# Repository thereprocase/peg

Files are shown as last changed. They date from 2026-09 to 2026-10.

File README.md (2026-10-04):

# Pegboard connectors and holders

**[Get the current peg downloads](https://thereprocase.github.io/peg/)** — native hook, hoop and bearing-locator CAD with a flat mounting reference and a **2 mm joining nub, +20% diameter**. Six individual connectors and pre-spaced pairs use the current PF02 #9 / PF07 #5 fit. Their functional board-side shapes are unchanged.

| Download | Intended use |
|---|---|
| [STEP pack](https://github.com/thereprocase/peg/releases/download/peg-connectors-v1-2026-10-04/pegs-current-fit__v1__nub120__step.zip) | Native solids for Fusion, Onshape and other solid modelers |
| [FreeCAD pack](https://github.com/thereprocase/peg/releases/download/peg-connectors-v1-2026-10-04/pegs-current-fit__v1__nub120__FCStd.zip) | Native solids and named holder datum planes |
| [All formats + construction source](https://github.com/thereprocase/peg/releases/download/peg-connectors-v1-2026-10-04/pegs-current-fit__v1__nub120__all-formats-and-source.zip) | STEP, FCStd, BREP, IGES, STL, OBJ and geometry-only 3MF |

Align the flat shoulder at **Y = 0.15 mm** to the holder's rear plane, embed the nub toward **+Y**, and Boolean union it into the body. Nub diameter is **6.72 mm** on the upper hook and **7.62 mm** on the lower parts. All dimensions are millimeters. Native solid exports preserve arcs and surfaces; STL/OBJ/3MF are separate tessellations. [Full integration notes](docs/pegs/integration.txt) · [Native build and validation](bench/reviews/peg-connectors-v1/BUILD.json).

**[Browse all 44 holder designs](https://thereprocase.github.io/peg/gallery/current-pegs/)** · [New bench designs](https://thereprocase.github.io/peg/gallery/current-pegs/?family=new) · [36-hole screwdriver remix](https://thereprocase.github.io/peg/gallery/current-pegs/#P09-36) · [Current fit / printing rules](BENCH_HOLDERS.md).

The original nominal anchor study is preserved below and on its [own page](https://thereprocase.github.io/peg/anchor-study/). Its movement certificates do not cover the current interference-fit connectors or complete holders. The new exports pass native solid round-trips, unchanged board-side geometry checks and sample host unions; physical fit and loads depend on the finished print and board.

---

# Original nominal conformal anchor study

A reusable rear attachment for holders, bins and brackets on **6.35 mm (1/4-inch) holes at 25.4 mm (1-inch) pitch**. Both pegs match the bore's lower curve over **120 degrees**. The lower peg bears through the full **3.94 mm board thickness**. A sharp **5 mm nominal lip above the upper hole center** sits flush against the board; taller attached parts can take any shape inside the supplied movement envelope.

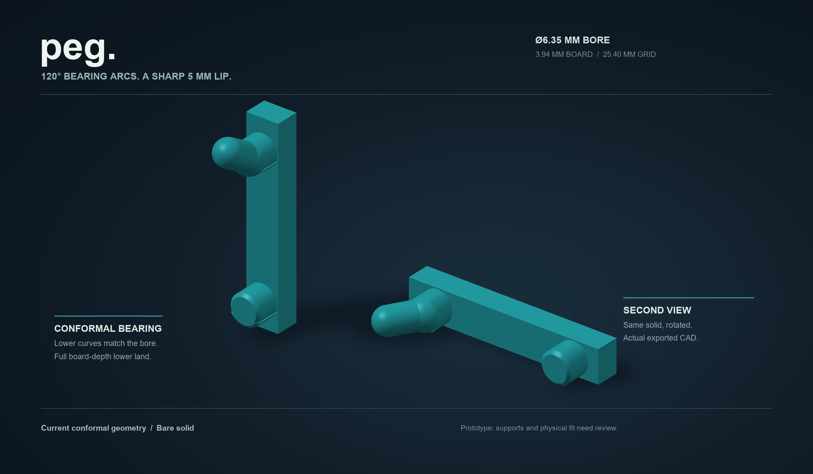
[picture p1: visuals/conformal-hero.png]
Current conformal anchor, rendered from the exported CAD


**Start with the [functional STEP](cad/conformal/conformal_120.step?raw=1) and [allowed host volume STEP](cad/conformal/host-envelope/allowed_host_volume.step?raw=1).** Import them together to build an attached part. The current geometry has its own continuous movement verification and independent solid-model checks. Its bare meshes are inputs for print preparation; supports, slicing and physical fit still need qualification.

## Current downloads

| Use | File | Contents |
|---|---|---|
| Integrate the attachment into CAD | [Functional STEP](cad/conformal/conformal_120.step?raw=1) | One solid in anchor design coordinates |
| Define the attached part's permitted shape | [Allowed host volume STEP](cad/conformal/host-envelope/allowed_host_volume.step?raw=1) | Reference volume derived from this anchor's movement; do not print or fuse the volume |
| Prepare a side print | [Bare side STL](cad/conformal/conformal_120_side_unsupported.stl?raw=1) | Functional geometry in side orientation; needs a checked support strategy |
| Prepare an upright print | [Bare upright STL](cad/conformal/conformal_120_upright_unsupported.stl?raw=1) | Functional geometry in upright orientation; needs a checked support strategy |
| Inspect without reorientation | [Design-coordinate STL](cad/conformal/conformal_120_design_unsupported.stl?raw=1) | Mesh aligned with the STEP and host envelope |
| Change procedural dimensions | [conformal_anchor.py](conformal_anchor.py) | CadQuery source, geometry contract and exporters |

## Bearing geometry

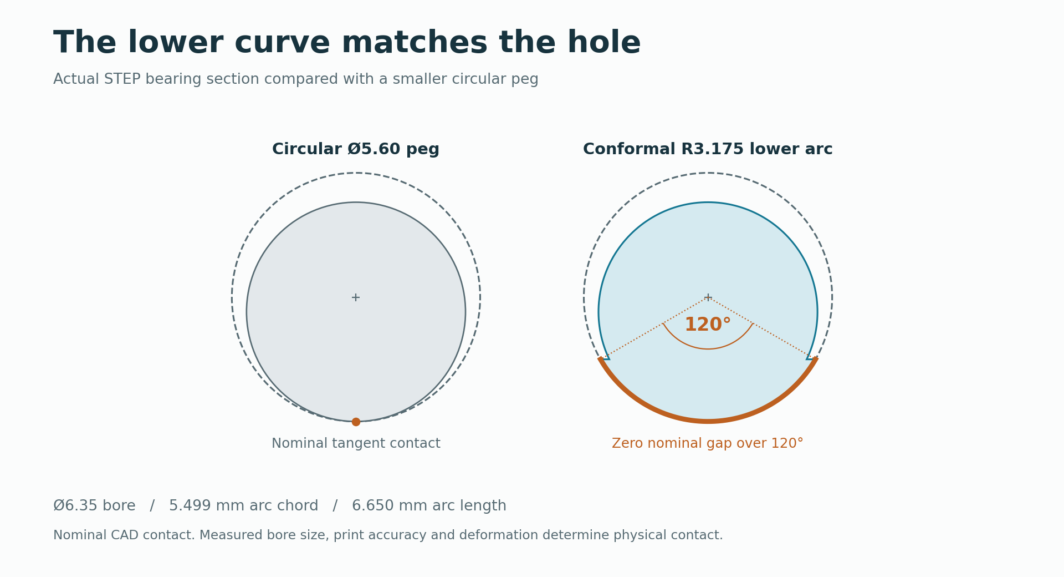
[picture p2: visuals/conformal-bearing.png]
Circular and current bore-matching bearing cross-sections


Each peg has an actual **3.175 mm-radius cylindrical arc** along its bottom. When seated in the nominal bore, the curved bearing surfaces coincide over 120 degrees. The upper circular core and smaller retaining tongue provide the threading geometry.

| Feature | Current default |
|---|---:|
| Actual board thickness / hole diameter / pitch | **3.94 / 6.35 / 25.4 mm** |
| Conformal bearing radius / arc coverage | **3.175 mm / 120 degrees** on both pegs |
| Upper conformal bearing length | **3.158095 mm** |
| Lower conformal bearing length | **3.94 mm**, full board thickness |
| Lower nose beyond the rear board face | **0.50 mm** axial chamfer |
| Lower total projection from the installed board front | **4.44 mm** |
| Upper circular core / retaining tongue diameter | **5.60 / 4.80 mm** |
| Front spine width / design-coordinate fusion face | **6.00 mm / Y = 4.50 mm** |
| Nominal flush lip above the upper hole center | **5.00 mm** |
| Board-facing corner radius | **0 mm**, sharp planar seam |

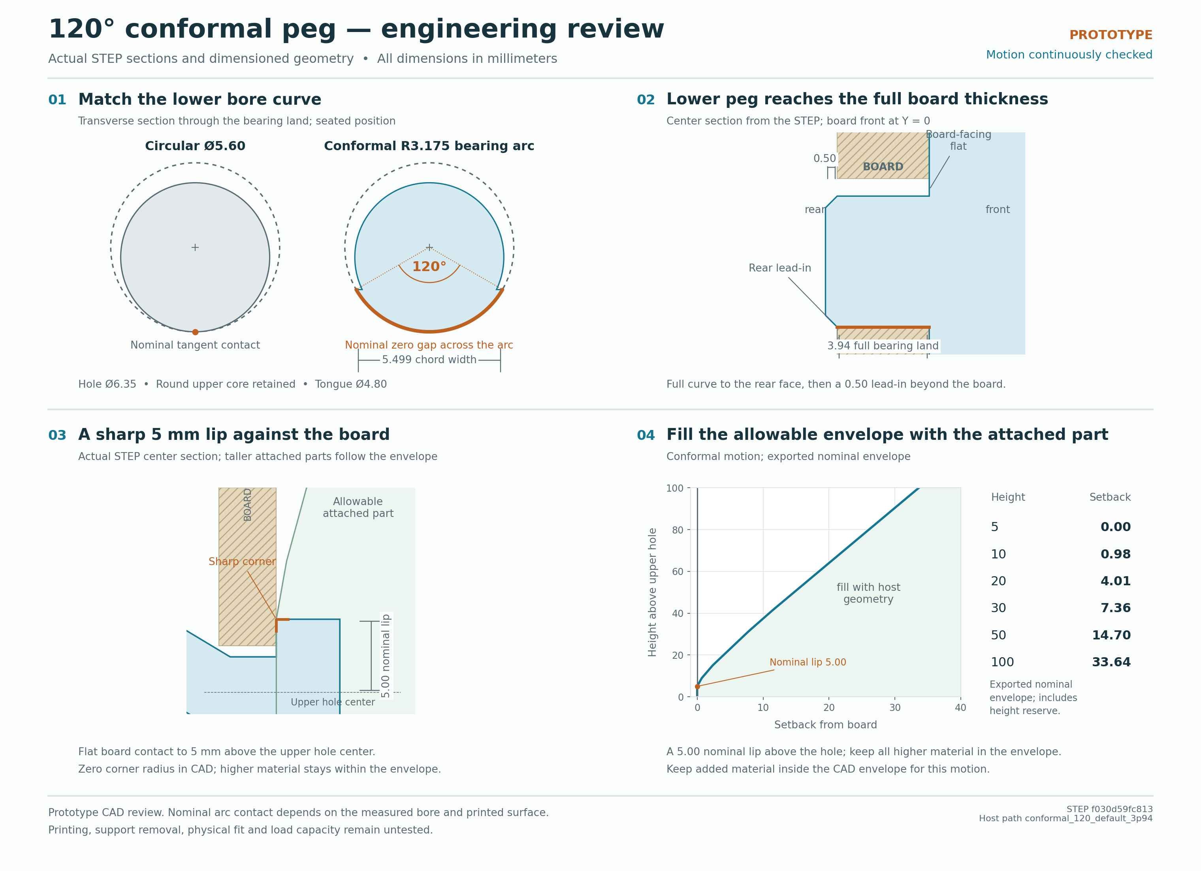
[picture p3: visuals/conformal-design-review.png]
Current dimensioned anchor and host interface


The upper conformal land stops at the retaining bend to permit the verified insertion. The lower peg spans the whole board: its 0.50 mm nose begins beyond the rear face, after the full bearing land.

The lower land's nominal mating area is **26.20 mm2**. This is geometric area, not measured contact pressure or a load rating. Exact full-arc contact depends on the real bore, printed surface and deformation. Measure board thickness and several holes before preparing a fit sample. Other board sizes require their own geometry and movement checks.

## Integrate with custom parts and models

The 5 mm dimension is measured **above the upper hole center**, not above the peg's crown and not from the bottom of the holder. It defines the nominal maximum height of a board-flush rear face. Above it, move the back of the attached part forward according to the allowed volume. A tall tool holder can use a step, slope, ribs or any other shape that fits.

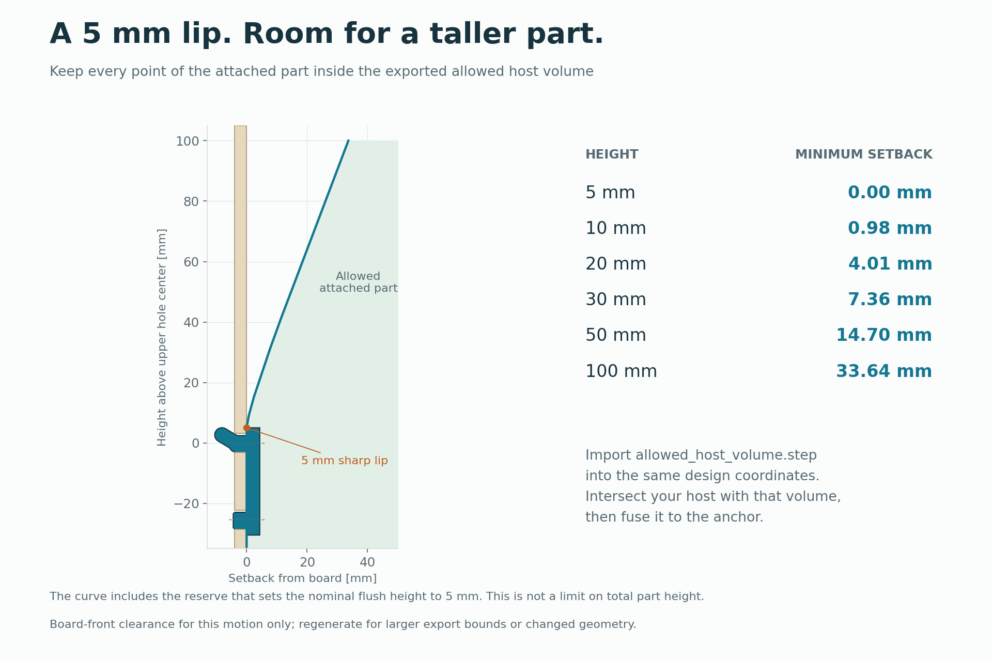
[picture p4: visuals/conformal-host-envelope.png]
Allowed attached-part volume and required setback above the sharp lip


Import the two STEP files in the same coordinates. Create the added host entirely inside the allowed volume, then fuse it into the anchor's front spine with real shared volume. Include all added ribs and fasteners in the containment check. The anchor's own pegs intentionally lie outside the host envelope.

The supplied reference volume spans **X = -50 to +50 mm**, installed height **-80 to +100 mm**, and front projection **60 mm**. These are export bounds, not a limit on the mathematical interface; the generator accepts larger bounds. The envelope checks the complete board front throughout the same movement as the peg. It does not account for neighboring holders, rear walls or hand access.

All dimensions are millimeters. **X** runs across the board, **Y** points toward the user, and **Z** points up. The board front is **Y = 0**; its hole centers are **Z = 0 and -25.4 mm**. In the supplied CAD, the spine's front fusion face is **Y = 4.50 mm**, the board-facing back is **Y = 0.15 mm**, and the nominal lip is **Z = 5.12 mm**. The seated assembly translates **Y = -0.15 mm, Z = -0.12 mm**, with zero rotation.

In Fusion, Onshape or another solid modeler:

1. Import the functional STEP and allowed-volume STEP without moving either independently.
2. Model the added part inside the allowed volume. Above the 5 mm lip, follow the rear setback boundary. Extend the part into the spine's front face with real overlap; 0.3 mm is a useful Boolean construction starting point.
3. Check that subtracting the allowed volume from the added part leaves no material, then union the host and functional anchor. Keep the reference envelope out of the finished model.
4. Inspect the complete assembly along the supplied motion and confirm clearance from nearby objects. Use the seated transform when checking its final position on the board.

For procedural CAD, this complete example clips a tall host blank to the allowed volume and fuses it to the default anchor:

```python
import cadquery as cq
from conformal_anchor import make_conformal_anchor

anchor, geometry = make_conformal_anchor()
allowed = cq.importers.importStep(
    'cad/conformal/host-envelope/allowed_host_volume.step'
)
# 24 mm wide, 24 mm deep, 65 mm tall; starts at design Y = 4.2 mm.
blank = cq.Workplane('XY').box(24, 24, 65).translate((0, 16.2, 2.5))
host = blank.intersect(allowed)

outside = host.cut(allowed)
assert sum(s.Volume() for s in outside.solids().vals()) < 1e-6
assembly = anchor.union(host)
assert assembly.val().isValid() and len(assembly.val().Solids()) == 1
cq.exporters.export(assembly, 'my_holder.step')
```

Replace the blank with your own model, using the envelope to check or shape its back. To change peg dimensions, pass a parameter dictionary such as `make_conformal_anchor(overrides={'board_thickness': 4.19})`; regenerate and verify that geometry's movement and host envelope before using it. The supplied certificates cover the default dimensions only.

See [HOST_INTERFACE.md](HOST_INTERFACE.md) for the exact movement-dependent height ceiling, containment rule and regeneration options.

## Installation and removal

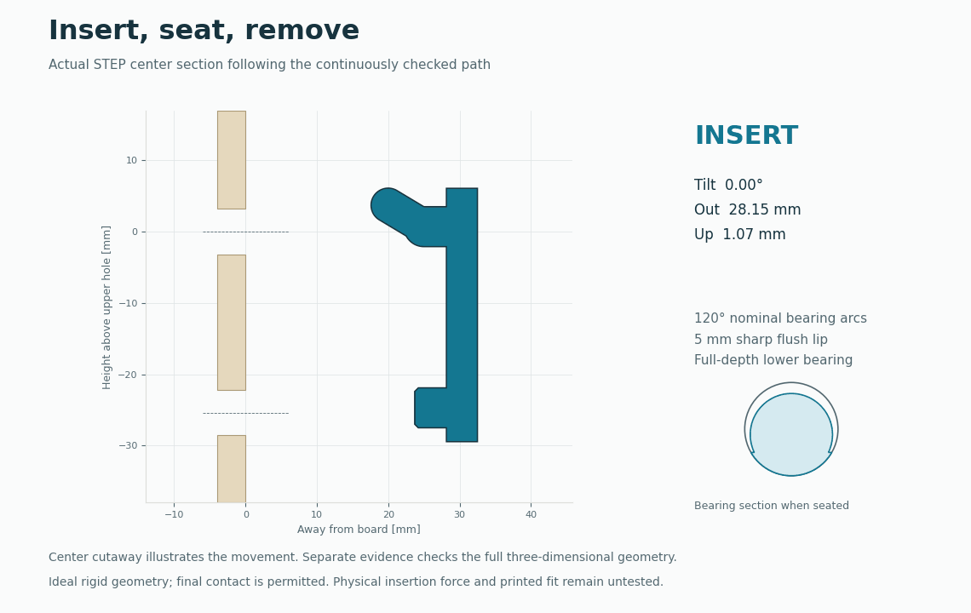
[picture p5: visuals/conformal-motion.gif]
Insertion and removal using the current CAD and certified pose sequence


Thread the upper tongue while tilted, rotate the holder toward the board as the lower peg enters its hole, then close the intended bearing contacts. Removal reverses the same path. The maximum installation tilt is **20.875 degrees** and the reference-point lift is **1.07 mm**.

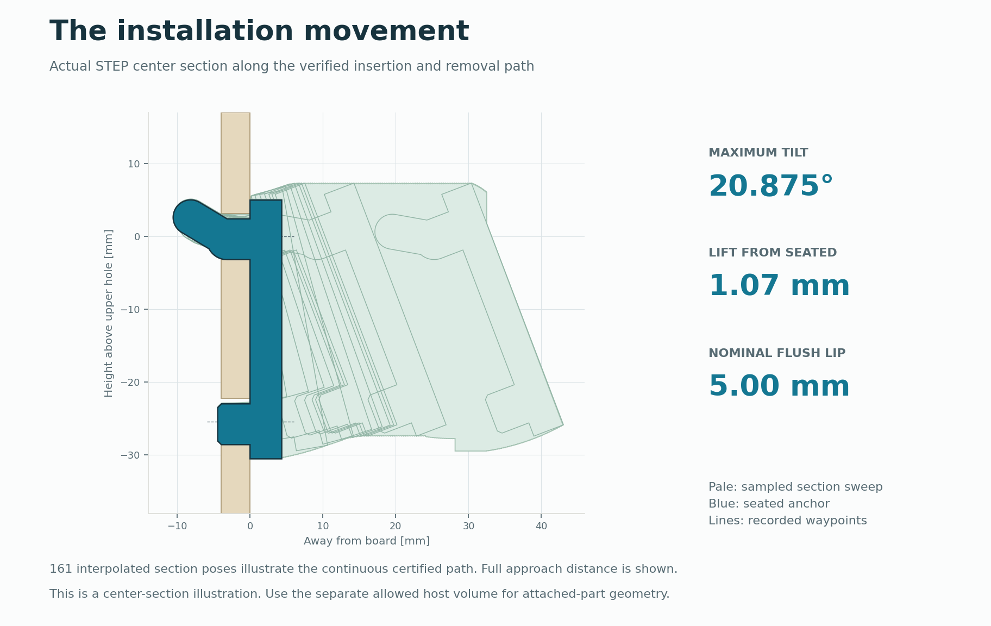
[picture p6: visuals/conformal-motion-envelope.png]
Projected swept shape of the current installation motion


The [movement study](CONFORMAL_STUDY.md) certifies **12 waypoints** with **168 continuous interval certificates across 10 free-motion segments**, plus **one exact final-contact translation**. The bounds use 768 X slabs per half for the curved additions. An independent OpenCascade audit of the exported solid found **zero overlap at 400 path poses**, including seating. The animation follows the certified pose sequence.

The current proof uses the **physical nominal bore** and permits the intended seated contacts. It reserves no additional radial bore clearance. The result establishes ideal rigid geometry clearance; actual printed fit and insertion feel need a physical sample. No load, fatigue, creep or support-release rating has been established.

## Print preparation

The current side and upright STLs contain **only the functional anchor**. Build and check supports for the selected orientation and the complete attached holder. The projecting tongue and full-depth lower peg need a support strategy that preserves their functional surfaces.

Use the intended printer and filament profile, inspect the first appearance of each projection and the bearing surfaces, then print one fit sample. Preserve the 120-degree bearing curves and sharp board-facing seam when removing supports. Fit trials and a representative holder test are the next qualification steps.

## Sources and evidence

| Record | What it establishes |
|---|---|
| [Resolved geometry](cad/conformal/conformal_120_geometry.json) | Dimensions and exact construction used by the CAD and motion checker |
| [Exported bearing-face check](cad/conformal/conformal_120_bearing_check.json) | Measured radius, 120-degree coverage and bearing lengths from STEP |
| [Solid and mesh validation](cad/conformal/conformal_120_cad_validation.json) | One valid solid and watertight, positive-volume meshes |
| [Continuous motion](cad/conformal/conformal_motion_results.json) | Input hashes, poses, interval certificates and final-contact proof |
| [Independent STEP intersections](cad/conformal/conformal_motion_check.json) | Sampled solid-model interference checks |
| [Allowed-volume certificate](cad/conformal/host-envelope/allowed_host_volume.json) | Host boundary, export bounds and continuous board-front clearance |

Use the [Python requirements](requirements.txt) or an already available compatible CAD runtime; the validation record identifies the versions actually used. Rebuild the current geometry and its dependent evidence in this order:

```text
python conformal_anchor.py
python check_conformal_geometry.py
python conformal_motion.py --certify --slabs 768 --max-seconds 180
python verify_conformal.py --candidate-poses 400 --max-seconds 600
python host_envelope.py --motion cad/conformal/conformal_motion_results.json --output cad/conformal/host_envelope.json
python export_host_envelope.py --motion cad/conformal/conformal_motion_results.json --output cad/conformal/host-envelope --nominal-lip 5
python render_conformal.py
python render_conformal_media.py
```

[HANDOFF.md](HANDOFF.md) records source ownership and publication checks. [research.md](research.md) records the board-size research.

## Graveyard

[Previous round release and its supported 3MF](ROUND_README.md) / [rectangular baseline](BASELINE_README.md) / [design history](DESIGN_HISTORY.md). Their CAD, supports and evidence belong to those older shapes.

## Project website

[Open the Conformal pegboard anchor site](https://thereprocase.github.io/peg/) for previews, setup and project resources. [Browse all project groups](https://thereprocase.github.io/).

The static site lives in `docs/` and uses the shared [Gridline design system](https://github.com/thereprocase/thereprocase.github.io/blob/main/GRIDLINE.md). Edit `docs/index.html` and `docs/site.js`; shared styles live in `docs/gridline/`. GitHub Pages serves `main:/docs`.

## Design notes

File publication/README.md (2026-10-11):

# Publishing the curated gallery

Canonical public front page: https://thereprocase.github.io/peg/
Current holder collection: https://thereprocase.github.io/peg/gallery/current-pegs/
GitHub Pages builds `main:/docs`. `docs/gallery` contains the static gallery, local scripts and 3D media. CAD STEP/FCStd, ZIP bundles and 3MF print jobs are GitHub Release assets. `release-downloads.json` maps original relative paths to immutable release URLs, including compatibility aliases; `release-assets.json` records exact SHA256 and size.

Preserve four groups, tombstones, Pegstr credit, model-specific limitations, explicit part/version filenames and private-data exclusions. This migration imported ONLY the previous public allowlist, recorded in gallery-source-manifest.json. No votes, photos, databases, credentials, workspace history or machine caches were imported.

For the next model: generate/review locally, stage only its approved public additions, upload versioned binary downloads to a new release, update the scoped gallery page, `release-downloads.json` and the matching `docs/gallery/release-downloads.js` map, run `python tools/check_gallery.py`, review the diff and push. Verify Pages and real downloads before changing links on another host. Never rerun the retired PVE publication scripts.

Offline: clone/download this repository and serve `docs` with a local static server for 3D. Pages and renders are local; release downloads require internet. Model/source ZIPs remain self-contained and unchanged.

Warpbus now keeps legacy redirects only, following GitHub verification. Historical immutable Warpbus snapshots are rollback evidence, not the publishing target.

## October 4 current-mount collection

`bench/reviews/gallery-current-mounts-flat-top-v2/SELECTED.json` selects 38 mounted gallery bodies: 19 planar-top Pegstr/arrays and 19 other holders with per-part poses. `verify_selection.py` validates the frozen source, native exports and checks. Do not regenerate frozen exports just to package them; native serialization hashes may change. P06 uses its bounded mesh-export adapter.

`prepare_current_pegs_media.py --selection SELECTED.json` converts the selected installed/print meshes to GLB. `build_current_pegs.py BUILD_DIR RELEASE_DIR --selection SELECTED.json --tag RELEASE_TAG --generation-source-map SOURCE_MAP.json` packages 114 native/source release assets and writes the catalog, receipts and redirect map. The generation-source map is local build state; the ZIPs preserve exact execution code and public provenance. Each bundle retains its true original input suffix, any original STEP/STL ancestry, the shared fit snapshot, native CAD, meshes and review evidence.

Run `python3 tools/check_gallery.py`, check the actual mobile/desktop viewer and both poses, review scoped staged paths, refresh `release_manifest.json`, upload immutable release assets, then publish the matching Pages commit. No current G-code or sliced job is included. Historical loose parts and print jobs remain in their original galleries. Print support/toolpath and changed-fit physical qualification are separate from the recorded CAD checks.

## Featured connector downloads

The front page features six current-fit connector/pair variants with +20% diameter, 2 mm holder-side joining nubs. `bench/source/peg_connectors_v1/build.py` constructs native solids and datum planes from the unchanged fit snapshot. Native STEP/BREP/IGES round-trips, unchanged board-side geometry and a sample host union are checked during generation. IGES topology is sewn for its solid comparison. Meshes are tessellated directly from the native solids without mesh repair.

`build_peg_downloads.py RELEASE_DIR` packages STEP, FCStd, BREP, IGES, STL, OBJ and geometry-only 3MF, plus all-format/source bundles. Native exports remain GitHub Release assets; `docs/pegs` holds the catalog, display GLBs and integration notes. `peg-connectors-v1-additions.json` records release/local receipts. Run `tools/check_peg_downloads.py` (also included in the gallery check) and review the actual front-page viewer before publishing. The original nominal study stays at `/peg/anchor-study/`; its CAD and certificates are unchanged.

## Workbench previews

`docs/viewer/workbench.js` applies four-band cel shading, a bright workbench background and soft ground shadows to the interactive viewers. The adapter uses the pinned model-viewer build's `correlatedObjects` material set and scene render request; verify these hooks when upgrading that vendor bundle. CAD, GLB geometry and downloadable materials retain their original bytes.

`render_workbench_previews.cjs` regenerates the current collection's installed, print and thumbnail PNGs from the same shader. Serve `docs`, set `PEG_PREVIEW_URL` to that server, and run with Playwright available via `PLAYWRIGHT_MODULE` and Chromium via `CHROMIUM_PATH`. Refresh the current-pegs receipts after rendering. Check viewer material application and browser/WebGL errors across model swaps before publishing.

CF01 v3 is a Repro bespoke catalog entry in `current-pegs` (solder-modules family). `add_cascade_to_collection.py` registers its slim-web revision, reviewed media, downloads, notes and front-facing camera. Apply it after rebuilding the base collection, then render only this entry with `PEG_PREVIEW_IDS=CF01` using `render_workbench_previews.cjs` and refresh the collection receipts. The standalone cascade page remains the detailed review linked from the catalog entry.

HX02 v1 is the full-depth 30-degree metric hex-key rack in Repro bespoke. `build_canted_hex_keys.py` publishes its matching model, evidence and catalog entry; `package_canted_hex_keys.py` packages native CAD and exact sources. Render its catalog previews with `PEG_PREVIEW_IDS=HX02`, refresh the collection receipts, and run the gallery checks before publishing.

HX02 v2 (graduated organ-pipe hex-key rack) replaces v1 on the canted-hex-keys page and in the Repro catalog; v1's print STL and CAD release stay linked as history. `bench/source/canted_hex_keys_v2/build.py` builds it (FreeCAD 1.1 with scipy; `--quick DIR` writes review meshes only), then `review.py`, `install_screen.py`, `stiffness.py`, `slice_local.py` (Windows OrcaSlicer, flattened system P1S/0.20 mm presets plus the owner's PolyLite ASA ReproCal filament) and `toolpaths.py` write the evidence. `build_canted_hex_keys_v2.py` publishes page, catalog and receipts; `package_canted_hex_keys_v2.py` makes the release bundle (`canted-hex-keys-v2-2026-10-07`). Render catalog previews with `PEG_PREVIEW_IDS=HX02` and refresh the receipts; `tools/check_canted_hex_keys_v2.py` runs from the gallery check.

HX04 v1 (three-tier key fan: hex L-keys back, Torx middle, Bondhus T-handles front) is a new Repro bespoke entry with its own page, `docs/gallery/key-fan/`. `bench/source/key_fan_v1` holds the layout study (`study/short.py`, final layout `short_dt_c2.json`) and the FreeCAD 1.1 model (`build_short.py`). Run it with the build env recorded in `report.json`. `check.py` (exact storage and withdrawal), `fea_run.py`, `coupon.py` and `tools/run_candidate.sh` write the evidence; `tools/evidence.py` collects it into `bench/reviews/key-fan-v1/HX04`. `build_key_fan.py` publishes the page, catalog entry and receipts. `package_key_fan.py` makes the release bundle and the solid-zone 3MF project (`key-fan-v1-2026-10-08`). Render catalog previews with `PEG_PREVIEW_IDS=HX04` and refresh the receipts; `tools/check_key_fan.py` runs from the gallery check. The fit coupon STL ships on the page; no G-code is published.

HX04 v2 replaces v1 on the key-fan page and in the Repro catalog. It puts a peg in every hole the plate covers: PF02 #9 hooks across the top row, PF07 #5 locking hoops across the bottom row and lower bearing pegs between, 90 in all, on the reviewed 5.4 mm wall (`receiver_grid` in `build_short.py`). The solid-infill zones are now braces: socket row webs, socket bulkheads and peg-root discs. `swing.py` adds the sampled install-swing evidence. Build v2 evidence with `HX4_VERSION=2 tools/evidence.py`, publish with `build_key_fan_v2.py` and package with `HX4_VERSION=2 package_key_fan.py` (`key-fan-v2-2026-10-08`). v1's print STL stays on the page and its bundle on the v1 release; `tools/check_key_fan.py` checks v1 as history and `tools/check_key_fan_v2.py` the current model.

The extended HX04 audit is separate from the immutable v2 geometry: `bench/source/key_fan_audit_v1/`, `bench/reviews/key-fan-audit-v1/` and `docs/gallery/key-fan/studies/`. `build_report.py` builds numerical tables and scientific plots from completed receipts. `publish_key_fan_audit.py --out RELEASE_DIR` verifies the completed-film archive, packages public sources/fields/native CAD, updates immutable downloads and applies the scoped page/catalog overlay. The base v2 publisher calls this overlay last. Preserve the original v2 artifacts and failed-run disclosures. Run `tools/check_key_fan_audit.py` and the full gallery check, inspect actual desktop/mobile renders, refresh the root manifest, and verify release payloads and live Pages. Printer jobs and private settings remain outside publication.

## Final straight-socket racks

The selected green Bondhus 13190 fan also has an editable native FreeCAD handoff at `/gallery/key-fan/stacked/green/#parametric`. `bench/source/hx05_parametric_v1` contains its stdlib-only feature module, one-time setup macro, document builder, edit/reopen tests and release packager. Two spreadsheet sheets drive the fan geometry; the approved rear mount stays fixed. `package.py WORK_DIR` packages tested files and receipts; the green publisher reapplies `publish_download.py` so the download section survives regeneration. CAD binaries remain immutable release assets. Parameter edits invalidate the previous layout/printing evidence.

`bench/source/final_racks_v1` builds the revised owner fan and three single-set Bondhus racks. Owner-selected 3C/5C clearance is +0.38 mm total AF; other sizes remain provisional. Saved final layouts, native checks, separate lead-ins and vent passages replace the flared seats. `publish_final_racks.py --build BUILD_DIR --out RELEASE_DIR` packages exact native/source downloads and publishes `/gallery/key-fan/final/` (also `/final/`). `render_final_racks.cjs` renders all three poses with the shared workbench shader. Refresh its scoped receipts after rendering. `check_final_racks.py` is included in the gallery check. Historical models/audit stay intact; no previous FEA or installation certificate transfers.

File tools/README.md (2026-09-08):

# Reproduce the toolpath evidence

These scripts preserve the actual September 2026 analysis used for `SLICER_CHECK.md`. They replace the original temporary `analyze_gcode.py`, `final_review.py`, and `slice_variant.py` with command-line inputs and no import-time execution. The underlying extrusion-width reconstruction, buffered line-envelope union, inspection layers, and 0.20 mm prior-layer reach match that work. No slicer binaries or GCode are included.

Python dependencies: `shapely`, and `matplotlib` when rendering a plot. Python 3.10 or newer is required. The historical run used CuraEngine 5.0.0 and Cura 5.0.0 generic definitions; exact Ubuntu package versions and every explicit settings input are in `../slicer_check.json`. `../SLICER_CHECK.md` explains their limitations.

From the repository root, with your own executable and definition paths:

```bash
python tools/slice_toolpaths.py \
  --engine /path/to/CuraEngine \
  --definitions /path/to/cura/resources/definitions \
  --output /tmp/peg-toolpath-review \
  --include-five-wall-trial

python tools/analyze_toolpaths.py \
  --side /tmp/peg-toolpath-review/side_REVIEW_ONLY.gcode \
  --upright /tmp/peg-toolpath-review/upright_REVIEW_ONLY.gcode \
  --output /tmp/peg-toolpath-evidence
```

If a locally extracted engine needs shared libraries, point `LD_LIBRARY_PATH` to that installation's library directory before running. Use the engine's matching definitions. The slice script records each exact command and engine log beside its scratch GCode. It never communicates with a printer.

The analyzer assumes absolute XYZE moves, 1.75 mm filament, uniform 0.20 mm layers, and a 128 mm XY translation from the generic 256 mm bed. CLI flags expose these values. It rejects relative-mode GCode. It analyzes positive-extrusion G0/G1 moves and excludes Cura's `SKIRT` feature, which also labels these brim lines. It is not a general GCode interpreter: volumetric extrusion, arcs, variable layer height, or firmware transformations require extending the parser.

Deposited bead width equals filament volume divided by XY path length and layer height. The analysis buffers each path by half that width, joins the envelopes, closes 0.01 mm numerical gaps, and looks for whole components larger than 0.01 mm² that miss the previous layer expanded horizontally by 0.20 mm. This catches fully detached components, not unsupported portions of connected components. It does not establish bridge sag, thermal performance, adhesion, collision freedom, machine readiness, or load capacity.

The default web and roof inspection layers refer specifically to the shipped 3.94 mm board model: webs at layers 8/10/12 and 115/120/125/130; lower and upper roofs at layers 15 and 140. The plots inspect layers 8/15/120/140. Geometry or layer-height changes require selecting new layers and coordinate bands. The analyzer emits raw sample segments and reconstructed widths rather than hard-coding a passing result. Use those segments and the layer preview to inspect bridge directions and changes.

Historical results: side 20 layers; upright 173 layers; one connected first-layer model footprint in each; no wholly detached components under the stated envelope check; approximately 0.500 mm sampled web extrusion width. With the upright two-wall settings, sampled first-roof skin runs across X. The five-wall comparison consumes the narrow roof with nested perimeters. Prefer a local two-wall/solid-line-fill modifier for that upright region, inspect your slicer's roof paths, and keep the side orientation as the stronger starting point.

The archived summary includes manually interpreted conclusions from these observations; the reconstructed JSON retains raw evidence to reassess them. Review GCode is intentionally outside the repository and is not a machine-ready P1S profile.

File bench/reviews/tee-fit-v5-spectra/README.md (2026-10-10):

# Fit spectrum v5 — three connected five-slot coupons

Print the supplied flat bases without auto-orienting. Each coupon has five six-flat bores labelled with its size and A–E, full straight guides, a separate 0.8 mm entrance and a square 3 mm floor with a 1 mm through vent.

| Letter | Clearance per flat | Total across flats |
|---|---:|---:|
| A | 0.10 mm | 0.20 mm |
| B | 0.15 mm | 0.30 mm |
| C | 0.19 mm | 0.38 mm |
| D | 0.23 mm | 0.46 mm |
| E | 0.28 mm | 0.56 mm |

C matches the latest requested allowance; A matches the snug v3 target. Guides are 40 mm for 3 and 5 mm, 56 mm for 7 mm. The 3E bore allows full rotation geometrically. Choose the smallest clearance that seats fully and removes comfortably without forcing, then compare rocking and rotational play. Report **3 mm = _, 5 mm = _, 7 mm = _** after physical testing; no best letters have been established.

The rack prints on its left end. These bores retain the corresponding horizontal shaft and hex-flat orientation relative to the bed: 3 mm uses lower-tier grip turn 90 degrees, 5 mm uses upper-tier 65 degrees. 7 mm uses the upper-tier orientation as a trial because 7 mm is not in Bondhus set 13189. All have 20 degrees of heading in the bed plane, corresponding to the installed rack's forward tilt. Source flags independently set grip roll and bed heading.

```bash
.local-runtime/freecad-python bench/source/tee_racks_v1/fit_spectrum_v5.py --out bench/reviews/tee-fit-v5-spectra --angle-3 90 --angle-5 65 --angle-7 65 --heading 20
.local-runtime/freecad-python bench/source/tee_racks_v1/tools/check_fit_spectrum.py bench/reviews/tee-fit-v5-spectra
```

Individual STL/STEP files contain one connected coupon. The `three-spectra` files and FreeCAD document contain all three arranged separately on one plate. FreeCAD properties are metadata; rebuild the source to change the geometry.

Use the owner's actual printer/filament profile and calibrated compensation. Inspect horizontal roofs, supports, vents and toolpaths before printing. Native insertion, floor/vent, rotational-stop and export checks pass. Slicing and physical selection remain pending. This box has no configured printer connector or local owner-profile slicer, so **no overnight job has been submitted**. No G-code is published. The earlier complete racks retain their previous fit geometry.

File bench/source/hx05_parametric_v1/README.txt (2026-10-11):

HX05C / Bondhus 13190 inch fan — editable native FreeCAD model

FIRST OPEN (Windows / Linux / macOS)
1. Extract the ZIP into an ordinary folder. Keep its files together.
2. In FreeCAD, use Macro > Macros > Execute, or open SETUP_HX05.FCMacro
   and run it (F6). Select the extracted folder if prompted.
3. Setup installs the small hx05_parametric module in your FreeCAD user
   Mod/HX05Parametric folder and opens the native FCStd document.
   It changes no printer settings and installs no external Python packages.
4. Save As a personal working copy. Future opens need only that FCStd;
   the installed module restores its editable features automatically.

EDITING
Double-click 01_GlobalParameters or 02_KeyLayout in the tree. Edit yellow
cells and press F5 (Recompute). Keep the initial '=' and mm/deg units in
expressions, for example '=0.48 mm' or '=12 deg'. Full rebuilds can take several minutes.
The parameters also appear read-only on the generated features so there
is one clear editing authority: the two sheets.

Global sheet:
  AF clearance: total across-flats difference, NOT clearance per side.
  Lead depth/opening, seating floor, vent diameter, base corner radius,
  gusset width per side, gusset extension toward the print bed.
  Minimum upward angle: default 10 degrees.

Key layout sheet, one row per inch key:
  Guide: straight shaft engagement (lead-in is additional).
  Up: true angle above horizontal, tip toward handle, in installed pose.
  Out: angle of the shaft away from the pegboard plane.
  Roll: rotation of the T-bar/hex around the shaft; 0 lies in the board plane.
  Tip XYZ: seated tip location. X is right, Y toward you, Z up, in mm.
  Outer radius: sleeve envelope; keep enough material outside the lead-in.
  Nominal AF, overall tool length and handle length: catalogue dimensions.

Up and Out are independent angle controls, subject to sin(Up)^2+sin(Out)^2<1.
The shaft points toward +X; these parameters describe this selected fan family.
Invalid angles, short guides or insufficient lead-in wall produce an error.
Restore the previous cell value and press F5. Do not export an errored document.

FEATURE TREE
ApprovedMount: fixed native rear plate and approved peg interface.
ReferenceTools: editable reference tool features; select and Space to toggle.
AdditiveFeatures: filled base, individual sleeves and tapered gussets.
CuttingTools: individual entrance reserves and socket/lead-in/vent cutters.
BooleanHistory: native FreeCAD union/entrance cuts and robust socket cuts.
FinalHolder: the finished solid. Select this object alone for STEP/STL export.
START HERE: an editing guide embedded in the FCStd.

The rear peg profiles, grid and plate outline are deliberately preserved as
one protected native feature. This package parametrizes the fan construction;
it does not redesign or certify the mounting interface. Changing the fixed
mount independently is possible in FreeCAD but requires separate review.

The custom features use only FreeCAD and standard Python. Source is supplied,
with no NumPy, SciPy, downloaded executable, network call or repository path
required at recompute time. The FCStd contains the actual CAD shapes, sheets,
expressions and feature links. Without the module it remains viewable, but
custom geometry cannot recompute until setup has been run.

VALIDATION / PRINTING
Default geometry is compared to the approved 9a9e695 native solid. The supplied
receipt records rebuild, save/reopen and parameter-edit tests and versions.
Changes invalidate previous tool/access/printing checks: inspect collisions,
clearance, inlet/vent access, bed size, supports and installation after edits.
The previous fixed-body slice needed a support blocker in the 9/64 socket.
This package is editable CAD, not a sliced printer job or a physical load rating.

DEVELOPER REBUILD
The source folder includes the frozen layout, document builder and edit tests.
To recreate the document, export FinalHolder as BREP for the approved reference,
then run create_document.py OUTPUT_DIR approved-layout.json REFERENCE.brep in
a FreeCAD Python environment with hx05_parametric.py on the module search path.
The builder extracts the fixed rear interface and rebuilds the fan features.
The included checks describe the tested FreeCAD version and validation scope.

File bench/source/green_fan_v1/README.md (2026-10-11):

# Green inch fan: gravity seating and broader fin roots

Current: v3 enforces 10° minimum installed shaft elevation and broadens
the fin roots in the print plane. See the v3 section below. Orca estimates
and support findings in this document belong to the preceding filled body.

The owner selected the green 13190 inch fan from the three-rack stack.
`reference-layout.json` freezes that published arrangement (a0e1056). Only the
inch rack changes; the metric and Torx racks retain their local geometry.

`arrange.py` increases every straight guide by 50%, from 40–76.2 mm to
60–114.3 mm. The 3 mm axial lead-in, 1.5 mm per-flat opening, +0.38 mm AF
clearance, square floor and 1 mm vents remain the same. Long-guide friction
and the other shaft sizes have not been physically qualified.

Each T-bar turns 30 degrees around its own shaft toward the pegboard plane.
This does not level the bar horizontally. Hex flat clocking follows the handle.
The main fan opens by an additional 0–15 degrees, in 2.5-degree increments,
keeping its staggered tip locations while allowing hand access with the flatter
bars. The 3/32 grip is checked at its opposite end; the symmetric bar and hex
have the same geometry when their direction vector is reversed. The 1/8 key
moves 18.12 mm sideways to clear the 5/16 release stroke. The final common
translation centres the receiver and sets the top hook row to zero.

The shared stacked-fan scripts calculate stack spacing, screen tool and hand
capsules, build native FreeCAD solids and check continuous axial socket-release
and front grasp sweeps against those solids. The earlier 50 mm grasp check remains as additional recorded clearance.
`pinch.py` independently checks two assumed 24 × 18 × 10 mm fingertip
pads at the frontmost end of every green-rack grip, including 3/32. Their
combined span around the 18 mm grip is 38 mm. Circumscribed convex hulls
bound both pads continuously during approach and axial release, tested against
all neighboring native tool and holder solids. This is not a whole-hand model.
The metric/Torx native solids may be reused only when all their tool parameters
match exactly; their assembly positions and layout hashes are regenerated.

```
python3 arrange.py BUILD
python3 ../stacked_fans_v1/spacing.py BUILD
python3 ../stacked_fans_v1/screen.py BUILD --saved
FreeCAD-Python build.py BUILD/tight-native
FreeCAD-Python print_pose.py BUILD/tight-native APPROVED_UNFILLED_BODY.brep
FreeCAD-Python ../stacked_fans_v1/verify_native.py BUILD/tight-native
FreeCAD-Python pinch.py BUILD/tight-native
FreeCAD-Python empty.py BUILD/tight-native
HX_FAN_BUILD_DIR=BUILD/tight-native HX_FAN_OUTPUT_DIR=BUILD/renders node render.cjs HX05C HX05C-empty HX05C-print stack
python3 publish.py BUILD
```

Native exports remain local review artifacts. The new page publishes renders
and numerical receipts. Subsequent free-hand removal, installation, printing,
supports and physical loads remain unqualified. No prior FEA result transfers.

The filled revision uses `strength.py`: a solid stock section with 8 mm
rounds in the print-bed XY plane (installed YZ), clipped beneath every socket
entrance. This connects the sleeve bending planes to a broad X-min foot.
A bounded 6 mm root-fillet operation succeeded at the longest eligible
backplate junction; the all-edge attempt did not succeed. Vents are extended
through the stock perpendicular to each shaft toward the front.

`print_pose.py` compares board-side geometry to the approved unfilled native
body from the 7c09b46 checkpoint, checks entrance/vent probes and exact flat
bed contact, then maps installed +X to printer +Z with 45 degrees of bed yaw.
It uses optimal bounding boxes because serialized trimmed faces can have
loose ordinary bounds. Native geometry remains nominal and unscaled.
The owner-profile Orca review, when recorded, is separate from these CAD
checks and from physical print qualification. No printer job is submitted.

The owner-profile Orca 2.3.2 review uses 0.20 mm layers, four walls, 35%
gyroid, five top/bottom layers, a 3 mm outer brim and bed-only organic
supports. ASA scale 1/0.9946 is applied once about the bed centre (Z about
zero), with filament shrink set to 100% in the flattened private profile.
The review archive estimates 57 h 32 min and 991.06 g, including supports.
Orca emitted repeated placeable-area diagnostics while generating organic
supports but completed export. This is not a qualified print job.

`toolpaths.py BUILD PRIVATE_GCODE OUTPUT_JSON` parses relative/absolute
extrusion and IJ arcs, screens sampled support centerlines against straight
hex socket cores and records feature/bounds totals. It excludes a 0.30 mm
wall margin, 0.50 mm end margins, funnels and vents; it is not a full bead
intersection or support-removal proof. Public receipts contain only review
settings, estimates, hashes and screen results. Machine profiles and G-code
remain private.

The review slice is NOT cleared for printing: 35 support moves enter the
9/64-inch socket core; the other nine cores have zero sampled hits. That
socket needs a support blocker and a new slice review. Aggregate extrusion
bounds can include machine sequences retaining the last feature tag and
are not a printable-area certificate. The geometry/renders are the delivered
review, not a released machine job.

## Gravity and broader fin roots (v3)

Every installed shaft must rise at least 10 degrees from the seated tip
toward the handle. The previous 3/8 key at 9.69 degrees is rotated to
10.5 degrees with its hex/bar frame. Other axes already exceed the floor.
The existing out-of-board splay is preserved: 11.5–21.1 degrees on green.
`print_pose.py` independently checks the actual tip-to-handle vectors for
all 26 keys, including their orthogonality to the T-bars.

Every green fin receives a convex tapered gusset with a root broadened
12 mm on each side in print XY (installed YZ) and extended 16 mm toward
the bed. Gussets stay within the receiver extents and below their own
entrance planes. Full lead-in prisms cut through any neighboring added
material. The native access/vent/entry checks are regenerated. The 8 mm base rounds
remain. The bounded 6 mm root-fillet attempts did not succeed on the wider
intersections, so these roots are tapered gussets without a claimed 6 mm
root fillet.

The current body recipe is `gravity-fin-gussets-v3b`. The Orca receipts
above are now named `previous-filled-*` and belong only to a3e68b3. This
revision is a native CAD/render review; a fresh slice with socket support
blockers is required before printing. No old estimate or toolpath check
is presented as evidence for this modified body.

Stock and gusset construction faces stop 0.05 / 0.10 mm below their
entrance planes to avoid coincident caps; functional bore and lead-in
dimensions are unchanged.

The scoped renderer softens the cel-band thresholds over 0.004 lighting
units to prevent speckle where a planar normal lies on a hard band boundary.
This changes preview shading only.

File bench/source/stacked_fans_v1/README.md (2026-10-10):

# HX05 stacked fan review

New construction study for Bondhus 33034, 13189 and 13190. The owner's HX04
fan and the previous final-racks-v1 downloads are unchanged.

The longer tools have independent axes and staggered floors. Each successive
floor starts 6 mm farther left and 5 mm lower, before direct clearance
placement. The three small keys tuck individually into available gaps. There is
no common fan centre. The small-key deck sits farther back (70 mm handle-centre
depth versus 125 mm for the main fan), keeping its shafts out of the main run.
The top hook row is the shared grid datum; the plate is sized to the socket
envelope rather than rounded outward by a full board row. The handle bars are perpendicular to their shaft axes.
Hex flats retain the handle's flat-to-flat clocking.

Three different clearance requirements apply:

* At least approximately 1 mm between represented steel shaft surfaces near the
  buried ends. This is NOT a 1 mm plastic wall. Socket clearance consumes part
  of this gap; the shared web widens where shafts diverge.
* Separate full lead-in mouths, with a 2 mm envelope spacing target. Each lead
  adds 3 mm axial length and expands 1.5 mm per flat/radius at the entrance.
* Axial socket release and a 50 mm diameter front-end grasp envelope must clear
  neighboring stored tools. This proxy does not represent every grip or hand.

Hex guides use +0.38 mm total across flats, physically selected only for the
owner's 3 mm and 5 mm coupon tools. Guide length is max(40 mm, 8 times shaft
size), plus the lead-in. The floor is 3 mm thick with a 1 mm vent. Torx uses a
circular catalogue tip envelope and remains provisional for fit and clocking.
Catalogue tool lengths/bars and an assumed 18 mm grip diameter are envelopes,
not manufacturer-measured tool surfaces.

`layout.py` and `pack.py` construct the reference arrangement from these rules. Each
possible contact gives a forbidden interval of vertical translation; merging
those intervals gives the nearest available position without an optimizer or
candidate campaign. `densify.py` compresses the frozen `reference-layout.json`
using the same contact intervals in rotated coordinate frames: each translation
stops before its first contact. The metric deck's two upper keys first move
into the nearest clear vertical gaps, retaining the middle key's low pocket.
Tool angles, fits and hand envelopes are unchanged. This is a deterministic
compact arrangement, not a global optimum. `spacing.py` derives separate
conservative separations on the 25.4 mm board grid, including nonadjacent pairs.
`screen.py` independently checks stored tools, withdrawal
and hand envelopes. Its fine sphere covers and translation padding give lower
bounds for the represented capsules and paths, not physical qualification.

`build.py` grows native FreeCAD solids around the saved layout. It reuses the
reviewed receiver geometry without altering board-side profiles. Extended
straight cutters also relieve any supporting web along the shaft's exit path.
Cached native solids require an exact match of every local tool parameter.
Changes only to rack translations regenerate the stack assembly and its layout
hash without rebuilding unchanged individual solids.
`verify_native.py` checks conservative continuous tool/hand sweeps against the
native bodies for that axial release and grasp approach. The subsequent free-hand
maneuver is not modelled; no uniform 2 mm guide-wall requirement is imposed at the tips.

Example local sequence (FreeCAD Python needs numpy/scipy/trimesh):

```
python3 densify.py BUILD
python3 spacing.py BUILD
python3 screen.py BUILD --saved
FreeCAD-Python build.py BUILD/tight-native
FreeCAD-Python verify_native.py BUILD/tight-native
FreeCAD-Python sections.py BUILD/tight-native
HX_FAN_BUILD_DIR=BUILD/tight-native HX_FAN_OUTPUT_DIR=BUILD/renders node render.cjs
python3 publish_review.py BUILD
```

`handles_preview.py` makes capsule envelopes for checking the arrangement
before native construction. Its meshes are never manufacturing geometry.

These are review models. Whole-host installation motion, physical fit at the
new print orientations, supports, thin-web printability, stiffness and load
capacity require separate qualification. No prior FEA or installation proof
transfers to this geometry. No G-code is generated or sent.

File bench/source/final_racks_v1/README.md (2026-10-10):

# Final straight-socket racks v1

Owner request, 2026-10-10: render and publish the complete owner fan and three single-set Bondhus racks as `/final/` models. The owner physically selected v6 coupon letters **3C and 5C**. Preserve historical HX04/HX05 geometry/evidence; this is a new source namespace.

Socket authority: `study/socket_policy.py`. Six straight flats at +0.38 mm total AF clearance, engagement max(40 mm,8× shaft size); separate 3 mm axial lead widened 1.5 mm per flat. T handle axis is flat-to-flat. Square stop shoulders and 1 mm vents: 3.5 mm axial floor passage joins an outward passage below the socket. Torx L-key guides use straight circular nominal blade envelopes; 33034 T-handles retain the inherited hex proxy, not measured Torx blade CAD. Other-size fit and Torx clocking are provisional. Small hexes can rotate at this clearance; long guides do not guarantee clocking.

Models: HX04 owner 26-tool three-tier fan (9 hex L,9 Torx L,8 graduated metric T handles); HX05A 33034 Torx; HX05B 13189 metric; HX05C 13190 inch. Catalogue overall/bar lengths for the latter sets are in `study/tee_sets_note.json`; grip thickness remains assumed. Three Bondhus racks are separate bodies, each with two staggered rows. Saved `study/*_final.json` layouts are authoritative. The fan adjusts L-key row positions to clear the longer guides, retaining T-handle shaft/clocking angles from the tested fan orientation. Nominal sampled screens pass; worst clock-play and native continuous motion remain separate.

## Build

FreeCAD 1.1 Python with numpy/scipy is required. Pinned FreeCAD 1.1.3 Linux runs locally; no owner Windows build is needed for native exports. From the repository root:

```
FREECAD_PYTHON=/path/to/freecad-python python bench/source/final_racks_v1/build_final.py --out OUTPUT
```

`--rack HX04` / HX05A / HX05B / HX05C selects one. Set FREECAD_PYTHON in the environment on Windows. Every subprocess has a timeout; two native builds run concurrently. `prepare_layouts.py` is the bounded selection search, not required to reproduce the saved model. `check_model.py OUT` reloads exported STEP and checks guide walls/clearance, vent passages, floor shoulders, nominal stored tools, meshes and native document. Run it with the same build environment recorded in `run.json`. `preview.py OUT DISPLAY` creates compressed, reduced browser previews with trimesh 4.11.2 / fast-simplification 0.1.13. Display reduction does not change CAD/print downloads.

Print STL is bare, unscaled, left-end pose. The aligned brace STL is a slicer modifier, not a physical second part. Apply owner filament compensation once and review support/toolpath/bed/brim clearance before printing. No profiles or G-code are included. Previous v2 FEA and installation evidence does not qualify these changed models; the old mounting approach's whole-body installation collision still needs resolution. Full-rack printing, installation, snap recovery and loads remain unqualified.

The owner fan additionally runs `refine_owner.py`: restore the complete guide walls cut by neighboring opening/vent corridors, then add below-floor lateral vent routes toward positive installed X (the print-bed end). The source base STEP is retained as an intermediate; download the refined final STEP. All nominal withdrawals are re-screened at 1 mm against the added material. `check_owner_model.py` verifies the new vents and exported walls. The three single-set bodies do not need this correction.

Use a fresh output directory. The owner pipeline also extends wall protection all the way to the floor and lead boundary (`complete_guide_walls.py`) and normalizes the FreeCAD document through the delivered STEP (`normalize_document.py`). `check_full_model.py` checks the whole straight guide for all four models; no bottom section is excluded from the wall check. Native document round-trips are independently recorded.

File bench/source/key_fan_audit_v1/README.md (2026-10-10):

# HX04 extended engineering audit

Read-only simulation work on the exact released v2 fan STEP, SHA256 `62a8acee8145f11967618944d6b4e0e2a54f3d96c428f3a197c91fc82f86798a`. The body has not adopted the new straight-guide fit. The requested overnight campaign covers native geometry, mesh/solver quality, mouth forces versus grip moments, fixture/material/load-distribution sensitivity, locking-hoop pinch, finer rigid tool withdrawal and full-host installation, plus actual computed deformation/motion films.

`fea_audit.py` is the initial recorded runner. `recover_summary.py` repairs only its final version-query receipt: the Linux CalculiX `-v` command returns 201 even though it successfully prints the version. It does not alter or rerun numerical solves. `fea_campaign.py` reuses independently gated meshes for material/load studies. Failed mesh/solver runs remain explicitly disqualified; do not change acceptance thresholds to make them pass.

`motion_audit.py` reads the released layout and extracts the unchanged native reference-tool functions by AST. This avoids importing unrelated mount generators; the original standalone v2 ZIP lacks some of those transitive dependencies. The review package supplements the source tree without modifying original geometry. Straightening uses rigid rotations and linearly interpolated tips; withdrawal is sampled at 1 mm. A sampled pass is not a continuous certificate.

`install_audit.py` checks front-host material omitted by the old rear-peg swing screen, and sensitivity to illustrative board/grid/part-scale variations. `install_candidate.py` examines outward-translated candidate swings, not qualified physical installation paths. `extract_hoop.py` and `hoop_fea.py` isolate the actual centre bottom hoop with a plate/root patch and impose controlled crest pinches. This is not an insertion-force or recoverability test.

`export_viewer_data.py` exports genuine solver displacements/stresses and tool references. Display-only field quantization has explicit bounded errors; full numerical statistics use the original solver values. `record_films.cjs` records the inked cel/stress viewer at prescribed phases and makes both GIF and WebM files. Magnification is stated in-frame; load ramps are static linear scaling, not transient dynamics. The first recorder/renderer revision is retained as capture provenance.

`repack_project.py` removes the historical pre-baked scale from the brace-project delivery by using the exact unscaled released meshes. The resulting 3MF contains no machine/filament profile or G-code. Apply the owner's compensation once when reslicing; this repack does not qualify the old fit or installation.

Run with Linux Gmsh 4.15.0, CalculiX 2.21 and Python/numpy/scipy; native checks use checksum-pinned FreeCAD 1.1.3/OCC 7.8.1. Solver 2.23 is an additional cross-check, not silently substituted evidence. Large raw meshes/decks/fields stay in the compute run directory; compact receipts, reproducible sources and display fields accompany publication. Never publish printer credentials, camera captures, private filament presets or machine-specific G-code.

The review ZIP is rooted as a repository: extract once, preserving `bench/` and `docs/`. The archived v2 recipe is `bench/source/key_fan_v1/build_short.py`; the `report.json` in `bench/reviews/key-fan-v2/HX04/` records its build environment/layout. The supplied `gallery_current_mounts_v1/station_snapshot/source/` tree restores transitive mount dependencies without changing the frozen build recipe. Large numerical meshes/decks can be regenerated from the included exact STEP using the audit runners; the browser fields are compact display derivatives, not replacement full stress output.

`remaining_h5.py` adds fresh refined face/corner grip fixtures. `probe_final.cjs` visits every field/tool in a real Chromium renderer, including mobile resize while paused. `hoop_nlgeom.py` compares geometric nonlinearity while retaining the same elastic material assumption. `modal_audit.py` examines five ideal solid-body vibration modes with explicitly assumed density; frequencies exclude tools, elastic board, infill, layers and damping. Neither analysis establishes a printed load or snap rating.

The review ZIP includes local film posters; its film videos link to the separate immutable release assets and need internet. The published site serves local WebM files. Download the separate film pairs for offline use.

Capture-era scene/renderer snapshots are retained with their exact film-receipt hashes. Scene snapshots refer to original uncompressed geometry; decompress the lossless `.bin.gz` display meshes to recover those bytes. Later UI/gzip/resize fixes do not change the recorded solver fields or tool geometry.

The native package rebuild imports and builds all frozen dependencies. Its topology, rounded vertices and bounds match the released STEP, and default two-way solid subtractions are empty. Its scalar volume differs by 0.000153%, so the strict volume gate remains failed; all scientific analyses use the exact released STEP. The receipts distinguish Boolean tolerance agreement from bit-identical export or an exact volume evaluator.

The additional modal matrix cross-check is unresolved: mass orthogonality matches, but independent eigen-residual and print-rounding compatibility gates fail. Bounded SuperLU solves produced no accepted eigenpair result. Modal frequencies are reported as unverified references, not a validation pass; static force/moment evidence and film fields are separate.

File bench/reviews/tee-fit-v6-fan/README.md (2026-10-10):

# Fit spectrum v6 — corrected HX04 fan print frames

V5 used the two-tier HX05 rack angles, not the HX04 fan. **Use v6 for the fan-angle test.** The same three connected coupons retain five lettered A–E slots, guide lengths 40/40/56 mm, a separate 0.8 mm entrance, square 3 mm floors and 1 mm through vents.

| Coupon | Shaft elevation above bed | Orientation authority |
|---|---:|---|
| 3 mm | 25.0982° | Actual HX04 T3 shaft and handle vectors |
| 5 mm | 38.5279° | Actual HX04 T5 shaft and handle vectors |
| 7 mm | 44.2220° | Normalized interpolation of HX04 T6/T8 vectors; no T7 exists |

Both shaft vectors **and hex-flat clocking** are transformed by the fan's left-cheek Y+90° print rotation. This tests the revised flat-to-flat fit, rather than the original corner-clocked seats. Flat feet preserve the angles. Keep the bases down; do not auto-orient. The feet and outer bodies are coupon geometry, not full fan structure.

| Letter | Clearance per flat | Total AF clearance |
|---|---:|---:|
| A | 0.10 mm | 0.20 mm |
| B | 0.15 mm | 0.30 mm |
| C | 0.19 mm | 0.38 mm |
| D | 0.23 mm | 0.46 mm |
| E | 0.28 mm | 0.56 mm |

C matches the latest requested clearance. Pick the smallest letter that seats fully and slides out comfortably without forcing, then compare rocking and rotation. 3E allows full rotation geometrically. Report **3 mm = _, 5 mm = _, 7 mm = _** after physical testing.

`fan_orientation_v6.json` records the actual shaft/bar frame, fan layout and source hashes, build environment and print rotation. To adjust an angle, change that orthonormal frame and rebuild; FreeCAD properties are metadata.

```bash
.local-runtime/freecad-python bench/source/tee_racks_v1/fit_spectrum_v6.py --out bench/reviews/tee-fit-v6-fan
.local-runtime/freecad-python bench/source/tee_racks_v1/tools/check_fit_spectrum_v6.py bench/reviews/tee-fit-v6-fan
```

Native source checks verify exact six-flat frame congruence, insertion, rotational stops or expected free rotation, floor shoulders, and vents remaining open after foot union. Delivered STL/STEP/FreeCAD exports are reloaded and checked. Actual owner-profile slicing, print submission and physical fit remain pending. Inspect the inclined bore roofs, undersides, supports and vents using the owner's calibrated printer/filament profile. No G-code is supplied, and no overnight print has been started from this box.

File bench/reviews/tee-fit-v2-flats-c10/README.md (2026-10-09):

> Superseded by [v3: 40 mm minimum guide, longer for larger shafts](../tee-fit-v3-guide40/README.md). This v2 record preserves the earlier short-guide trial.

# Straight-guide fit coupon v2 — flat-to-flat, half clearance

Owner reported weak small-key seating, roughly 15° rocking of the 2 mm L-key, and complete rotation in both 5 mm tests of the published HX04 v2 coupon. The owner confirmed that the T-handle axis runs **flat-to-flat**, and requested halving hex clearance.

This coupon has three independent blocks: **L2 F10**, **T2.5 F10**, **T5 F10**. F denotes flat-to-flat orientation along design Y; 10 denotes **0.10 mm per-flat clearance**, adding **0.20 mm total across flats**. The 5 mm bore is **5.20 mm AF**. Dimensions are CAD targets; printed dimensions and fit remain to be measured.

| Tool | Bore AF | Burial along shaft | Straight hex guide |
|---|---:|---:|---:|
| 2 mm L-key | 2.20 mm | 14.6 mm | 13.8 mm |
| 2.5 mm T-handle | 2.70 mm | 12.0 mm | 11.2 mm |
| 5 mm T-handle | 5.20 mm | 20.0 mm | 19.2 mm |

There is a **0.8 mm entrance chamfer**, a straight six-flat bore and a square-ended **3 mm floor**. No rounded seating chamber, widening flare or sloped floor. The original hex ceiling is preserved; its short flat bridge requires inspection in the owner's actual slice. This is a new trial geometry, not a calibrated production fit or a support-free claim.

- `HX05-fit-v2.FCStd`: native FreeCAD solids arranged in left-end print orientation; dimension properties are metadata, rebuild with the Python source to change the geometry.
- `HX05-fit-v2__left-end__print.stl`: bare print-preparation mesh of all three blocks. Use the owner's printer/filament profile and review bore roofs, supports and shrink compensation before printing. No G-code is included.
- `HX05-fit-v2__left-end__print.step`: same assembled print pose in native STEP.
- Individual `*__installed.step` files: socket axis is design Z; handle flat-to-flat direction is design Y.
- `fit-v2-check.json`: native validity, rotational stops, floor probes, dimensions and source/font hashes.
- `old-seat-audit.json`: audit of the actual published HX04 native coupon. Both old 5 mm sockets interfere with a nominal 5 mm shaft at 30° by only about **0.34–0.41 mm³**, concentrated in the short neck; ideal CAD still has a stop, but the owner’s print does not provide effective restraint.

The new 5.20 mm bore has a theoretical one-sided rotational allowance of **4.25°**, or **8.49° total**. Native 0.25° rotation samples first intersect at 4.25°. That remains clearance fit, rather than zero-play or mechanical locking. The same checks confirm positive stops for the other two blocks and solid floors.

Built and checked locally with **FreeCAD 1.1.3 / OpenCascade 7.8.1** from the checksum-verified official AppImage. The source is `bench/source/tee_racks_v1/fit_coupon_v2.py`. Reproduce from the repo root:

```bash
bash bench/source/tee_racks_v1/tools/setup_freecad_linux.sh
.local-runtime/freecad-python bench/source/tee_racks_v1/fit_coupon_v2.py --out bench/reviews/tee-fit-v2-flats-c10
```

The published HX04 source and files remain unchanged as history. HX05's hex clearance and handle orientation are corrected; its full racks still retain the earlier seating shape until this straight-guide coupon establishes fit. Physical seating, rotation, extraction and print quality of this new coupon remain pending.

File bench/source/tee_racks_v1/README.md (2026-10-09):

# HX05 Bondhus single-set racks — source and build handoff

Branch `hx05`. The reconciliation with dev-box `7d7b2fc` is complete: that commit was already published and inherited through HX04 v2. See [RECONCILIATION.md](../key_fan_v1/hx05/RECONCILIATION.md).

Three candidates use two staggered rows with larger tools above smaller tools: HX05A / 33034 Torx, HX05B / 13189 metric, HX05C / 13190 inch. Each is a single-set rack. The 236 mm mounting plate and full hook / intermediate bearing / bottom-lock grid remain. Grips have equal **48 mm centre spacing within each row**, enlarged from the inherited 39.2 mm to clear neighboring tools throughout the sampled clock play. The gap between rows is set by withdrawal clearance, not counted as another grip pitch. Straight guides are at least 40 mm and increase to 8× shaft size for larger tools; the 0.8 mm entrance is additional. Floors are square, with no flared/rounded seating chamber. Owner confirmed bars run flat-to-flat (2026-10-09). Hex clearance is now 0.10 mm per flat, halved from 0.20 mm; a 5 mm shaft gets a 5.20 mm bore across flats. Fillaprint labels, brace-type solid zones and left-end printing remain.

The HX05 execution sources are isolated here; the original `key_fan_v1` pipeline is restored byte-for-byte to published HX04 v2 so its evidence hashes continue to match. The added row mode is opt-in (`SHORT_TONLY=1 SHORT_TEE_STAND=1`). Each row gets its own rail and socket braces. Post-lift shaft withdrawal slots cut through the intervening rail webs while protecting the full guide wall. The unchanged HX04 layout is regression-checked against the study source at `c108ee4` (default HX04 behavior). Shared peg geometry is untouched.

| Rack | Set | Reported inherited depth | New dense sampled depth | Plate height study |
|---|---|---:|---:|---:|
| HX05A | 33034 | ~246 mm | 167.6 mm | 169.7 mm |
| HX05B | 13189 | ~285 mm | 177.9 mm | 150.9 mm |
| HX05C | 13190 | ~507 mm | 177.9 mm | 157.5 mm |

Inherited depths are the handoff figures, using its old estimates; they were not rerun as native CAD. New depths include tools at the sampled rotation limits. Plate heights are numerical bounds from the build formula, not exported meshes.

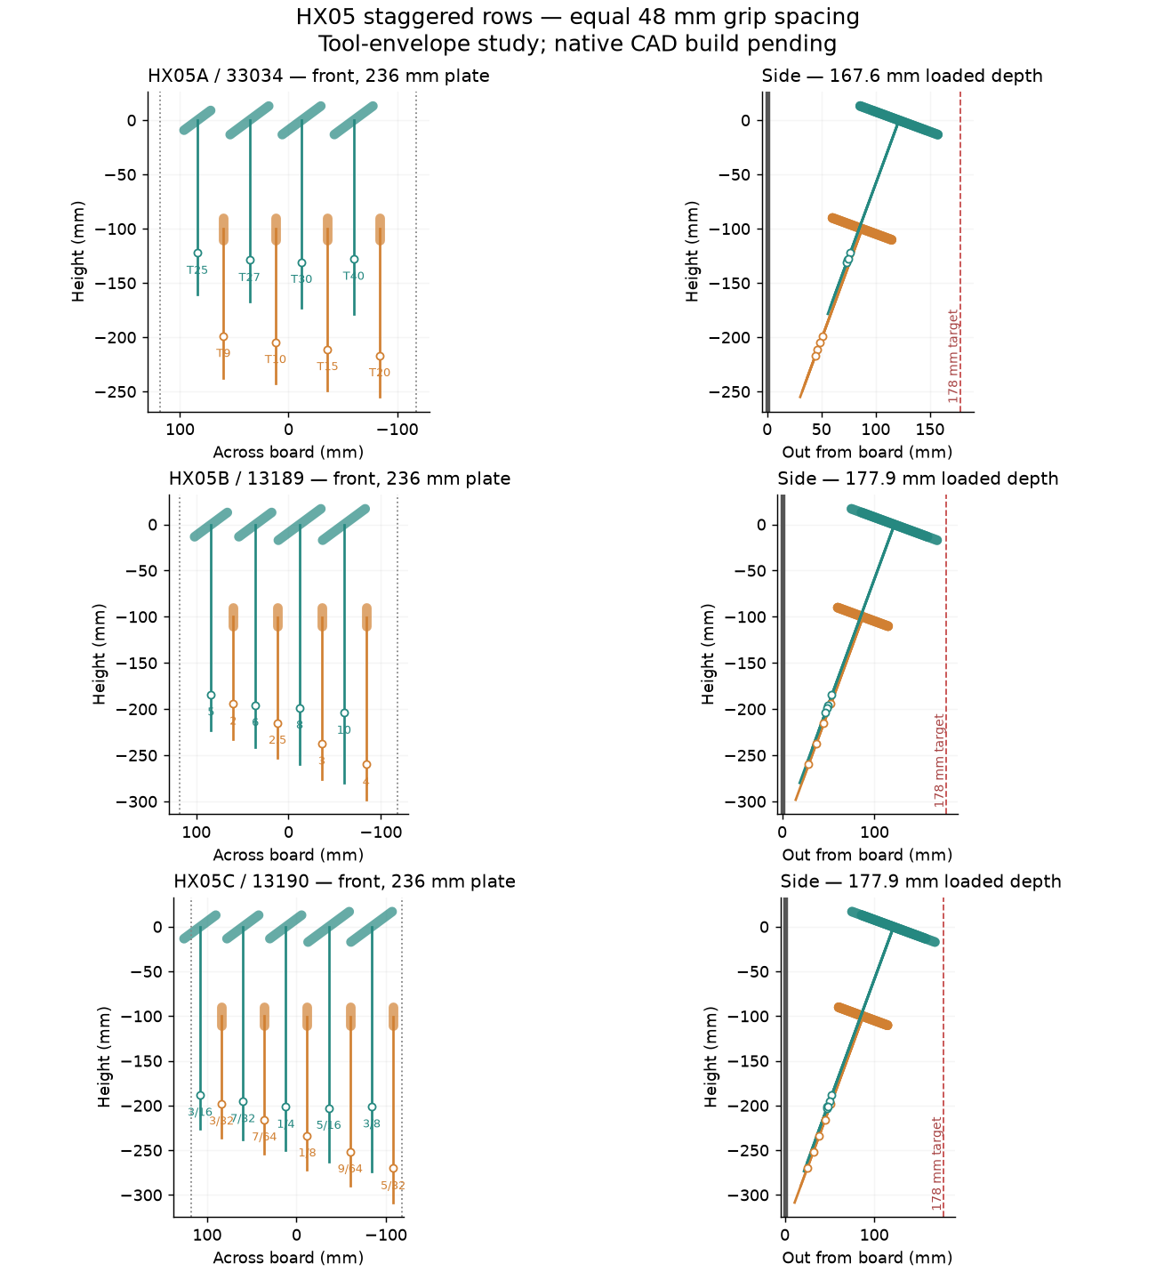
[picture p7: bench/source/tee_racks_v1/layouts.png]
Front and side tool envelopes


## Layout evidence and limits

Selected layouts are `study/hx05a_stand.json`, `hx05b_stand.json`, `hx05c_stand.json`. Each records its source hashes, exact build environment, parameters, planned lift distances and search results. Corresponding `*_layout-check.json` files recheck the same **fixed lift-then-forward route** at nominal, both clock-play limits and alternating neighbor limits, using 0.75 mm tool points/lift samples and 1.25 mm forward samples.

These are dense sampled layout checks of sphere/capsule tool envelopes and convex rail planes. They are not continuous motion certificates, actual FreeCAD solids, qualified print files or physical fit/load evidence. The shared study's approximate own-bore exclusion is still used; native checking is required for both rails, labels, floors, braces, pegs and withdrawal paths. Hand clearance is not physically qualified by equal centre spacing.

`study/tee_sets_note.json` identifies the [Bondhus 2023 catalogue](https://3989ac5bcbe1edfc864a-0a7f10f87519dba22d2dbc6233a731e5.ssl.cf2.rackcdn.com/bondhus42/catalogs/2023/2023_US_Bondhus_Catalog_A.pdf), printed pages 35 and 41. All three sets now use its millimetre overall and bar lengths rather than the metric-curve interpolation. Inch across-flat sizes use exact inch conversion. Grip thickness remains an assumed 18 mm envelope; Torx point-to-point values and the clocking/retention behavior of its hex proxy need coupon validation. The owner's small straight-tip tools are distinguished in the catalogue from the larger ball tips.

## Required owner Windows build — one command

**FreeCAD 1.1.3 is now available locally** through the pinned official Linux AppImage (`tools/setup_freecad_linux.sh`). The [40 mm guide fit coupon](../../reviews/tee-fit-v3-guide40/README.md) has native FreeCAD/STEP/STL exports and geometry checks. The full HX05 racks, FEA and slicing still need a new run after the coupon establishes physical fit. The full review driver below uses the owner's existing Windows P1S / PolyLite ASA ReproCal setup.

After fetching/checking out the latest `hx05`, from the repository root in PowerShell:

```powershell
$env:FREECAD_PYTHON = 'C:\Program Files\FreeCAD 1.1\bin\python.exe'
$env:FREECAD_BIN = 'C:\Program Files\FreeCAD 1.1\bin'
python bench/source/tee_racks_v1/tools/hx05_build.py
```

Use the actual working FreeCAD Python executable path if it differs. The ordinary `python` environment must have the same scientific/mesh packages as the HX04 tools (`numpy`, `scipy`, `trimesh`, `fast_simplification`), and the existing renderer needs Node / `playwright-core` / the owner's Chromium. Preflight checks these and the inherited Orca paths/profiles before starting; it does not install dependencies or choose a substitute printer/filament.

`--plan` prints the selected layouts/stages without requiring FreeCAD. `--preflight-only` checks the Windows setup without building. `--rack HX05C` runs just one rack. Git Bash can use `tools/hx05_rack.sh HX05C`; the former five positional arguments have been replaced by the selected-layout runner.

The runner creates fresh timestamped outputs in ignored `bench/source/tee_racks_v1/runs/`, builds each rack and coupon together, and waits for bounded exact-check / FEA / install-swing / coupon-slice jobs. Racks run sequentially to limit memory; four checks run concurrently within each rack. FEA screens both ends of both tiers, using the inherited coarse 10 mm mesh and solid-ASA assumptions; it does not establish a physical load rating or convergence. Exact withdrawals use 3 mm steps and installation 0.5° steps, finer than the inherited HX05 WIP speed settings.

A failed process, timeout, stale layout hash, native validity/label failure, collision, absent floor material, >178 mm CAD depth, invalid mesh, uncompensated build-size issue or failed swing stops the pass and writes `FAILED.json`. The P1S dimension check includes actual filament compensation and a 5 mm XY brim. Overhangs and slicer support results remain review evidence, requiring inspection rather than an automatic support-free claim.

On success, native/mesh files and evidence land in `bench/reviews/tee-racks-v1/HX05A`, `HX05B`, `HX05C`, accompanied by `build-geometry.json` and `pipeline-run.json`. Review logs, six browser views and local slices stay in each fresh build directory. No G-code is published and no printer is contacted. Send the run's evidence/logs back for review; if a native check fails, fix the geometry and regenerate dependent evidence before publication.

## Local reproduction

From `bench/source/tee_racks_v1/study`, use the selected record's `build_env`; for example:

```bash
SHORT_TONLY=1 SHORT_TEE_STAND=1 SHORT_TEE_SET=tee_13190.json \
SHORT_CELLS=10 SHORT_PLATE_HALF=118 SHORT_REC_CELLS=9 XENV=141 \
SHORT_HMAX=215 SHORT_TEE_EQUAL=48 SHORT_POINT_STEP=1.25 \
SHORT_ESCAPE_STEP=2.5 SHORT_STEP=1.25 SHORT_ROBUST=1 SHORT_ROBUST_ALT=1 \
python stand_rows.py --seconds 60 --output hx05c_stand.json
```

Then run `verify_stand.py hx05c_stand.json --output hx05c_layout-check.json` with that same environment. Long searches belong in a named tmux session. `python -m unittest discover -s bench/source/tee_racks_v1/tools -p test_hx05.py -v` checks HX04 regression, all three selected layout contracts and runner failure handling without FreeCAD.

## Gallery/publication status

The intended destination is one shared page for the three single-set racks. No HX05 gallery downloads have been published: publishing models or preview media before an actual native build would misstate the evidence. After the Windows pass, prepare the one-page gallery, three immutable native/source bundles, reviewed GLBs/renders, scoped checks and updated release manifest using the existing HX04 publication workflow. Leave HX04's published page/history intact. Physical fit, support removal and representative loads remain pending even after a successful computational review.

## Physical coupon feedback — 2026-10-09

The owner’s printed HX04 v2 coupon permits excessive small-key rocking and full rotation of both 5 mm tests. The owner confirmed flat-to-flat T-bars and requested 0.10 mm per-flat clearance. Those two corrections are in the isolated HX05 sources; regenerated layout evidence retains the same parameters and seat shape. A separate [straight-guide coupon v2](../../reviews/tee-fit-v2-flats-c10/README.md) tests the simpler full-depth guide and square floor locally in FreeCAD. The full-rack source now uses the owner’s 40 mm minimum/8× guide rule, straight hex sections and square floors; native builds and the new coupon establish geometry, while physical fit remains pending.

## Guide-length revision — 2026-10-09

The dimensional authority is `study/socket_policy.py`: guide = max(40 mm, 8× shaft size), burial = guide + 0.8 mm entrance. Larger tools occupy the upper row; their bars are angled 25° from fore-aft and the shafts tilt 20° forward to clear the overhead shelf during the longer lift. Smaller lower-row bars remain fore-aft. Per-row grip centres remain equally spaced at 48 mm. The motion screen reserves 3 mm to the shelf, tool-to-tool movement and post-lift shaft slots. Those slots are applied to the actual CAD; a native assertion protects every guide’s complete wall.

The [v3 coupon](../../reviews/tee-fit-v3-guide40/README.md) demonstrates 40 mm guides for L2/T2.5/T5 and an 80 mm guide for T10. Local native holder builds use `python bench/source/tee_racks_v1/tools/hx05_cad_build.py`; its `--check` option adds the exact OCC storage/withdrawal check. Full profile slicing, FEA and physical qualification remain separate.

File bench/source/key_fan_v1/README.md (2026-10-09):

# HX04 key fan — source

A three-tier pegboard rack: metric hex L-keys at the back, Husky Torx L-keys in the middle and Bondhus T-handles in front. The review, printing notes and evidence are in `bench/reviews/key-fan-v1/HX04/NOTES.md`.

## Layout study (`study/`)

- **`short.py`** places every tool: rows of sockets with stepped tilt, lean and turn, plus the T fan's angle schedule. It holds the socket physics:
  - seat depth at least 4× the key size;
  - each L-key's short arm pointing downhill;
  - the rest pose, where a tool's weight tips it about the mouth lip onto a floor sloped 30° low on that side;
  - hex-keyed T bores and the turn play of each handle.

  It also scores storage and withdrawal against the other tools, the rails (with their label lips) and a 3″ shelf 2″ above. Its `rail_points` and `floor_plane` are shared with the CAD.
- **`nudge_rows.py`** is the local polish. The final layout is `short_dt_c2.json`.

## CAD and checks

- **`build_short.py`** is the FreeCAD 1.1 model. It covers rails and webs swept 50° and rounded by the owner's edge rule (chamfer in Z, fillet in XY), bottle bores with sloped floors, Fillaprint labels, the mirrored PF02 #9 / PF07 #5 receiver, and the solid-infill zones. `--quick OUT` writes the meshes and STEP.
- **`check.py`** is the exact OCC check: storage, straighten-then-lift withdrawal, shelf and floors.
- **`fea_run.py`** runs the gmsh + CalculiX stiffness screen and needs `FREECAD_BIN`.
- **`coupon.py`** builds the fit coupon.
- **`tools/`** holds:
  - the overhang gate;
  - the review slices: plain STL, and the 3MF with the solid-zone modifier;
  - the GLB and render helpers;
  - `run_candidate.sh`, which runs the whole pass and needs `FREECAD_PYTHON`.

The build environment for the published layout is recorded in `report.json` (`build_env`). Tool data come from `bench/source/three_set_rack_v1/key_sets.json` (catalogue values). The label font is Fillaprint (SIL Open Font License, `fonts/OFL.txt`).

## HX05 single-set T-handle racks

The HX05 branch adds two staggered rows per set (33034 Torx, 13189 metric, 13190 inch) to resolve the deep-fan blocker. [Selected layout evidence and the one-command owner Windows build](../tee_racks_v1/README.md) describe the opt-in row mode and pending native/physical checks. HX04’s published layout and evidence remain separate.

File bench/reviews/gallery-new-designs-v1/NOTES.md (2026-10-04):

Six new session designs accompany the 38 remounted gallery bodies. These are frozen exports with per-design print poses and test status. The v14 cradle misses its downward stiffness target; the guided tweezers need four separately printed fins; the liner is a filled spiral-vase template with a separate hollow in-use display. No new printing or modeling was performed for publication. No raw scans, owner photos, machine profiles or printer jobs are included. Native/source bundles preserve selected sources and evidence; historical render overlays can require excluded private inputs.

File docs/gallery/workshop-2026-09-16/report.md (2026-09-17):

# Pegstr workshop: useful shapes, better daily use

**September 16, 2026 · design review and one new prototype.** Existing gallery models are unchanged. CAD checks, slicing evidence and physical feedback are distinguished below.

## What makes Pegstr work

Pegstr begins with an opening suited to the object and builds a straightforward holder around it. Short sleeves bear on shoulders while leaving the grasp exposed; matrices share walls; deeper pockets preserve orientation; floors turn openings into bins. Width, depth, taper, cut-out, bottom closure, count and reinforcement are useful construction choices, not just styling.

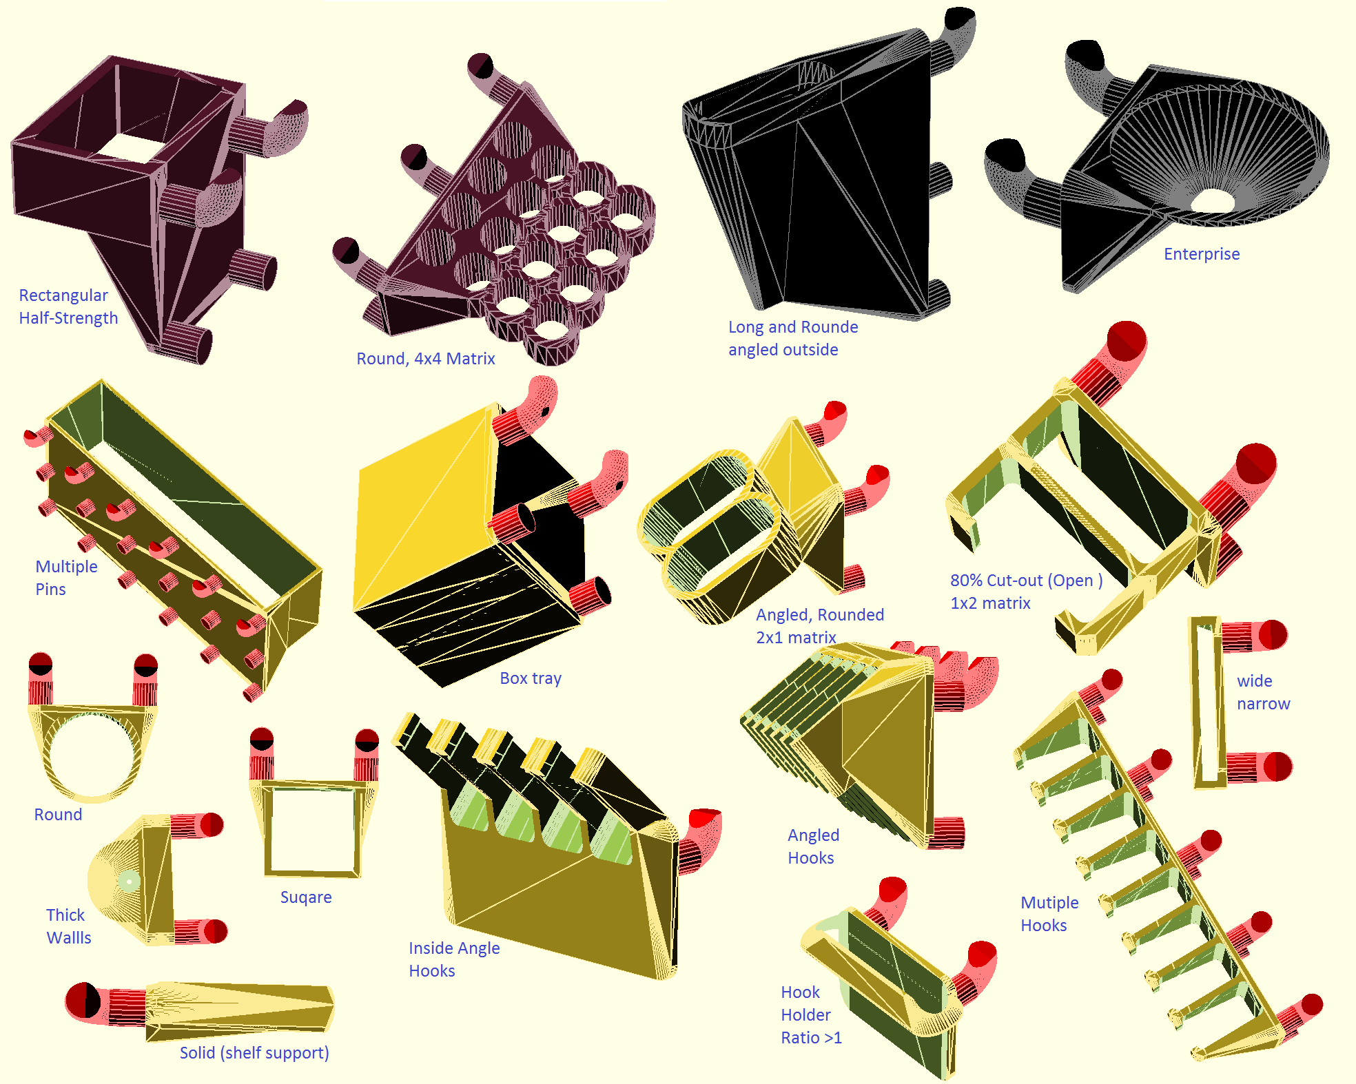
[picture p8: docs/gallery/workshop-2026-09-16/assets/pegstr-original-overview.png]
Original Pegstr examples


*Original reference illustration: Marius Gheorghescu / mgx, CC BY-NC. [Thingiverse](https://www.thingiverse.com/thing:537516) · [Source](https://github.com/MGX3D/pegstr). The author requests contact before commercial use. These examples do not qualify every generated variation.*

| Strength to borrow | Limit to address |
|---|---|
| Compact, visible tool seats | Tool pitch is not hand clearance. Pack shafts while leaving grips accessible. |
| Gravity and a clear bearing surface | A long tool may still rock or sweep its tip. Two short separated bearings can be useful. |
| Simple closed openings | They need axial lift. Front access matters below another occupied row. |
| Open-front construction | The entry path can also be an escape path. Retention must match the unwanted motion. |
| A flexible generator | Mixed tools, drip handling, delicate tips and magnetic gaps need specific geometry. |
| A coherent family | Preserve what a holder does through style changes; do not force all jobs into one silhouette. |

## The process worth keeping

**Hold → Grab → Return → choose the print face → develop the geometry in that frame → try the actual tool.**

Name the primary bearing and the unwanted motion. A thick seat can bear and guide at once. Keep the real grasp exposed and the board contact flush. Use two mounting columns where they fit and the current canonical peg source. Module width is occupied cells × 25.4 mm minus 2 mm; tool count is independent of cell count.

Choose the bed face before final massing: right cheek, broad top inverted, useful bottom or a deliberate diagonal face. Local accessible supports are normal. Judge their location and removal rather than treating an enabled-support setting as a defect. A comfortable lift-and-out can be one hand action.

## Existing solder and screwdriver work

The photographed solder tube holder received positive hands-on feedback. Preserve its exposed barrel grips, separate lower seats and two short bearings. The exact photographed export revision was not identified, so this does not qualify every solder-module file. Storage, independent access, braid away from nozzles, removable drip collection and protected tweezer tips remain the jobs.

The **MS01 v3 recoverable A–P sampler** remains the next driver fit trial. Use one owned 20 × 10 × 3 mm magnet across plausible neighboring seats, tape the removable comb, and record letter, actual driver and feel. Then check the chosen neighboring handles and overhead row. No force gauge or extra coupon is required.

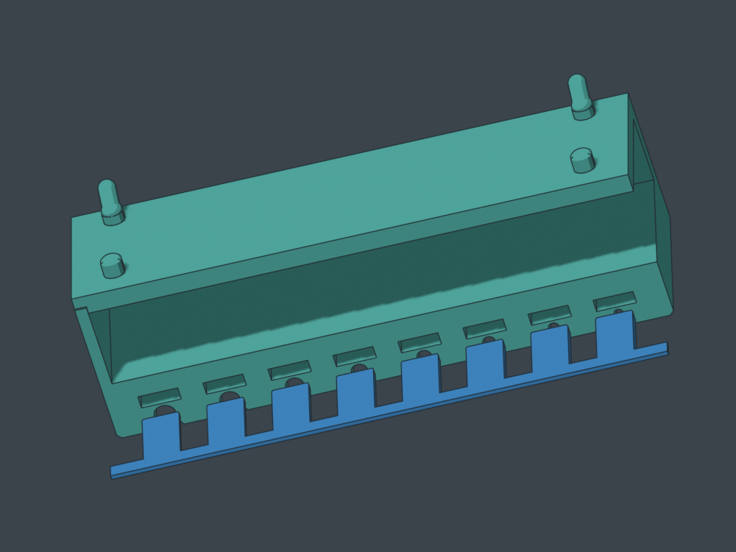
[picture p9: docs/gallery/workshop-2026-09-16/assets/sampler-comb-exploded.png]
Recoverable sampler and retaining comb


A limited review of both frozen holder G-code strips found supports away from the shaft seats and no detected perimeter starts within 0.65 mm of the seat backs above the first layer. Existing pocket checks found no intrusions. Entry lips and endpoints were not separately audited. This establishes no new print blocker; it does not measure surface finish, magnetic feel or future reslices.

[Open the current sampler](../shaft-sampler/recoverable/) · [Solder modules](../solder-modules/)

## SWD01 v1: a screw dish that comes to the work

A **60 × 40 × 12 mm removable dish** sits in a shallow recess on a three-cell, 74.2 mm-wide cradle. Take the dish to the repair and return it to the board. Most of its side wall remains exposed for a pinch grip.

<div class="pair">
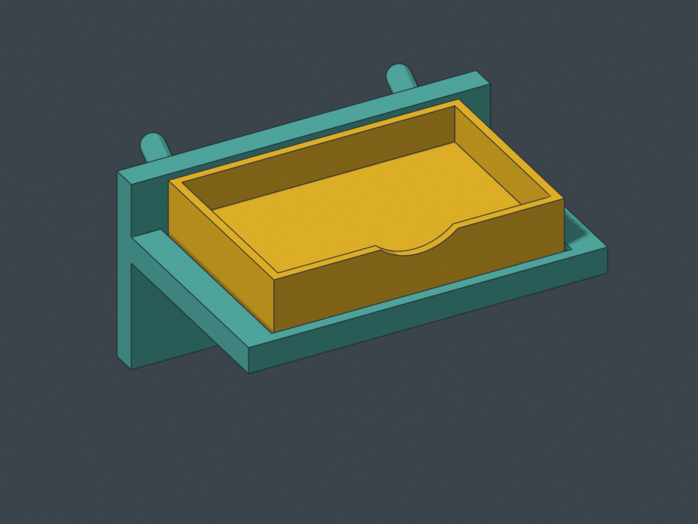
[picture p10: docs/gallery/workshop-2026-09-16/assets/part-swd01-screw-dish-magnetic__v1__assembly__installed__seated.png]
Screw dish seated in pegboard cradle
<figure><figcaption>Seated in a shallow locating recess.</figcaption></figure>
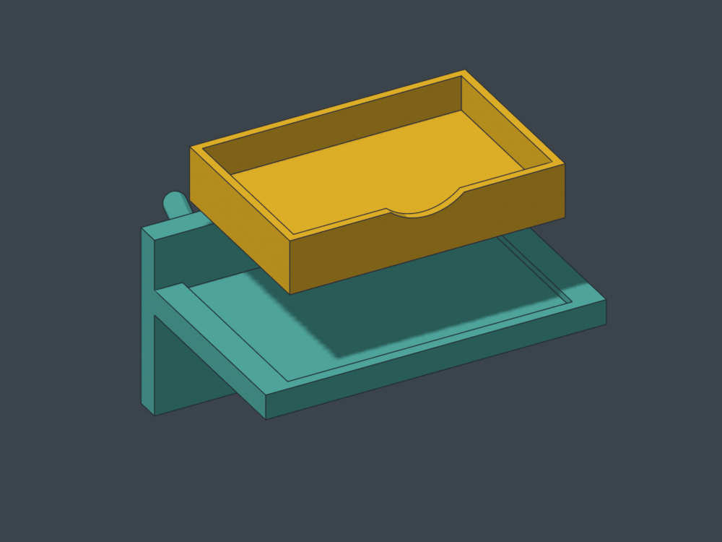
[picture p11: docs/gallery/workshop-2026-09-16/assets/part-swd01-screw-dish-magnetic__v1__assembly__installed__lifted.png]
Screw dish lifted out of cradle
<figure><figcaption>Lifted 20 mm for illustration; the sampled removal path used 3.5 mm then forward travel.</figcaption></figure>
</div>

Two **20 × 10 × 3 mm magnets** load after printing into underside pockets with removal clearance. Tape retains them for the prototype; peel it to recover them. The floor is continuous, and the front scallop leaves 4.6 mm of wall above it.

Choosing the **right cheek as the cradle's bed face** removed a bulky upright-print foot and reduced installed height from about 76 to 39 mm. The tray prints on its flat bottom.

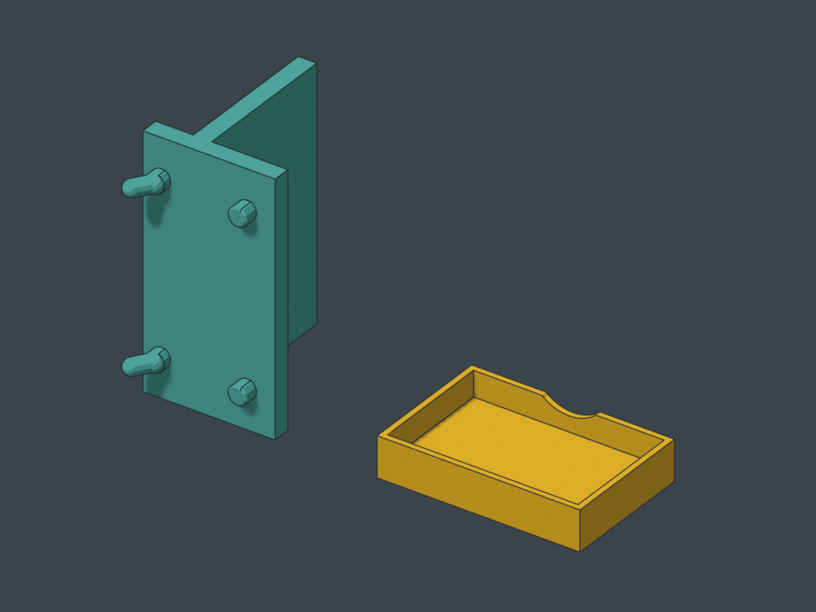
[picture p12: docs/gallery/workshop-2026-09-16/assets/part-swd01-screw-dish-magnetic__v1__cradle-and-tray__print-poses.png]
Actual exported print poses


*Actual mesh renders, not slicer previews. Cradle pegs need local-support review; the tray has two 10.4 mm pocket roofs intended to bridge.*

Independent STEP checks found one valid solid per part, zero seated overlap with contact, clearance for both nominal magnets and no collision in sampled lift-and-forward poses. Bed-contact areas are approximately 455 mm² for the cradle and 1,976 mm² for the tray. These are CAD checks, not proof of adhesion, strength, bridge finish or hand feel.

**Form-review prototype — unsliced and physically untested.**

- [STEP/STL review bundle, source and notes](https://github.com/thereprocase/peg/releases/download/swd01-workshop-v1-20260916/part-swd01-screw-dish-magnetic__v1__public-review-bundle__fit-e586ab4ff6.zip)
- [Assembly STEP](https://github.com/thereprocase/peg/releases/download/swd01-workshop-v1-20260916/part-swd01-screw-dish-magnetic__v1__assembly-reference__installed__fit-e586ab4ff6.st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)
- [Cradle STEP — right-cheek pose](https://github.com/thereprocase/peg/releases/download/swd01-workshop-v1-20260916/part-swd01-screw-dish-magnetic__v1__cradle__print-right-cheek__fit-e586ab4ff6.step)
- [Tray STEP — flat pose](https://github.com/thereprocase/peg/releases/download/swd01-workshop-v1-20260916/part-swd01-screw-dish-magnetic__v1__tray__print-flat.step)
- [Generator source](https://github.com/thereprocase/peg/blob/main/bench/source/screw_dish_magnetic.py)

Built with BlackTower's contribution and independently reviewed by Shelves-Codex. The current tighter peg fit is recorded in each export. A test print should decide recess and grip feel before adding latches or generating variants.

[Back to the curated gallery](../)

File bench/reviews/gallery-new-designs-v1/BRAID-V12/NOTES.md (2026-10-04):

# Braid roll, v12 (rev 2: sourced bobbin envelope)

`part-solder-braid__v12__right-cheek__fit-pf02c9-hoop5`. The builder is
`bench/source/solder_v12/braid.py`. It is 2 cells wide, hangs on hoop row 1 and prints on its
right cheek. Its station position is unchanged: top-row centre at x -50.8, z -101.6. Its plate
footprint is the same as rev 1, so `station-layout.json` is unchanged. Coordinates are as in
BRIEF.md: facing the board, +X is your left and the right cheek is -X.

## What changed from rev 1, and why

| | rev 1 | rev 2 | why |
|---|---|---|---|
| roll it was built for | B6 proxy, 34 OD x 8 x 8 bore | every common bobbin: OD 38-52, width 6-12, bore 7-10.5 | TOOLS.md section 2: no common bobbin is under 38 mm; the old 41 mm drum fitted none of them (IMPACTS 2.2) |
| hood | a full drum, R_IN 20.5, open only at the front | top and back only (theta 50-180), R_IN 27.5, open at the front and the bottom | IMPACTS option 1b: a 52 mm rim hangs free below, so the module stays 2 cells and row 1 |
| axle | 6.0 mm, no catch | 5.6 mm (PIN_R 2.8) with a 0.8 mm lip on its top line | Frodo finding 1: a brush toward +X walked the roll off. The lip forces a 0.8 mm bore pass, so the axle had to shrink: a 7 mm cross-hub bore passes 5.6 + 0.8 = 6.4 with 0.6 to spare |
| hub seat | 13 mm (HUB_R 6.5), seat at u 6 | 10 mm (HUB_R 5), seat at u 8.5 | Every hub ring (12-16) is wider than the seat, so Chemtronics' domed face bears on its flat ring either way round. The seat moved out so a 52 mm roll's leaning top clears the cheek |
| cheek stiffening | the full drum | hood + a lower-edge flange + two webs crossing at the hub | the open bottom took away the drum's lower half. The FEA probe showed that the cheek bending round the hub was the compliance (below) |

## The design

- **Axis across the board.** The roll stands on edge on a stub axle that grows out of the
  right cheek. Its axis runs along X, rising 15 degrees toward the tip (the v11 tweezer cant).
  The braid pays off the front rim straight at you, flat and untwisted. The pull lies in the
  roll's plane, so it spins the roll and presses the bore onto the axle's top line.
- **Gravity seat.** Under the cant the roll leans into the cheek and seats its inner face on
  the 10 mm hub seat at u 8.5. Every roll hangs by its bore on the axle's top line.
- **Retention lip (nothing flexes).** The lip is 0.8 mm high and 2.0 mm wide, on the axle's
  top line at u 21.1, which is 0.6 mm past the face of the widest (12 mm) roll.
  - The keeper faces the roll and is a **V nose**. In the print its two faces rise 50 degrees
    from horizontal on either side of the leaning post, so they are print-down ramps with no
    overhang. The nose edge rises 10 degrees outward, so the lip's lowest point sits on the
    axle and there is no island.
  - Seen from the roll, the two faces push sideways (the axle already holds the bore
    sideways), not up. The nose edge stands 65 degrees off the axle.
  - A push toward +X meets the nose 80 degrees off its own direction (65 + the 15 degree
    cant). With no friction that takes about 5.7 x the roll's weight, and with
    plastic-on-plastic friction it locks. So a brush does not walk the roll off.
  - To pass the lip, the roll must be lifted 0.9 mm (measured). The tip side of the lip is a
    30 degree loading ramp, so pushing a roll on lifts it over by itself.
  - Measured on the final geometry (`scratch/lip_test.json`): sliding off without a lift,
    each roll hits the lip 0.8 mm deep, after 1.0 mm of travel (52 x 12), 3.0 (Chemtronics)
    or 7.0 (38 x 6). Each passes after a 0.9 mm lift.
- **Hood.** A 2.4 mm shell coaxial with the axle, R_IN 27.5. It runs from theta 50 (front-top,
  bullnose end) over the top to the back, where it runs into the plate. It covers the roll's
  inner 4 mm (rim at u 12.5). It is the cheek's top stiffening flange, and it catches lead
  ends falling from the snips above. The front, where the tail leaves, is open, and so is
  the whole bottom half.
- **Cheek.** A 3 mm bed face, 1885 mm2. Its outline is the hood's footprint, the hub flare and
  the plate edge, hulled. It is stiffened by:
  - a 6 mm L flange along its lower edge, from the plate's bottom corner to under the hub
    (with a 45 degree tapered end);
  - two 2.4 mm webs crossing at the hub: one back to the plate at the axle's height (for wag
    and pull), and one from the cheek's lower edge up toward the hood (for press). Both are
    trimmed to the plane 1.5 mm under the roll's inner face (u 7.0), so no roll touches them.
- **Receiver.** `common.receiver(2, 1, 'right-cheek')` with the shared install-arc hoop fix
  (root clipped to r 2.95, cheek hoop dropped 0.10 mm, verified rigid-clear on rows 1-6 in
  `install-arc/sweep-fixed.json`). The hooks are on row 0 and the PF07 #5 hoop is on row 1,
  turned into the cheek plane so it flexes in the print layers. The plate runs from Z 5.12
  to -31.28.
- **Plate.** A 50 degree pointed window in the free left half, with its point at +X (the
  print top), and 45 degree chamfers on the plate's two free corners.
- Nothing is glued and nothing snaps apart from the shared hoop. There are no bridges, and
  nothing overhangs except the pegs.

## Loading and unloading

- **Load (one motion):**
  1. Hold the roll so the free end comes off the front rim, toward you and downward.
  2. Offer the bore to the axle's cone tip from your left (+X, the open side) and push the
     roll on. It rides up the loading ramp, drops behind the lip and slides down the cant onto
     the hub.
  3. Let the tail hang from the front rim. Nothing sits under the roll, so it hangs free.
- **Use:** pinch the tail below the roll and pull it toward you or down. The roll spins.
  Snip with the cutters from the module above. The stub stays hanging at the front rim.
- **Unload (one motion):** pinch the roll by its outer face and its bottom rim. Both are fully
  exposed: the outer face stands 2-8 mm proud of the hood rim, and the whole lower half hangs
  below. Lift about 1 mm, until the bore rests on the axle's underside, and slide the roll left
  off the tip, about 19 mm along the axle. The roll stays inside the module's own width the
  whole way. A 52 x 12 roll's outer edge is at local x +5.3 on the seat and +23.9 when it
  leaves the tip; the module edge is +24.4 and the drip tray's plate starts at +26.4.
- **Wrong way round:** if the tail comes off the back of the roll, flip the roll over. Either
  face may go against the hub.

## Covered product range

The owner does not measure tools, so this module covers the sourced envelope
(`bench/reference/solder-tools/TOOLS.md` section 2). The checks run on three stand-ins built in
the builder:

- a 52 x 12 mm roll with a 7 mm bore: the envelope's largest OD and width with its smallest
  bore, the tightest case everywhere;
- a 38 x 6 mm roll with a 10.5 mm bore: the smallest and thinnest roll with the biggest bore,
  which hangs lowest;
- a Chemtronics Soder-Wick SD, 44.5 mm with an 8 mm bore and 10 mm thick at the hub, loaded
  domed face in.

The B6 34 mm proxy is no longer used. Every check and the station check pass for all three.

| dimension | covered | limit (what sets it) |
|---|---|---|
| OD | 38-52 | up to about 54: the hood back (1.5 mm gap at 52) and top (2.2 mm at 52 with a 7 mm bore; the 0.9 mm unload lift leaves 1.3) |
| width | 6-12 | 12.6: the lip sits 0.6 mm past a 12 mm roll. Thinner rolls just have axial play; the cant holds them on the hub |
| bore | 7-10.5, round or cross hub (7 mm inscribed) | at least 6.4 to pass pin + lip (7 leaves 0.6). Larger bores hang lower and still bear on the seat's upper crescent; checked to 10.5 |
| inner face | flat, or domed with a flat hub ring at least 10 mm across | the seat is 10 mm across. The face must not bulge more than 1.5 mm toward the cheek outside the hub ring (it sits 1.5 mm off the webs) |
| form | a bare bobbin or a case with a through-hole that spins whole | the whole roll spins on the axle (whether Japanese cases turn inside is unconfirmed; irrelevant here) |

- **Products covered:** MG Chemicals Super Wick 423-427 (39.9 mm), Chemtronics Soder-Wick SD
  (44.5, domed face), Techspray Pro Wick 1808-1813 (45.0), the generic Amazon/AliExpress
  cross-hub cases (45.7), goot Wick CP-xx15 (51), and the Hakko FR551/FR150 and Chip Quik
  SOLDERWICK cases (40-46 family, OD not confirmed).
- **Not covered (a different holder):**
  - dispensers with no bore: goot CP-xxY tadpole, Velleman/Whadda DESOLDER4 thumbwheel;
  - long-length spools (25-100 ft): 55-60 OD, 20-28 wide, 20 mm bore.

## Print

- **Pose:** right cheek (-X) on the bed. The bed footprint is the 3 mm cheek plus the plate
  edge. The print is 42.96 x 65.93 mm on the bed and 48.8 mm tall.
  - The plate, window walls, webs and flange stand vertical.
  - The hub, axle and hood lean 15 degrees off vertical.
  - The lip's V faces rise at 50 degrees.
  - Only the four pegs reach into air.
- **Supports:** Orca organic tree supports, on the build plate only. They land under the pegs
  only (verified below).
- **Settings, read from the sliced job:** `Repro - ASA - Polymaker PolyLite - Calibrated`,
  nozzle 260 C, bed 100 C, 0.2 mm layers, 2 walls (Arachne), 20 % crosshatch infill, 5 top and
  3 bottom layers, 5 mm outer brim. The job is
  `print/slice-v12/V12-braid-ASA/V12-braid-ASA.gcode.3mf`. It has not been sent to the printer.

## Numbers (last passing run)

- **Volume:** 16.47 cm3, 17.6 g solid ASA. B6 was 39 cm3, so this is 42 % of B6 (58 % less).
  Rev 1 was 17.30 cm3. The webs cost 0.55 cm3.
- **`checks.py`: passed.**

  | check | result |
  |---|---|
  | body | 1 watertight body, 16.47 cm3 |
  | pose-matrix error | 0.0 mm |
  | non-peg overhang area | 0.0 mm2 (peg 132.2 mm2) |
  | islands | none |
  | 52 x 12 bore 7 | deepest 0.000, 607 contacts, centre of mass over the contacts; removal (lift 1.2, slide 19.6 along the axle, out 70) min -0.000 (sliding on the seat) |
  | 38 x 6 bore 10.5 | deepest 0.000, 173 contacts, centre of mass over the contacts; removal (lift 1.0) min -0.000 |
  | Chemtronics 44.5 domed | deepest 0.000, 405 contacts, centre of mass over the contacts; removal (lift 1.3) min +0.001 |
  | tail stand-in | clear (17.7 mm off the holder) |

- **Clearance at rest, away from the axle and seat** (`scratch/lip_test.json`): 1.5 mm to the
  plate behind the 52 mm roll, and 1.5 mm from every roll's inner face to the webs (by
  design). The top gap under the hood is 2.2 mm (52 mm roll, 7 mm bore).
- **`fea.py`, pegs support, 5 N at the lip (u 21.6, radius 3.5), the farthest point a roll
  bears on:**

  | load | at the load | stiffness | worst node | limit |
  |---|---|---|---|---|
  | wag, sideways (+X) | **0.106 mm** | 47 N/mm | 0.173 at the cheek's front tip | 1.0 (9.4x margin) |
  | press, down (-Z) | **0.166 mm** | 30 N/mm | 0.225 at the axle tip | 0.5 (3.0x margin) |
  | pull, toward you (+Y) | 0.139 mm | 36 N/mm | 0.212 | |

  Where the deflection comes from (`scratch/fea_probe.py` / `.json`):
  - The plate and pegs move less than 0.01 mm.
  - Before the webs (0.147 / 0.208 / 0.216), the cheek bent out of plane round the hub.
  - Press now splits into: hub rotation (about 0.075 mm at the lip), the 5.6 mm pin bending
    over the 13 mm it needs for a 12 mm roll (about 0.05), and hub translation (0.03).
  - The pin's size and length are set by the envelope.
- **Slice** (`NAME__slice.json`): 51.7 min, 11.08 g, 244 layers.
  - Support is 1.06 g. All 6426 support and 378 support-interface points map to behind the
    plate, at the pegs (`scratch/support_where_xy.py`).
  - Overhang wall is 0.01 g, all at the pegs.
  - Bridge is 0.00 g: the pegs, plus the last points closing the window's apex at X 21.2.
  - Internal bridge (0.48 g) is solid infill over sparse infill inside the cheek, the hub and
    the plate, not over air.
- **Station** (`station.py` with this build, output in `scratch/station/`): passed.
  - The pegs are on the grid with no shared holes.
  - The braid plate is unchanged (x -75.2..-26.4, z -132.9..-96.2). It sits 2.0 mm from the
    thin reel and from the drip tray, and 39.5 mm below the snips. The station-wide minimum
    gap is 1.55 mm, between two other modules.
  - No solid clashes.
  - All three bobbins' removal paths clear the neighbours.
  - The 52 mm roll's bottom is at station z -152.4. Nothing is below the braid.
- **GLB:** `NAME__loaded.glb`, `__empty.glb` and `__print.glb`.

## Open risks

- **Bore-edge chamfers.** A roll whose bore edge is heavily chamfered or rounded meets the
  nose with its own slope, not the 65 degree edge. With a 45 degree chamfer a sideways push
  needs 1.7 x the roll's weight with no friction and about 4 x at a friction of 0.3. That is
  weaker than the locked case, but the roll still has to lift, not slide. Expect a cross-hub roll to index the lip into one of its notches; that is
  harmless.
- **The 5.6 mm axle prints as a near-vertical post,** so bending crosses the layer lines.
  5 N at the lip is about 4 MPa. A snagged-braid yank of 20 N is about 15 MPa, near ASA's
  layer strength. The roll spins freely, so a yank only loads the axle if the braid snags.
- **Overrun.** There is no brake. A fast yank may spin the roll on and throw a loop of braid.
  If that bothers the owner, a felt dot on the hub seat adds drag.
- **Hoop row 1 has not been hung on a board.** The shared install-arc sweep with the fix
  shows rows 1-6 rigid-clear.
- **The roll's lower half is open** by design. The cost is that nothing guards its bottom rim,
  where only the user's hand goes.
- **Window apex.** The slicer bridges the last points at the window's apex, which is normal
  for a pointed roof.

## Scratch tools

- `scratch/lip_test.py`: retention (slide with no lift, minimum lift to pass) and clearance by
  region.
- `scratch/fea_probe.py`: FEA displacements at named points (same mesh, material and loads as
  `fea.py`).
- `scratch/support_where_xy.py`: maps Orca support, bridge and overhang lines back to holder
  coordinates.
- `scratch/station/`: a station check run with this build.

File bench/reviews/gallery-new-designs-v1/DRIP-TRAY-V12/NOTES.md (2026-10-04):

# v12 drip tray + vase liner (rev 2)

Builder: `bench/source/solder_v12/drip_tray.py`. Module name
`part-solder-drip-tray__v12__upright__fit-pf02c9-hoop5`; liner
`part-solder-drip-tray-liner__v12__vase-filled`. 5 cells (125 mm), station origin x 38.1,
z -127, hung under the barrels (`barrels-b6seats`, the final barrels module). Cells, height,
rows and position are unchanged; the `station-layout.json` entry is unchanged.

Rev 2 (2026-10-02), after Frodo's bench review (rev 2):

- A 20 x 3 mm finger scallop in the lip's top centre (finding 2), so the liner comes out
  from the outside of its front wall.
- The tip-height rule is a hard number, -141.6 station z, and the builder asserts it
  against the barrels-b6seats tools (finding 1).
- Spare liners are planned as one vase job of three (finding 3).
- The tray was rebuilt with `common.receiver`'s install-arc hoop fix (root clipped to r 2.95;
  the upright hoop is not dropped).

## Design and why

- **Bed face: the flat floor (upright).** The module is wide and shallow, so the floor is
  the first layer (125 x 80 mm) and every wall rises straight off it. Nothing prints in
  the air but the pegs: hooks on row 0, the PF07 #5 hoop on row 1 (band horizontal, so it
  flexes in X, in the print layers).
- **One open box.** The box has five parts:
  - a 2 mm floor;
  - two 2.4 mm side cheeks that run from the plate's top edge down at 28 deg to a 14 mm
    front post (chamfered top corner);
  - a 4 x 3 mm back curb;
  - a 6 mm front lip, a chamfered beam across the front (60 deg inner face, 3 mm flat top,
    55 deg outer face).

  The cheeks are deep webs that carry the tray's load into the plate beside the peg
  columns. Floor, cheeks, lip and plate make a stiff open box.
- **Finger scallop (rev 2).** A circular arc (r 18.2 mm) cut straight through the lip in Y
  at x 0: 20 mm wide at the lip top, 3 mm deep. Its faces all look up (33 deg from
  horizontal at the edges, flat at the bottom). In the upright print it is the top of a
  wall, so it adds no overhang and no island (checks: 0 non-peg overhang, 0 islands).
  - The lip stays 6 mm tall for 50 mm either side, so the liner's base still bears on
    full-height lip and retention is unchanged.
  - It is at the tray's centre, under the paste nozzle and 37 mm from the flux needle at
    the left end (the barrels review's finding 1: keep the liner grip away from the
    needle).
- **Plate.** Four pointed (55 deg) windows between the peg columns, 17.75 mm wide, sills
  flush with the curb top. No bridges, no flat roofs. The liner hides their lower half.
- **Liner.** A tapered rounded box (8.5 deg draft, corners r 8 at the base, r 11 at the
  rim), 116.2 x 63.45 mm at the rim, 110.2 x 57.45 mm at the base, 20 mm tall, about
  125 cm3 to the brim.
  - It fills the tray from the curb to the lip, so the catch window is as large as the
    module allows.
  - It is located by the curb and the lip at the base (1 mm each) and by the cheeks at the
    rim (2 mm each side, so the return needs no aiming).
  - The curb keeps the rim 2 mm off the plate windows, so the rim can't drop into one.
  - The draft lets spare liners nest. The vase profile is unchanged from rev 1.
- **Why not floor windows:** the floor is the backup catch when the liner is out, and a
  solid floor gives the full first layer. Why not cheek windows: with the cheek top at
  28 deg, any window under it needs a 55 deg roof, and the triangles that fit save about
  1 cm3 per cheek while costing cheek stiffness.

Design iterations (FEA, 5 N down at the lip centre, `pegs` support):

| version | change | lip sag |
|---|---|---|
| first cut | 45 deg cheeks dropping to a 5 mm lip at y 50 | 0.503 mm (fail) |
| deep cheeks | cheek web runs to a 14 mm front post | 0.358 mm |
| variant | lip 5 mm, 3.5 mm top, 55 deg out | 0.329 mm |
| variant | floor 2.4 mm (+3.9 cm3) | 0.294 mm |
| rev 1 | lip 6 mm, 3 mm top, 55 deg out (+1.7 cm3) | 0.261 mm |
| **rev 2** | **20 x 3 mm finger scallop; load moved to the scallop bottom** | **0.343 mm** |

## The tip-height rule (hard numbers; the builder asserts them)

**Every barrel tip must sit above station z -141.6 and inside station x -17.4 .. 93.6,
y 10.2 .. 68.4.**

- The height is the liner rim at -151.0, plus the 6.4 mm removal lift (to -144.6), plus a
  3.0 mm margin.
- The x and y window is the liner's inner rim, less 2 mm for liner play and drip spread.

`drip_tray.py` reads the barrels-b6seats module's own tool STLs and stops the build if a
tip breaks the rule. A lower cup, a longer needle, a taller liner or a thicker floor then
fails at build time instead of at the bench. The numbers are also in `__design.json` under
`tip_rule`.

| tip (barrels-b6seats) | station x, y, z | above -141.6 | above the lifted rim | x / y margin in the window |
|---|---|---|---|---|
| flux needle | 75.09, 55.89, -134.66 | 6.94 | 9.94 | 18.5 / 12.5 |
| paste nozzle | 38.09, 54.05, -120.86 | 20.74 | 23.74 | 55.5 / 14.4 |
| sucker nose | 1.07, 53.07, -116.03 | 25.57 | 28.57 | 18.5 / 15.3 |

Catch window, nominal inner rim (the liner has ±2 mm lateral and ±1 mm fore-aft play):

| | module-local | station |
|---|---|---|
| x | -57.5 .. 57.5 | -19.4 .. 95.6 |
| y (out of the board) | 8.2 .. 70.4 | 8.2 .. 70.4 |
| rim z | -24.0 | -151.0 |

## Covered range

The tray has no tool of its own. It serves the three barrels-b6seats tools, which are the
owner's own, photo-scaled and fixed, so nothing here needs measuring. Along each tool's
10 deg axis, it covers:

- **Flux syringe needle:** up to 7.0 mm longer than the photographed 8 mm needle, so
  about 15 mm overall.
  - A 1/2 in (12.7 mm) blunt dispensing tip fits: its tip lands at about -139.3, 2.3 mm
    above the rule and 5.3 mm above the lifted rim.
  - A 1 in (25.4 mm) tip does not fit. It would reach -151.8, below the rim at rest, and
    sit in the flux. Cut it down. The other fix would be moving the tray down one row,
    which leaves a 27 mm open band under the barrels; the plates either side are
    x-separated, but that move is not built or checked.
- **Paste syringe tip:** up to 21.1 mm longer than the photographed nozzle.
- **Sucker nose:** fixed. It has 25.6 mm in hand.
- **Lateral:** any tip from station x -17.4 to 93.6 and y 10.2 to 68.4. At those length
  limits the 10 deg lean moves the tips forward 1.2 mm (flux) and 3.7 mm (paste), to
  y 57.1 and 57.7, still at least 10 mm inside the window.
- **The liner** is printed for this tray. It holds about 125 cm3 to the brim, and flux
  and paste drips are a few drops a session.

## Using it

- **Hanging the tray:** hang it after the barrels. Hook row 0, then swing the bottom in
  until the row-1 hoop snaps. The plate gap to the barrels' underside is 1.6 mm.
- **Liner out** (to empty it):
  1. Put a fingertip in the scallop, against the outside of the liner's front wall.
  2. Press back and up. The wall flares out 8.5 deg, so the push lifts the front edge.
  3. Once the base edge is above the lip (6.4 mm), the fingertip is 3.4 mm under it in
     the scallop. Hook it and pull the liner forward.

  It passes under the stored nozzles with 9.9 mm to spare, and the hand never goes inside
  the flux-coated rim. Pinching the front wall's top still works too.
- **Liner back:** rest its back edge on the lip's 55 deg outer ramp and push it back. It
  rides over the lip and drops behind the 60 deg inner face. The cheeks funnel the rim to
  centre.
- **When bumped:** the liner has to climb the 6 mm lip to escape. Gravity seats it flat
  on the floor; there is no friction fit.
- **Cleaning and spares:** wipe the liner with IPA; ASA does not care. Liners nest, so
  keep the three from the spares job stacked under the bench and swap one in.
- **Leaning on it:** your forearm rests on the lip when you reach for a syringe. The lip
  has a 3 mm flat top and chamfers both sides; keep them.

## Print

- **Tray:** `part-solder-drip-tray__v12__upright__fit-pf02c9-hoop5__print-upright.stl`,
  floor on the bed, 125.0 x 90.5 x 51.4 mm. Slice with the owner's ASA preset via
  `print/slice_pf.py`:
  - Repro Normal 0.4;
  - PolyLite ASA calibrated;
  - 2 walls (Arachne), 20 % infill;
  - organic tree supports on the build plate only;
  - 5 mm outer brim.

  The job is `print/slice-v12/V12-drip-tray-ASA/V12-drip-tray-ASA.gcode.3mf`.
- **Liners: three in one job.** `scratch/slice_liner_plate.py stagger3 69 5` places three
  copies of `part-solder-drip-tray-liner__v12__vase-filled__print-vase.stl` (a filled
  solid, base on the bed) as separate objects.
  - Layout: two along Y and one turned 90 deg beside them, 69 mm rim to rim.
  - Settings: spiral vase (smooth), print sequence by object, 1 wall at 0.6 mm, 0 top
    layers, 5 bottom layers, 0 % infill, no supports, the preset's 5 mm outer brim. Same
    ASA filament and 0.2 mm process.
  - Job: `print/slice-v12/V12-drip-tray-liner-stagger3-ASA-vase/V12-drip-tray-liner-stagger3-ASA-vase.gcode.3mf`.
    The G-code was checked: `spiral_mode = 1`, `print_sequence = by object`, three
    objects, each spiralling.
  - Placement on the bed: rims at x 3-253, y 43.6-240.6, so 15.6 mm clear of the
    front-left exclusion zone (x 0-18, y 0-28) and the front purge line.
  - The brim's outer loop reaches x 0.86 and 255.14 in the G-code, inside Orca's 256 mm
    printable area.
  - Render: `scratch/liner_plate_x3.png`.

  Why this layout:
  - Orca allows several objects in spiral vase only when printing by object.
  - It then wants the P1S's 68 mm toolhead clearance between objects, because a 20 mm
    liner is taller than the 4.2 mm exposed nozzle. It rejected gaps of 10, 35 and 60 mm
    ("too close to others").
  - Three liners at 69 mm fit the 256 mm bed only staggered: 250 x 197 mm.

  Alternatives:
  - If a brim within 1 mm of the plate edge worries you, `stagger3 69 3` (3 mm brim)
    also slices. The brim then ends on the rim's outline, because the rim overhangs
    the base by 3 mm: 54.1 min, 28.67 g.
  - `column2 75` (two liners, 5 mm brim): `V12-drip-tray-liner-column2-ASA-vase`.
  - The single-liner job: `V12-drip-tray-liner-ASA-vase`.

## Numbers (last passing run)

- **Volume:** 57.42 cm3 solid (61.4 g solid ASA), against B6's 89 cm3, so 35 % less.
  Rev 1 was 57.60 cm3; the scallop and the hoop-root clip took the difference.
- **checks.py:** passed.
  - One watertight body.
  - Pose error 0.0 mm.
  - Non-peg overhang area 0; peg overhang 130.5 mm2; islands none.
  - Liner: deepest 0.0 mm; 152 contacts; centre of mass over the contacts.
  - Removal, lift 6.4 then 95 forward: minimum clearance 0.40 mm, at the lip top.
- **fea.py** (`pegs` support, solid ASA E 1800 MPa, 92,966 nodes):

  | load case (5 N) | deflection | stiffness |
  |---|---|---|
  | wag: sideways at the lip centre, under the scallop (the farthest tool-bearing point) | **0.021 mm** (limit 1.0) | 242 N/mm |
  | press: down at the lip centre, under the scallop | **0.343 mm** (limit 0.5) | 14.6 N/mm |
  | press on the full-height lip 15 mm off centre | 0.290 mm | 17.3 N/mm |
  | press at the floor centre | 0.202 mm | |
  | press at the lip near the cheek | 0.112 mm | |
  | 5 N inward on the cheek's top edge, mid-length | 0.301 mm | |

- **Tray slice:** 125.9 min, 41.03 g, 257 layers. From `slice_report`:
  - support_g 1.43;
  - bridge_g (air) 0.01;
  - internal_bridge_g 2.64;
  - overhang_wall_g 0.01.

  Toolpath audit (`scratch/gcode_where.py`, output in `scratch/gcode_where.txt`):
  - **Support:** 1.41 g, all at installed y <= -0.30, i.e. under the pegs, plus 0.02 g
    of interface.
  - **Air bridge:** 0.01 g, at the plate-window apex points.
  - **Internal bridge:** 2.64 g, solid over sparse infill in the floor, the curb, the
    lip and the plate top.
  - **Overhang wall:** 0.01 g, behind the plate (pegs).
- **Liner slices (vase, 0 support, 0 bridge):**

  | job | minutes | grams | layers |
  |---|---|---|---|
  | three in one job (stagger3, 5 mm brim) | 55.0 | 29.04 | 3 x 101 |
  | three in one job (stagger3, 3 mm brim) | 54.1 | 28.67 | 3 x 101 |
  | two in one job (column2, 5 mm brim) | 38.8 | 19.37 | 2 x 101 |
  | one | 22.6 | 9.7 | 101 |

- **Station** (`station.py` on `station-layout.json`, run into `scratch/station/` so the
  shared station folder is untouched): passed.
  - Pegs on holes; no shared holes.
  - Plates at least 1.55 mm apart (tray to barrels 1.6 mm).
  - No solid or stored-tool clashes.
  - Every removal path is clear.
  - `station.py` prints null for the liner path because nothing came within its 1 mm
    pre-filter.
- **Liner removal path in station coordinates** (`scratch/liner_path_station.py`, output in
  `scratch/liner_path_station.json`). This is lift 6.4, then 95 forward, against every
  neighbour. The rim's straight edges were densely sampled against the barrel tools,
  because vertex sampling alone read 13.9 mm at the flux needle.

  | neighbour | minimum distance | where on the path |
  |---|---|---|
  | barrels-b6seats flux needle | **9.95 mm** | lifted, 47.5 forward (the back rim passes under it) |
  | barrels-b6seats paste nozzle | 23.75 mm | lifted, 45.5 forward |
  | barrels-b6seats holder (underside, z -120) | 24.6 mm | lifted, at the start |
  | barrels-b6seats sucker nose | 28.57 mm | lifted, 45.5 forward |
  | tweezers plate (beside, x 102.6) | 6.4 mm | at rest |
  | braid holder | 17.96 mm | lifted |

## Open risks

1. **The scallop costs stiffness.** 5 N at the scallop's bottom sags 0.343 mm, against
   0.261 mm at the full lip in rev 1. The limit is 0.5.
   - FEA assumes solid ASA, and the lip prints with 2 walls and 20 % infill, so the real
     sag is higher.
   - If the lip feels soft under a resting forearm, slice the tray with 40 % infill. That
     costs a few grams and nothing else changes.
2. **The three-liner plate is tight on the bed.**
   - Its rims come within 3 mm of the bed's X edges, and the brim within 0.9 mm. Orca
     accepts it.
   - In Y it has 15.6 mm to the front-left exclusion zone and 15.4 mm to the back edge.
   - If the plate edge gives trouble, use the 3 mm brim variant or the two-liner job.
3. **The printed liner against the tray:** 2 mm side play and 1 mm front and back. The ASA
   preset's 99.46 % shrink is baked into the slice. If the liner binds, scale it to 99 % in
   X/Y; nothing else changes.
4. **The 0.6 mm vase wall** is a consumable. Pinching the rim flexes it; that is why the
   job prints three.
5. **ASA warp on a 125 x 80 mm first layer.** The front corners are chamfered; the back
   corners are square where the plate stands. Rely on the preset's 5 mm brim, and watch
   the back corners.
6. **The flux needle** hangs 14.7 mm below the barrels module at the left end, in the
   band a hand crosses for the liner. The scallop keeps the grip 37 mm away from it. A
   guard would be a separate clip-on print.
7. **Shared library note:** `render.py` titles its side view "from the left". Its camera is
   at -X, which per the brief is the user's **right**.

## Files

- `__installed.step/.stl`, `__print-upright.step/.stl`: the tray.
- `__design.json`: everything, including `tip_rule`, `tray.finger_scallop` and
  `catch_window`.
- `__checks-spec.json`, `__checks.json`, `__fea-spec.json`, `__fea.json`, `__slice.json`.
- `__loaded/empty/front/side/print.png` and `.glb`.
- `__tool-liner.stl`: the in-use liner. `__ref-b6-nozzles.stl`: the barrel nozzle tips, for
  reference only.
- `part-solder-drip-tray-liner__v12__vase-filled__print-vase.stl/.step`, `__installed.step`:
  the liner.
- `__slice.json`: one liner. `__plate-x3__slice.json`: three.
- `scratch/`:
  - `slice_liner_plate.py` and `look_liner_plate.py`: the spares plate, with its render
    `liner_plate_x3.png`.
  - `slice_liner_vase.py`: one liner.
  - `liner_path_station.py`: the station path clearances.
  - `gcode_where.py`: the toolpath audit.
  - `station/`: the station check run.
  - `drip_tray_before_rev2.py`: the rev 1 builder.

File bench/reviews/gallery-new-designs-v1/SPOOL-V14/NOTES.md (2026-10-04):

# Open spool storage cradle v14

**Reviewable geometry prototype, not a qualified print release.** This implements the
operator's corrected storage use: take the spool to the bench, then return it to an open
curved-bottom tub. There is no lid, axle, latch, spring, wire guide or feeding function.
The earlier [v13 gated mechanism](../spool-front-v13/SUPERSEDED.md) is superseded;
its final records remain unchanged.

## Current facts and design

The photographed cyan part is consistent with the two-column braid v12 cradle, rather
than the reel-thin holder. See the owner's [physical record](../../spool-physical-2026-10-03/).
The MAIYUM label specifies Sn63/Pb37, 1.8% flux and 100 g solder. Approximately 55 mm OD
and 30 mm overall width are product-family estimates, **not measured dimensions**;
100 g is not a measured total spool mass. The braid's original 38–52 OD × 6–12 width
coverage does not qualify this wider solder spool.

The new provisional coverage is **40–65 mm OD × 8–34 mm overall width**, including
40 × 8 and 40 × 12 narrow bobbins. It is a roomy bench-spool cradle, not a fitted seat.
Spool axis is X, away from the board is +Y, up is +Z. No required bore size is imposed:
all interference evidence uses conservative solid full-OD cylinders. Flanges, bore and
winding shapes in the white render stand-ins are illustrative only.

The two mounting columns remain X = ±12.7 mm, with hook row 0 and hoop row 1,
PF02#9/PF07#5 geometry and 48.8 mm body width. The generator calls the unchanged
shared receiver. Its board-side geometry below Y = 0.15 has zero symmetric-difference
volume against that receiver. This preserves the geometry, not a new physical fit rating.

Print face was selected first: right cheek (installed −X) on the bed, keeping the existing
hoop orientation. A radius-34 mm curved floor spans ±35° about its low point. Its shell
is 3.6 mm thick, with a 5 mm rear support, a left cheek, shallow side rims and two local
mounting-rail flanges. Two backplate windows remain open. There is no need for a solid
sheet behind the payload to claim the module's exterior perimeter.

The bottom is Z = −68 mm. The front floor rises **6.15 mm** from that bottom. Round
spools with radius below 34 mm settle into a local gravitational minimum. This gives
passive engagement: a horizontal outward slide hits the curved rise. It is not a latch
and has no rated bump acceleration, retention force or drop resistance. Smaller spools
sit lower in the same trough. Narrow bobbins can lean sideways and have less tipping
margin; their static seat checks do not establish bump stability.
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

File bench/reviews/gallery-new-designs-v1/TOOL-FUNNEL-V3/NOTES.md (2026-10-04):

# Rectangular tool funnel v3 — rounded exterior and softened rim

The owner's “fillets and chamfers” revision adds a restrained manufactured finish to the upright, open-bottom funnel. The simple rectangular passage, two-cell mount and straight vertical pickup remain. This is a fresh styled body, not a claim that its upper exterior is still v1-identical.
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

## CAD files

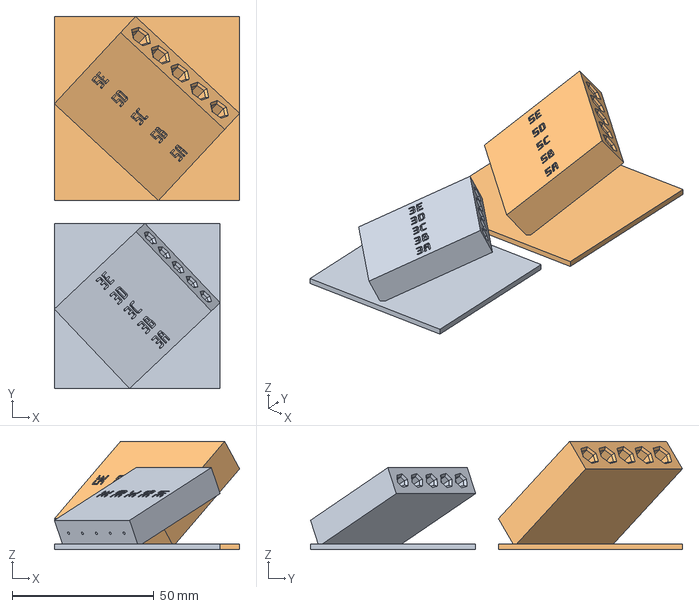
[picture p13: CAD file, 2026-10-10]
bench/reviews/key-fan-audit-v1/HX04-fit-v6__3mm-5mm__fan-angle__print.step
65.3 x 131.1 x 38.2 mm

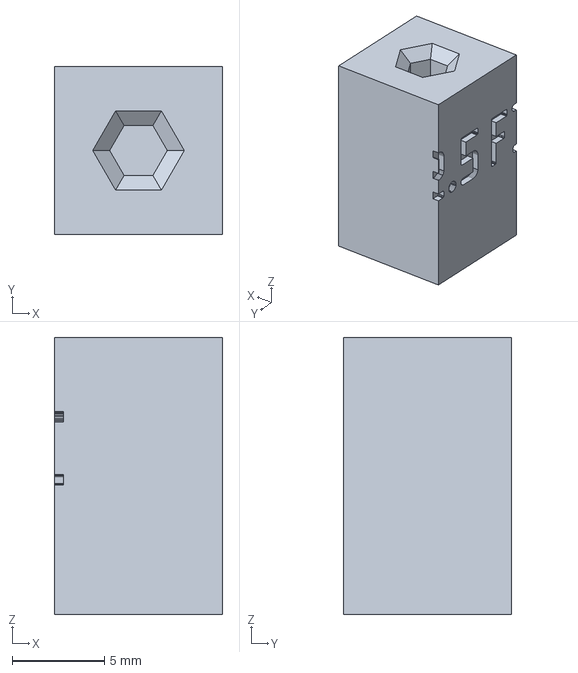
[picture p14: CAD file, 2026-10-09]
bench/reviews/tee-fit-v2-flats-c10/T2.5_F_C10__installed.step
9.12 x 9.12 x 15.0 mm

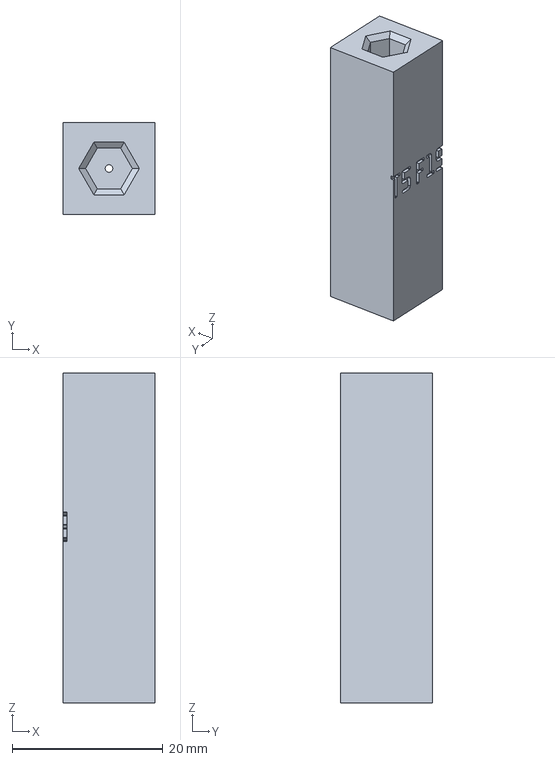
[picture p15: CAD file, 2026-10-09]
bench/reviews/tee-fit-v4-guide40/T5_F_C19__installed.step
12.2 x 12.2 x 43.8 mm

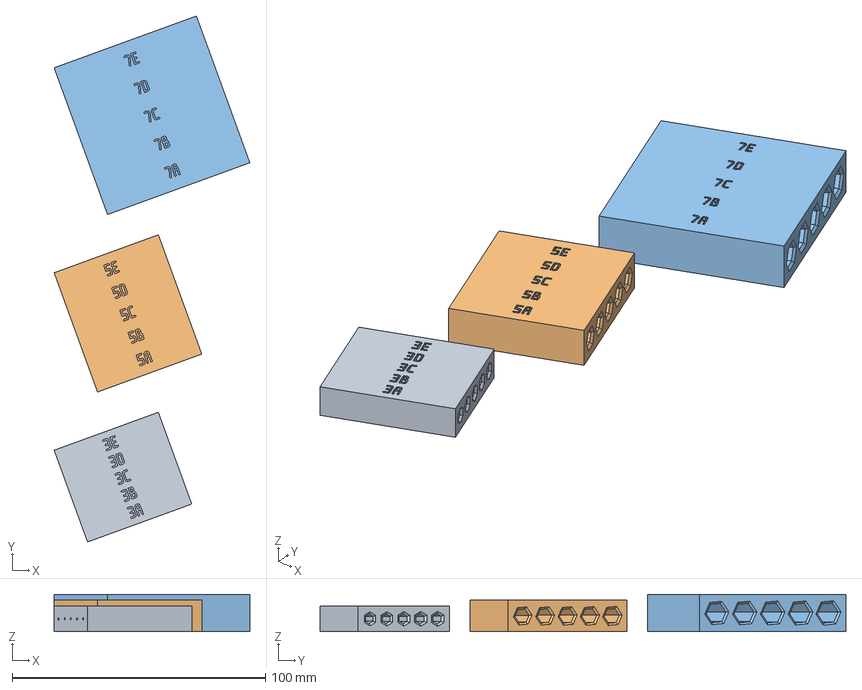
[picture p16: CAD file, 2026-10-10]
bench/reviews/tee-fit-v5-spectra/HX05-fit-v5.FCStd
77.3 x 207.7 x 14.7 mm
3 mm spectrum A-E
5 mm spectrum A-E
7 mm spectrum A-E

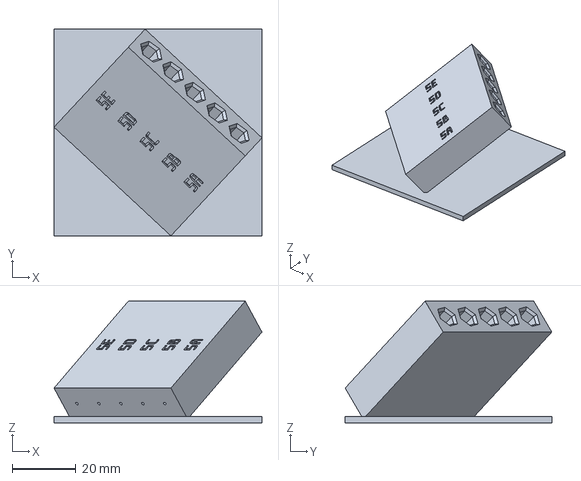
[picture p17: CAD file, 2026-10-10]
bench/reviews/tee-fit-v6-fan/HX05-fit-v6-5mm__fan-angle__print.step
65.3 x 64.9 x 38.2 mm

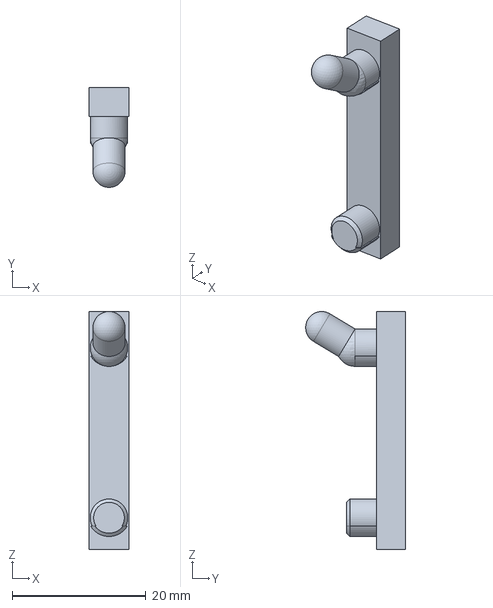
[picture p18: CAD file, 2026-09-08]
bench/source/gallery_current_mounts_v1/station_snapshot/reference/conformal_120.step
6.00 x 14.9 x 35.5 mm

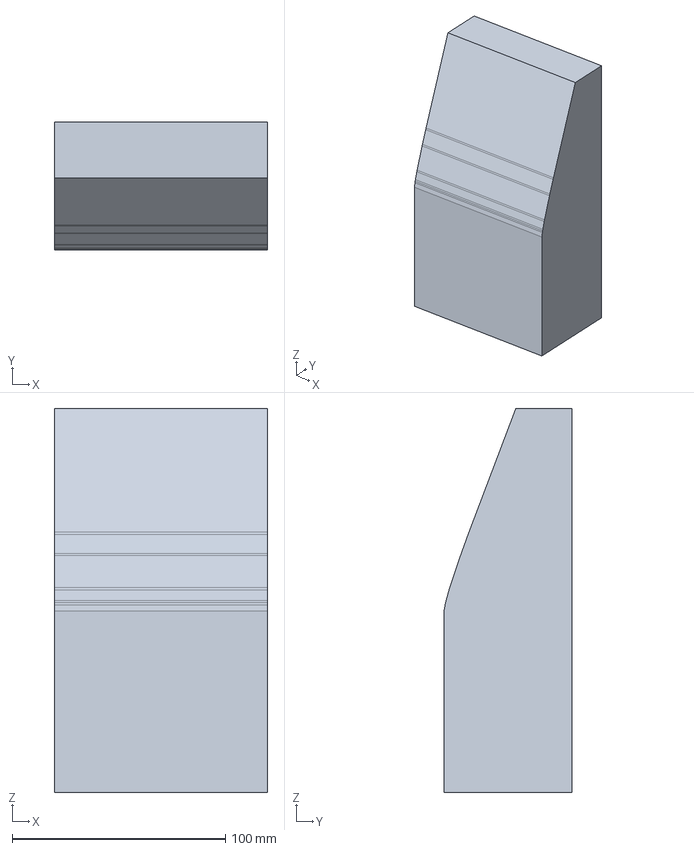
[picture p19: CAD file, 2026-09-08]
cad/conformal/host-envelope/allowed_host_volume.step
100.0 x 60.0 x 180.0 mm

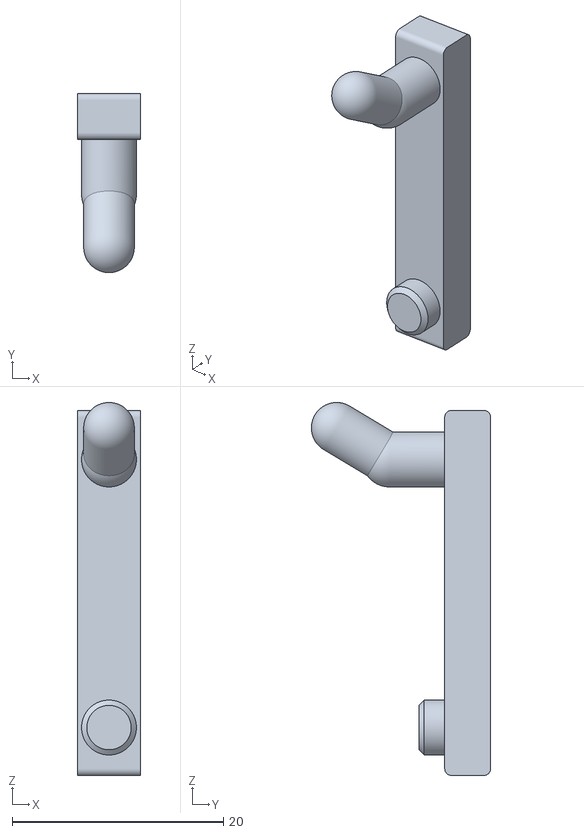
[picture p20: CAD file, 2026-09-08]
cad/round_true_1_4_design_reference.stl
6.00 x 17.0 x 35.3

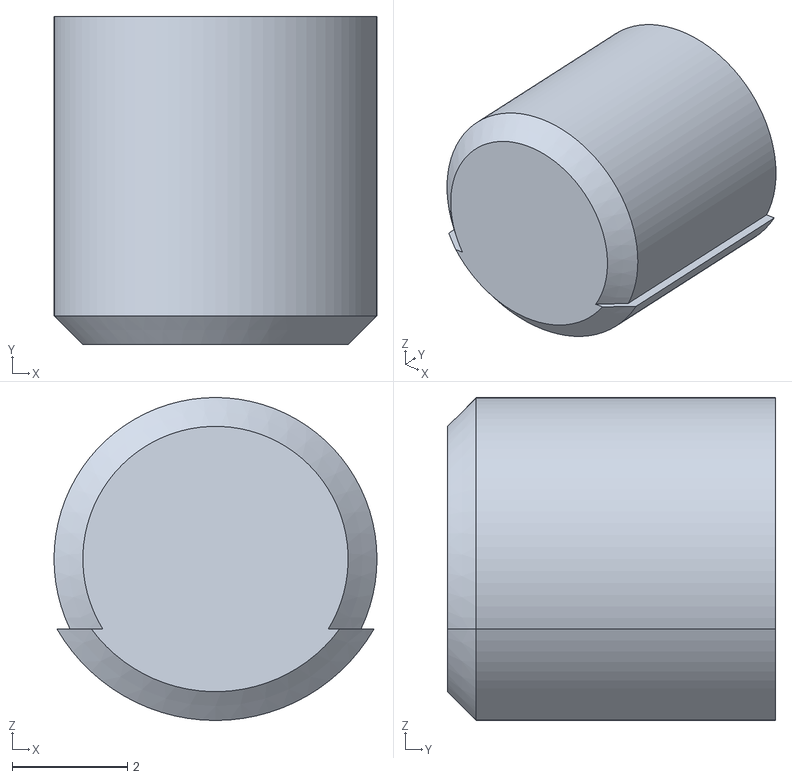
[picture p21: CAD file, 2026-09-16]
docs/gallery/arrays/lower-locator.stl
5.60 x 5.69 x 5.60

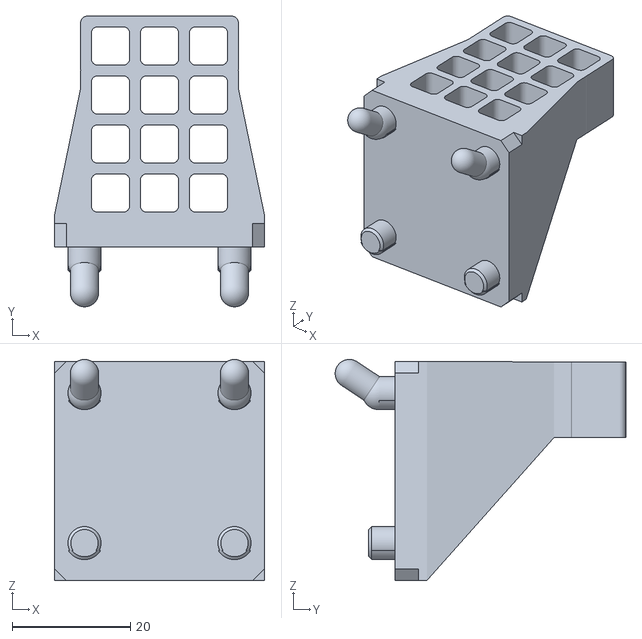
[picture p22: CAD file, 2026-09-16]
docs/gallery/arrays/P01-12/model.stl
35.6 x 49.2 x 37.4

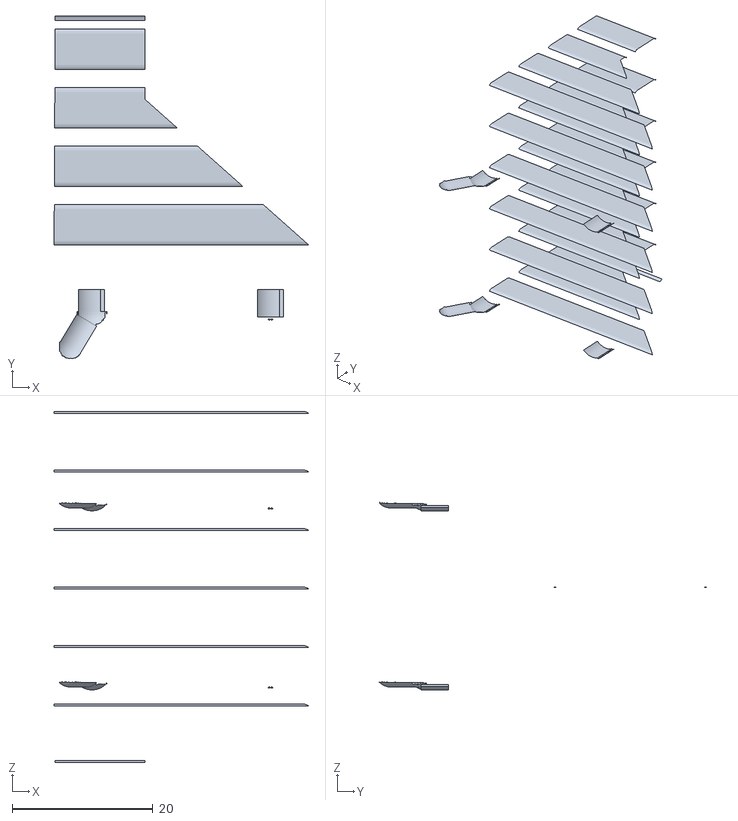
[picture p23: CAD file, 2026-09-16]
docs/gallery/arrays/P01-24/print-overhangs.stl
36.1 x 48.6 x 49.8

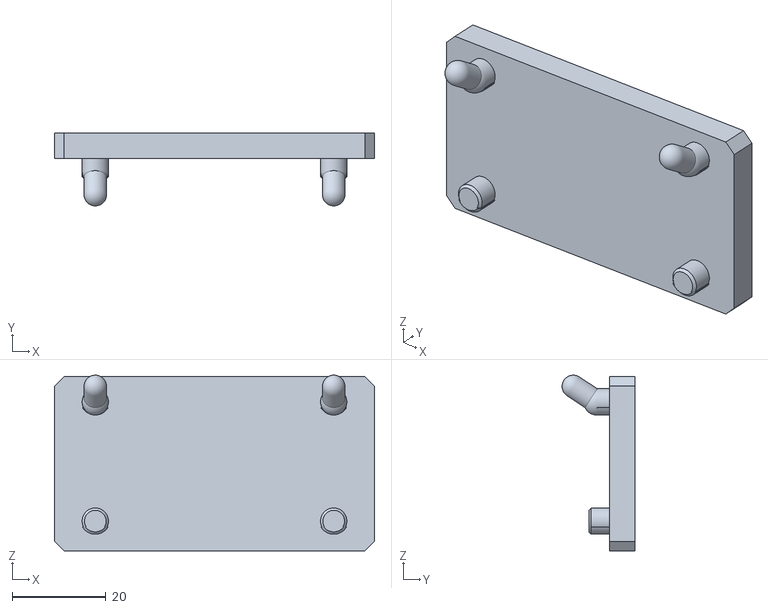
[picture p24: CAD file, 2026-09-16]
docs/gallery/arrays/P01-32/receiver.stl
68.2 x 15.5 x 37.4

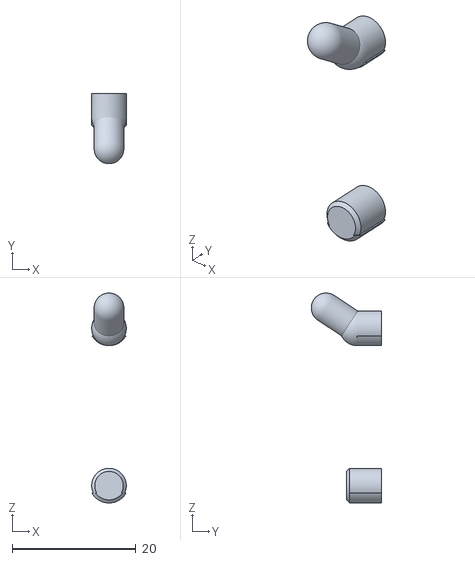
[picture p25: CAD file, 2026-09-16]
docs/gallery/arrays/P01-48/functional-peg.stl
5.60 x 11.4 x 33.9

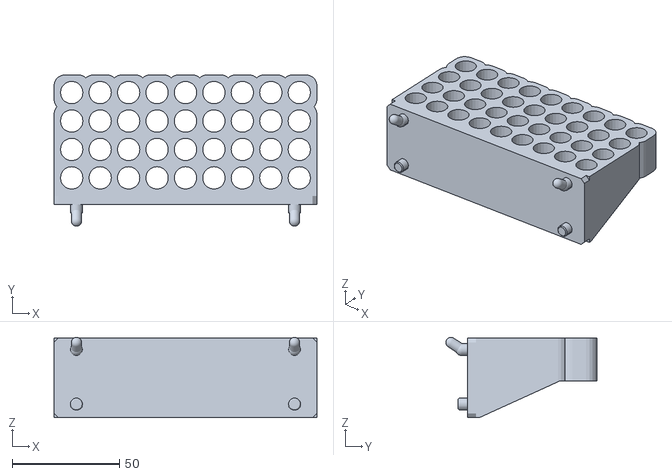
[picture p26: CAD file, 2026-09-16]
docs/gallery/arrays/P09-36/raw-union.stl
122.5 x 70.5 x 37.4

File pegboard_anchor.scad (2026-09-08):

// Pegboard anchor — millimeters; X width, Y toward you, Z up.
// use <pegboard_anchor.scad>; then pegboard_anchor(board_thickness=3.94);
// Fuse your mount with the front spine at Y=spine_depth (default4.5).
// Thickness changes require a new fit/motion check. Do not scale the whole part.
// Canonical validated CAD is generated by anchor.py + motion_design.py.
$fn = 96;

module pegboard_anchor(
    board_thickness = 3.94,
    hole_diameter = 6.35,
    pitch = 25.4,
    width = 4.0,
    neck_height = 3.6,
    spine_depth = 4.5,
    spine_height = 34.6,
    pull_clearance = 0.47,
    elbow_offset = undef,
    tongue_run = 5.0,
    tongue_rise = 3.0,
    locator_depth = 2.3,
    locator_height = 3.0,
    front_gap = 0.15,
    seat_drop = 0.12
) {
    $fn = 96;
    assert(board_thickness>0 && hole_diameter>width && width>0);
    chord_half = sqrt(hole_diameter*hole_diameter-width*width)/2;
    assert(neck_height < 2*chord_half);
    z0 = -chord_half + neck_height/2 + seat_drop;
    slope = tongue_rise/tongue_run;
    radius = neck_height/2;
    elbow = is_undef(elbow_offset) ? pull_clearance-front_gap
        -(2*chord_half-radius)/slope+radius*sqrt(1+1/(slope*slope))
        : elbow_offset;
    yrear = -board_thickness-elbow;
    chamfer = min(0.7, locator_depth*0.35, locator_height*0.3);
    zl = -pitch+z0;
    // [2D u,2D v,extrusion] -> global[Y,Z,X].
    multmatrix([[0,0,1,0],[1,0,0,0],[0,1,0,0],[0,0,0,1]])
    linear_extrude(height=width,center=true,convexity=10)
    union() {
        hull() {
            translate([1.4,z0]) circle(d=neck_height);
            translate([yrear,z0]) circle(d=neck_height);
        }
        hull() {
            translate([yrear,z0]) circle(d=neck_height);
            translate([yrear-tongue_run,z0+tongue_rise]) circle(d=neck_height);
        }
        offset(r=0.65) offset(delta=-0.65)
            translate([front_gap,4.2-spine_height])
                square([spine_depth-front_gap,spine_height]);
        polygon([
            [0.6,zl-locator_height/2],
            [-locator_depth+chamfer,zl-locator_height/2],
            [-locator_depth,zl-locator_height/2+chamfer],
            [-locator_depth,zl+locator_height/2-chamfer],
            [-locator_depth+chamfer,zl+locator_height/2],
            [0.6,zl+locator_height/2]
        ]);
    }
}

// Preview is the default anchor. use<> excludes this top-level preview.
pegboard_anchor();

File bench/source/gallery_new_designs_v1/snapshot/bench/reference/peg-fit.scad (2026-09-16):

// THE CANONICAL FIT SOURCE. Python reads these scalar assignments; OpenSCAD
// includes this same file on every render. Change fit here, then regenerate.
// Dimensions mm. Negative clearance deliberately relies on board/plastic flex.
PEG_FIT_REVISION = "rear-tongue-3p80-interference0p05";
PEG_BOARD_GRIP = 3.80;
PEG_PULL_CLEARANCE = -0.05;
PEG_TONGUE_RUN = 5.0;
PEG_TONGUE_RISE = 3.30;
PEG_HOLE_DIAMETER = 6.35;
PEG_DIAMETER = 5.6;
PEG_TONGUE_DIAMETER = 4.8;
PEG_FACE_Y = 0.15;
PEG_ROOT_Y = 1.40;
PEG_SEAT_DROP = 0.12;
PEG_PITCH = 25.4;

// Optional full-height locator array, first used by tweezer module v7.
// Existing hooked mounts keep their settled geometry. These short straight
// locators replace the loose lower locator only for explicit array callers.
// Diametral interference is a physical trial, not a measured retention force.
PEG_ARRAY_DIAMETRAL_INTERFERENCE = 0.10;
PEG_ARRAY_DEPTH = 3.80;
PEG_ARRAY_TIP_DIAMETER = 5.20;
PEG_ARRAY_LEAD_LENGTH = 1.00;

// Same primitive construction as peg_profile.py, with the exact baseline lower
// locator supplied separately. No old upper-hook STL is imported.
module canonical_functional_peg(lower_locator_mesh) {
    r=PEG_DIAMETER/2; tr=PEG_TONGUE_DIAMETER/2;
    slope=PEG_TONGUE_RISE/PEG_TONGUE_RUN;
    offset=PEG_PULL_CLEARANCE-PEG_FACE_Y-(PEG_HOLE_DIAMETER-r)/slope+tr*sqrt(1+1/(slope*slope));
    ey=-PEG_BOARD_GRIP-offset;
    z=-(PEG_HOLE_DIAMETER-PEG_DIAMETER)/2+PEG_SEAT_DROP;
    a=[0,PEG_ROOT_Y,z]; b=[0,ey,z]; c=[0,ey-PEG_TONGUE_RUN,z+PEG_TONGUE_RISE];
    R=PEG_HOLE_DIAMETER/2; cutoff=PEG_SEAT_DROP-R*cos(60);
    module segment(p,q,radius) {
        d=q-p;
        translate(p) rotate(a=acos(d.z/norm(d)),v=[-d.y,d.x,0]) cylinder(r=radius,h=norm(d),$fn=96);
    }
    union() {
        intersection() {
            union() {
                translate(a) sphere(r=r,$fn=96);
                translate(b) sphere(r=r,$fn=96);
                translate(c) sphere(r=tr,$fn=96);
                segment(a,b,r);segment(b,c,tr);
                intersection() {
                    translate([0,ey,PEG_SEAT_DROP]) rotate([-90,0,0]) cylinder(r=R,h=PEG_ROOT_Y-ey,$fn=96);
                    translate([-R-1,ey-1,PEG_SEAT_DROP-R-1]) cube([2*R+2,PEG_ROOT_Y-ey+2,cutoff-(PEG_SEAT_DROP-R-1)]);
                }
            }
            translate([-20,-60,-50]) cube([40,60+PEG_ROOT_Y,100]);
        }
        import(lower_locator_mesh,convexity=10);
    }
}

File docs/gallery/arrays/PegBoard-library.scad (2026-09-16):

// PEGSTR - Pegboard Wizard
// Design by Marius Gheorghescu, November 2014
// Update log:
// November 9th 2014
//		- first coomplete version. Angled holders are often odd/incorrect.
// November 15th 2014
//		- minor tweaks to increase rendering speed. added logo. 
// November 28th 2014
//		- bug fixes

// preview[view:north, tilt:bottom diagonal]

// width of the orifice
holder_x_size = 10;

// depth of the orifice
holder_y_size = 10;

// hight of the holder
holder_height = 15;

// how thick are the walls. Hint: 6*extrusion width produces the best results.
wall_thickness = 1.85;

// how many times to repeat the holder on X axis
holder_x_count = 1;

// how many times to repeat the holder on Y axis
holder_y_count = 2;

// orifice corner radius (roundness). Needs to be less than min(x,y)/2.
corner_radius = 30;

// Use values less than 1.0 to make the bottom of the holder narrow
taper_ratio = 1.0;


/* [Advanced] */

// offset from the peg board, typically 0 unless you have an object that needs clearance
holder_offset = 0.0;

// what ratio of the holders bottom is reinforced to the plate [0.0-1.0]
strength_factor = 0.66;

// for bins: what ratio of wall thickness to use for closing the bottom
closed_bottom = 0.0;

// what percentage cu cut in the front (example to slip in a cable or make the tool snap from the side)
holder_cutout_side = 0.0;

// set an angle for the holder to prevent object from sliding or to view it better from the top
holder_angle = 0.0;


/* [Hidden] */

// what is the $fn parameter
holder_sides = max(50, min(20, holder_x_size*2));

// dimensions the same outside US?
hole_spacing = 25.4;
hole_size = 6.0035;
board_thickness = 5;


holder_total_x = wall_thickness + holder_x_count*(wall_thickness+holder_x_size);
holder_total_y = wall_thickness + holder_y_count*(wall_thickness+holder_y_size);
holder_total_z = round(holder_height/hole_spacing)*hole_spacing;
holder_roundness = min(corner_radius, holder_x_size/2, holder_y_size/2); 


// what is the $fn parameter for holders
fn = 32;

epsilon = 0.1;

clip_height = 2*hole_size + 2;
$fn = fn;

module round_rect_ex(x1, y1, x2, y2, z, r1, r2)
{
	$fn=holder_sides;
	brim = z/10;

	//rotate([0,0,(holder_sides==6)?30:((holder_sides==4)?45:0)])
	hull() {
        translate([-x1/2 + r1, y1/2 - r1, z/2-brim/2])
            cylinder(r=r1, h=brim,center=true);
        translate([x1/2 - r1, y1/2 - r1, z/2-brim/2])
            cylinder(r=r1, h=brim,center=true);
        translate([-x1/2 + r1, -y1/2 + r1, z/2-brim/2])
            cylinder(r=r1, h=brim,center=true);
        translate([x1/2 - r1, -y1/2 + r1, z/2-brim/2])
            cylinder(r=r1, h=brim,center=true);

        translate([-x2/2 + r2, y2/2 - r2, -z/2+brim/2])
            cylinder(r=r2, h=brim,center=true);
        translate([x2/2 - r2, y2/2 - r2, -z/2+brim/2])
            cylinder(r=r2, h=brim,center=true);
        translate([-x2/2 + r2, -y2/2 + r2, -z/2+brim/2])
            cylinder(r=r2, h=brim,center=true);
        translate([x2/2 - r2, -y2/2 + r2, -z/2+brim/2])
            cylinder(r=r2, h=brim,center=true);

    }
}

module pin(clip)
{
	rotate([0,0,15])
	cylinder(r=hole_size/2, h=board_thickness*1.5+epsilon, center=true, $fn=12);

	if (clip) {
		//
		rotate([0,0,90])
		intersection() {
			translate([0, 0, hole_size-epsilon])
				cube([hole_size+2*epsilon, clip_height, 2*hole_size], center=true);

			// [-hole_size/2 - 1.95,0, board_thickness/2]
			translate([0, hole_size/2 + 2, board_thickness/2]) 
				rotate([0, 90, 0])
				rotate_extrude(convexity = 5, $fn=20)
				translate([5, 0, 0])
				 circle(r = (hole_size*0.95)/2); 
			
			translate([0, hole_size/2 + 2 - 1.6, board_thickness/2]) 
				rotate([45,0,0])
				translate([0, -0, hole_size*0.6])
					cube([hole_size+2*epsilon, 3*hole_size, hole_size], center=true);
		}
	}
}

module pinboard_clips() 
{
	rotate([0,90,0])
	for(i=[0:round(holder_total_x/hole_spacing)]) {
		for(j=[0:max(strength_factor, round(holder_height/hole_spacing))]) {

			translate([
				j*hole_spacing, 
				-hole_spacing*(round(holder_total_x/hole_spacing)/2) + i*hole_spacing, 
				0])
					pin(j==0);
		}
	}
}

module archived_pinboard(clips)
{
	rotate([0,90,0])
	translate([-epsilon, 0, -wall_thickness - board_thickness/2 + epsilon])
	hull() {
		translate([-clip_height/2 + hole_size/2, 
			-hole_spacing*(round(holder_total_x/hole_spacing)/2),0])
			cylinder(r=hole_size/2, h=wall_thickness);

		translate([-clip_height/2 + hole_size/2, 
			hole_spacing*(round(holder_total_x/hole_spacing)/2),0])
			cylinder(r=hole_size/2,  h=wall_thickness);

		translate([max(strength_factor, round(holder_height/hole_spacing))*hole_spacing,
			-hole_spacing*(round(holder_total_x/hole_spacing)/2),0])
			cylinder(r=hole_size/2, h=wall_thickness);

		translate([max(strength_factor, round(holder_height/hole_spacing))*hole_spacing,
			hole_spacing*(round(holder_total_x/hole_spacing)/2),0])
			cylinder(r=hole_size/2,  h=wall_thickness);

	}
}

module holder(negative)
{
	for(x=[1:holder_x_count]){
		for(y=[1:holder_y_count]) 
/*		render(convexity=2)*/ {
			translate([
				-holder_total_y /*- (holder_y_size+wall_thickness)/2*/ + y*(holder_y_size+wall_thickness) + wall_thickness,

				-holder_total_x/2 + (holder_x_size+wall_thickness)/2 + (x-1)*(holder_x_size+wall_thickness) + wall_thickness/2,
				 0])			
	{
		rotate([0, holder_angle, 0])
		translate([
			-wall_thickness*abs(sin(holder_angle))-0*abs((holder_y_size/2)*sin(holder_angle))-holder_offset-(holder_y_size + 2*wall_thickness)/2 - board_thickness/2,
			0,
			-(holder_height/2)*sin(holder_angle) - holder_height/2 + clip_height/2
		])
		difference() {
			if (!negative)

				round_rect_ex(
					(holder_y_size + 2*wall_thickness), 
					holder_x_size + 2*wall_thickness, 
					(holder_y_size + 2*wall_thickness)*taper_ratio, 
					(holder_x_size + 2*wall_thickness)*taper_ratio, 
					holder_height, 
					holder_roundness + epsilon, 
					holder_roundness*taper_ratio + epsilon);

				translate([0,0,closed_bottom*wall_thickness])

				if (negative>1) {
					round_rect_ex(
						holder_y_size*taper_ratio, 
						holder_x_size*taper_ratio, 
						holder_y_size*taper_ratio, 
						holder_x_size*taper_ratio, 
						3*max(holder_height, hole_spacing),
						holder_roundness*taper_ratio + epsilon, 
						holder_roundness*taper_ratio + epsilon);
				} else {
					round_rect_ex(
						holder_y_size, 
						holder_x_size, 
						holder_y_size*taper_ratio, 
						holder_x_size*taper_ratio, 
						holder_height+2*epsilon,
						holder_roundness + epsilon, 
						holder_roundness*taper_ratio + epsilon);
				}

			if (!negative)
				if (holder_cutout_side > 0) {

				if (negative>1) {
					hull() {
						scale([1.0, holder_cutout_side, 1.0])
		 					round_rect_ex(
							holder_y_size*taper_ratio, 
							holder_x_size*taper_ratio, 
							holder_y_size*taper_ratio, 
							holder_x_size*taper_ratio, 
							3*max(holder_height, hole_spacing),
							holder_roundness*taper_ratio + epsilon, 
							holder_roundness*taper_ratio + epsilon);
		
						translate([0-(holder_y_size + 2*wall_thickness), 0,0])
						scale([1.0, holder_cutout_side, 1.0])
		 					round_rect_ex(
							holder_y_size*taper_ratio, 
							holder_x_size*taper_ratio, 
							holder_y_size*taper_ratio, 
							holder_x_size*taper_ratio, 
							3*max(holder_height, hole_spacing),
							holder_roundness*taper_ratio + epsilon, 
							holder_roundness*taper_ratio + epsilon);
					}
				} else {
					hull() {
						scale([1.0, holder_cutout_side, 1.0])
		 					round_rect_ex(
							holder_y_size, 
							holder_x_size, 
							holder_y_size*taper_ratio, 
							holder_x_size*taper_ratio, 
							holder_height+2*epsilon,
							holder_roundness + epsilon, 
							holder_roundness*taper_ratio + epsilon);
		
						translate([0-(holder_y_size + 2*wall_thickness), 0,0])
						scale([1.0, holder_cutout_side, 1.0])
		 					round_rect_ex(
							holder_y_size, 
							holder_x_size, 
							holder_y_size*taper_ratio, 
							holder_x_size*taper_ratio, 
							holder_height+2*epsilon,
							holder_roundness + epsilon, 
							holder_roundness*taper_ratio + epsilon);
						}
					}

				}
			}
		} // positioning
	} // for y
	} // for X
}


module pegstr() 
{
	difference() {
		union() {

			pinboard();


			difference() {
				hull() {
					pinboard();
	
					intersection() {
						translate([-holder_offset - (strength_factor-0.5)*holder_total_y - wall_thickness/4,0,0])
						cube([
							holder_total_y + 2*wall_thickness, 
							holder_total_x + wall_thickness, 
							2*holder_height
						], center=true);
	
						holder(0);
	
					}	
				}

				if (closed_bottom*wall_thickness < epsilon) {
						holder(2);
				}

			}

			color([0.7,0,0])
			difference() {
				holder(0);
				holder(2);
			}

			color([1,0,0])
				union() {} // Original pins omitted: custom pegs are received in the host.
		}
	
		holder(1);
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

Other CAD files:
cad/conformal/conformal_120_side_unsupported.stl
cad/host-envelope/allowed_host_volume.step
docs/gallery/arrays/P09-48/original.stl
bench/source/gallery_new_designs_v1/snapshot/bench/reviews/pf02-fits/peg-fit-clamp-0.49.scad
Pegboard_Print_Options.3mf
Round_Print_Options.3mf
bench/reviews/key-fan-audit-v1/HX04-fit-v6__3mm-5mm__fan-angle__print.stl
bench/reviews/key-fan-audit-v1/HX04-v2__uncompensated-brace-project__reslice.3mf
bench/reviews/tee-fit-v2-flats-c10/HX05-fit-v2.FCStd
bench/reviews/tee-fit-v2-flats-c10/HX05-fit-v2__left-end__print.step
bench/reviews/tee-fit-v2-flats-c10/HX05-fit-v2__left-end__print.stl
bench/reviews/tee-fit-v2-flats-c10/L2_F_C10__installed.step
bench/reviews/tee-fit-v2-flats-c10/T5_F_C10__installed.step
bench/reviews/tee-fit-v3-guide40/HX05-fit-v3.FCStd
bench/reviews/tee-fit-v3-guide40/HX05-fit-v3__left-end__print.step
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

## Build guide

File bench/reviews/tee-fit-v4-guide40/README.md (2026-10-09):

# Fit coupon v4 — increased clearance and vents

The v3 print was snug. This revision adds **0.18 mm total across flats**: **0.19 mm per flat / 0.38 mm total**, giving the 5 mm key a **5.38 mm AF bore**. Each square 3 mm socket floor has a **1 mm diameter through vent**, retaining a shoulder to stop even the 2 mm shaft. The straight guides remain 40 mm for L2, T2.5 and T5, and 80 mm for T10, plus the 0.8 mm entrance. Handles stay flat-to-flat. F19 labels identify the increased clearance.

Build using FreeCAD 1.1.3:

```bash
.local-runtime/freecad-python bench/source/tee_racks_v1/fit_coupon_v4.py --out bench/reviews/tee-fit-v4-guide40
.local-runtime/freecad-python bench/source/tee_racks_v1/tools/check_fit_coupon.py bench/reviews/tee-fit-v4-guide40
```

The coupon source specifies the revised clearance and vent; the unchanged socket policy supplies guide lengths. Sources and native/export checks accompany the CAD. The full racks retain their earlier geometry pending this trial. Actual slicing, physical fit and loads remain unqualified. Use the owner's printer and filament profile; no G-code is supplied.

At this allowance the L2 bore permits full rotation; T2.5 permits approximately ±26.1°, T5 ±8.72° and T10 ±4.02°. Guide length limits rocking, while hex clearance sets rotational play. The prior v3 release is preserved as history.

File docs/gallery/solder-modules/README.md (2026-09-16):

# Solder station B6

Seven independently mounted modules. Read index.html for dimensions, print faces,
support previews and limitations. All pegs use the shared interference profile.
Print individual holder/print-pose files; assembly.step is an installed reference.
Choose your verified material settings. Review G-code is not a released print job.
Tools are existing planning proxies. Physical fit and surface finish remain untested.

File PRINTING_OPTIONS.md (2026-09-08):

# Two print orientations

The anchor now has an optional set of cut-away webs for printing upright as part of a larger holder. The finished pegboard interface remains the same after you trim the webs flush.

| Option | Use | Preparation |
|---|---|---|
| **Flat on its side** | Isolated anchors and holders that can share that orientation | Print the existing flat STL. Automatic supports off. |
| **Upright with cut-away webs** | Holders that stand on the bed with the pegboard face vertical | Print the supported STL, or fuse the supported CAD into your holder. Snip all four webs off afterward. |

`Pegboard_Print_Options.3mf` contains both options, separated on the bed. It is a standard geometry-only 3MF: choose your printer and filament, then slice the option you want. It does not contain machine-specific settings or G-code.

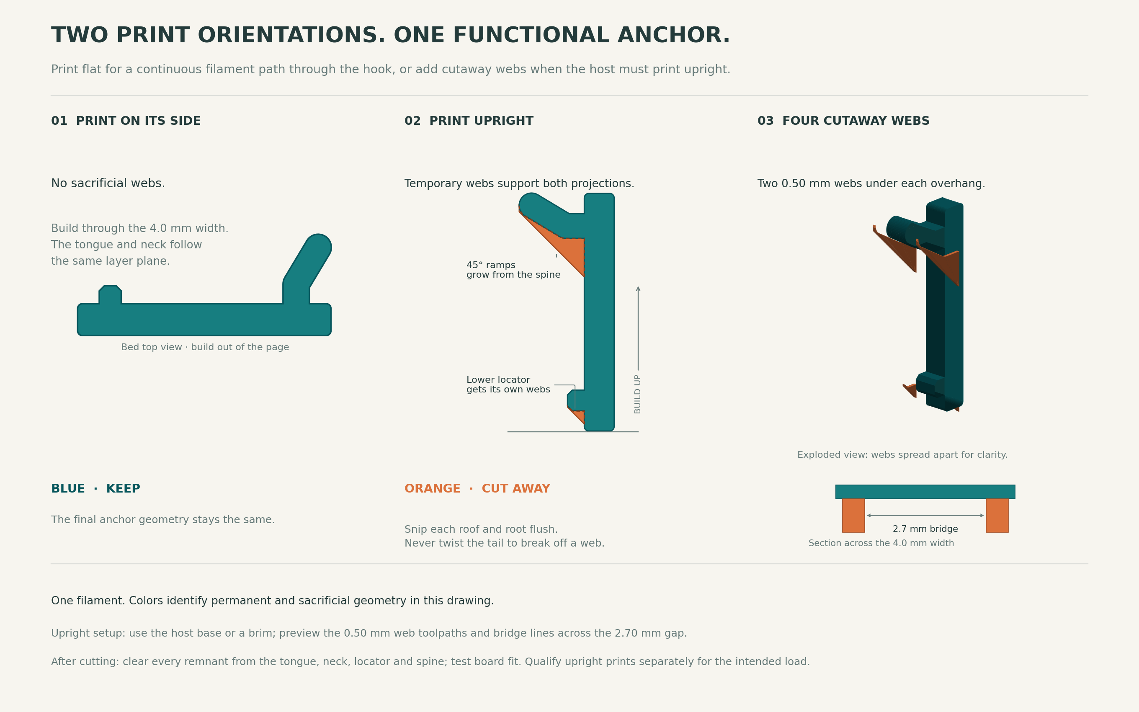
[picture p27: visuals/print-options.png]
Flat and upright print options


## The sacrificial webs

Two **0.50 mm** membranes sit beneath each projection: four membranes total. Their lower edges grow rearward at **45°**, beginning on the existing spine. Each membrane sits **0.15 mm inside** the outer face, preserving the outer bearing corners. The gap between the paired membranes is **2.70 mm** across the anchor width. The material above that gap prints as a short bridge.

The default four webs add approximately **22.6 mm³** of plastic, about 3% of the bare anchor volume. They are thin cutting targets; they are not permanent reinforcing gussets. The upper and lower supports follow their respective undersides, including the rounded rear tip.

Print the anchor and webs together in one material. The orange color in the illustration and reference STEP identifies material to remove; it does not require a second filament.

## Starting print setup

- 0.4 mm nozzle and 0.20 mm layers. Use five walls for the flat version.
- For the upright anchors, use a local modifier with **two walls and 100% infill**. This leaves room for roof skin to bridge across the supporting webs. The rest of a larger holder can keep its own wall settings. Inspect the neck to confirm it slices solid.
- Use a calibrated filament profile. PETG is a starting material choice; the model does not require a special support filament.
- For the isolated upright coupon, use a **6 mm brim**. The finished holder may already provide enough bed contact.
- Turn automatic supports off for the isolated coupons. A larger host can need its own supports.
- Confirm that the preview includes all four thin webs. Their nominal 0.50 mm thickness should produce a continuous extrusion with an appropriate thin-wall/variable-width configuration.
- The first roof spans **across X**, between the webs. Check the bridge direction in the actual slicer you use; generic geometric checks do not establish every slicer's toolpath choices.
- Keep seam buildup away from the surfaces that pass through the pegboard holes. Trim strings and any first-layer swelling before checking the fit.

Prusa's design guidance supports modeled break-away supports, short bridges, sufficient thin-wall thickness, and chamfers at downward-facing edges. It also explains why print orientation affects the finished part. These recommendations guide the geometry; they do not certify this particular print. [Prusa: Modeling with 3D printing in mind](https://help.prusa3d.com/article/modeling-with-3d-printing-in-mind_164135)

## Remove the webs

1. Hold the solid spine. Use small flush cutters to snip each membrane along its attachment to the spine.
2. Snip the membrane's upper attachment along the underside of the hook or locator. Work from the nearest side face.
3. Remove the thin web and pare remaining material flush with the original blue surface shown in the diagram. Preserve the outer bearing corners.
4. Check that both holes accept the part and that the finished tongue seats normally.

Avoid twisting the upper tongue to break off a web. The webs have fused roots and roofs; cut them deliberately rather than relying on an uncontrolled brittle fracture. They must come off before installing the anchor.

## Parametric integration

Use the same dimensions for the supported version and the final anchor:

```python
from print_scaffold import make_printable_upright

anchor_and_webs = make_printable_upright(board_thickness=3.94,
                                        hole_diameter=6.35)
result = your_holder.union(anchor_and_webs)
```

The common design coordinates remain X across the board, Y toward the user, and Z up. Fuse your holder to the front spine at Y=4.5 mm. `cad/anchor_upright_supported.step` keeps those coordinates; the STL shifts the same solid onto Z=0 for printing.

`cad/upright_cutaway_reference.step` separates the blue retained body and orange sacrificial webs for inspection. The fused supported STEP/STL is the printable model.

## What we verified

- Supported CAD is one valid solid; the STL is watertight.
- All five board/hole presets pass geometric web-growth checks at 0.20 mm layers and four layer phases.
- Each ramp grows rearward by at most one layer height per layer, corresponding to 45°.
- The original motion study remains applicable to the original interface after complete, flush removal of the sacrificial material.
- CuraEngine 5.0.0 sliced both orientations with automatic supports off. Its actual upright toolpaths preserve all four 0.50 mm webs and create roof skin across X with the local settings above. See `SLICER_CHECK.md` and `slicer_check.json` for the complete generic test setup, bridge settings, and limits. A Bambu Studio or OrcaSlicer preview still needs its own check; generic Cura toolpaths do not certify a printer profile.

The upright version has a different layer orientation. Its supports solve deposition beneath the projections; they do not give it the same layer load path as the flat version. Use a physical print and representative load test to compare the two orientations. Neither version has a load rating.

Rebuild the upright CAD with `python print_scaffold.py`; rebuild the two-option 3MF with `python write_print_3mf.py`.

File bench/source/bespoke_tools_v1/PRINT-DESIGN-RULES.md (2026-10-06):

# Bespoke holder print and use rules

Review date: 2026-10-05. Owner priority: easy FDM quality.

## Sources and precedence

Read the repository's AGENTS.md, BENCH_HOLDERS.md, current connector integration notes,
publication/README.md, and the frozen solder_v12/BRIEF.md. Also reviewed the active
peg-bt2 workbench's bench/README.md, recovery/handoff records, tool-source notes,
module reviews, physical feedback and current funnel/tweezer/spool design notes.
The workshop human-factors report, screwdriver revisions, sampler and magnetic-pocket
notes, and current-mount per-part orientation records supply specific precedents.
PRINTING_OPTIONS.md, SLICER_CHECK.md and ROUND_SLICER_CHECK.md describe historical
anchor preparations; their support geometry and qualification apply to those exports.

BENCH_HOLDERS.md now permits a flat bottom, inverted flat top or right cheek, with
accessible local supports and actual toolpath inspection. The older v12 brief requires
body geometry that supports itself, with organic supports at the pegs. New designs
use that stricter body-geometry target to serve the owner's easy-FDM request.

## Design gates

1. Choose a substantial planar bed face before the holder body. Respect ASA warp,
   first-layer contact, print height and the 256 mm bed including brim/supports.
2. Body geometry grows from the bed. Downward faces stay within 45 degrees from
   vertical; pointed roofs use at least 50 degrees. Horizontal overhangs need material
   beneath them. Declared bridges require real end anchors, backing, and span <=10 mm.
   Check local starting islands as well as face angles.
3. Peg supports must be accessible for removal. Check the actual owner's ASA slice,
   including support contact, bridge direction, hoop paths and seam buildup.
4. Flexing hoops and any added clips flex in the layers. Use the correct existing hoop
   orientation for each pose. Preserve the PF02 #9 hook and PF07 #5 root-clipped hoop.
5. Width is 25.4*cells-2 mm; use two mounting columns where they fit. Integral peg roots
   overlap the receiver. Preserve the rear contact plane and board-side geometry.
   Each complete body needs its own installation screen; old nominal certificates
   cannot qualify the changed fit.
6. Use webs, flanges and triangulation for stiffness. At the farthest tool-bearing
   point with peg nodes fixed, target <=1.0 mm sideways and <=0.5 mm down under 5 N.
   Report assumptions for solid isotropic ASA and the limits of printed infill.
7. Walk through hold, grasp, removal, return and incidental bumps. Provide forgiving
   entry, positive gravity retention, clear grip space and short one-handed motion.
   Check neighboring stored tools and the complete swept tool, including its tips.
8. Protect exposed points. Keep refill and cleaning access practical. Blind seats are
   required for glue-in parts. Simplicity and access take priority over material saving.
9. Source real common tool dimensions. Keep manufacturer data, downloaded CAD,
   reconstructed engineering surfaces and conservative fit envelopes explicitly labeled.
   The owner does not measure tools. Preserve existing owner-specific barrel seats.
10. Use consistent edge finishing that preserves the bed face and printable undersides.
    Verify native solids, round trips, meshes, orientation, tool fit and paths; inspect
    rendered installed, loaded and print views. Record volume, bed contact, stiffness,
    slice time/material/support and remaining physical checks with the matching source.

## Candidate decisions

- HX01: upright floor. Long key legs point upward; short feet sit on a floor between
  open-front guides. A 9 mm lift clears the front lip. Check slender-key lean and grasp.
- TM01: upright floor and side webs; low front lip. The 94 mm pocket accommodates
  a tape-measure case plus clip up to 92x48 mm. Check grip and short pickup.
  The owner stores the multimeter flat elsewhere; a display cradle is excluded.
- CL01: full right-cheek section on the bed. A broad saddle supports a coiled cable
  bundle and a raised nose retains it. Check grip, saddle contact and coil clearance.

CAD checks, linear stiffness, sliced toolpaths and physical print/use results are
separate evidence. Physical tests remain pending until performed.

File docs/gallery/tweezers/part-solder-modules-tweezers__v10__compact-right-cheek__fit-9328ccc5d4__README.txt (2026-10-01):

Tweezers v10: compact, continuous RIGHT cheek
============================================

The tools may move independently of the mounting grid. The four measured-tool
cradles now sit beside the actual right cheek: negative X when facing the board.
The cheek is a continuous 3 mm wall. Each existing contoured floor overlaps it
by 2.4 mm; the broad support blocks used in v9 are gone. The heels move 12 mm
closer to the board and 6 mm lower. Slot spacing remains 42 mm and tilt 40 deg.

Keep points DOWN while storing, inserting and removing. Grasp the fused heel,
lift vertically 5 mm, then move LEFT (+X in the repository coordinates) 30 mm.
Insertion reverses that path. The open arms have no closing jaw. The guide
supports the lower arm's broad face over stations 6..64 mm from the heel; the
working points remain beyond it, with no point floor or stop.

The supplied tweezer model is placed using a proper rigid rotation, not a
reflected tool mesh. Its arms swap through a 180-degree roll about the length
axis; the heel-to-point axis stays downward. This establishes its orientation
in the station, and does not add a flipping step during insertion or removal.

The exact v9 receiver and pegs are preserved: two upper PF02 #9 hooks, four
loose bearing pegs and two PF06-style bottom latches. The receiver width is
48.8 mm, mounting columns remain X = +/-12.7 mm, and occupied rows remain
0, 2, 4 and 6. The scalar fit source SHA256 is
9328ccc5d4bfd4ef7f5c88efb68cc4714da8b0017cd2c2d0a85e52ddc1669f3a.
The included fit-pf02-clamp-0.49.scad is a frozen provenance snapshot, not a
second editable fit authority. That hash identifies the PF02 clamp snapshot;
the exact v9 baseline STEP hash and
the retained-geometry comparison also identify the added ribs and latch.

Print preparation and fit
-------------------------
The full print STL lies on its actual negative-X right cheek, with Z minimum
zero. The face is solid and continuous; no windows cut through the bed face.
The projecting pegs still require local support and an inspection of actual
toolpaths. These are CAD/mesh print-preparation inputs, not printer-ready jobs.

Print the small single-throat coupon first. Hold it at the station's 40-degree
incline with the points down. Check the measured tweezer's body
seat, lateral rocking, arm opening and short lift/left movement. The nominal
side clearance remains 0.08 mm per edge over the closer guides, with 0.35 mm
aft and lower-face allowance. The outline/opening are reconstructed estimates.
The coupon includes a short flat cheek to reproduce this print orientation.

All four slots repeat the supplied 122.76 mm bent tweezer. The measured aft
dimensions are TOTAL fused thicknesses: 1.17 mm at the heel, then 1.31 mm a
little forward. The 1.47 mm photo dimension belongs to a separated forward arm.
Other tweezer shapes are not fitted or physically tested by this model.

Verification
------------
The design-and-checks JSON records the actual CAD volumes, print bounds, bed
contact area, baseline hash, exact receiver/peg comparison and mesh hashes.
review.py checks the actual exported meshes with the other three tools present.
Adaptive translation distance bounds cover both complete removal segments.
The reverse path establishes the same nominal insertion clearance. The point
region is checked separately; a downward displacement checks for a body stop.
Those results exclude hand clearance, print tolerance, bending and contact
forces. The interfering v9 peg fit remains its own physical prototype.

CAD volume savings compare the regenerated complete v9 and v10 solids. They
are not a prediction of sliced filament savings or a load/strength rating.

Rebuild
-------
Use Python 3.12 with ../tweezers_v8/requirements.txt for front.py and review.py.
Use a complete FreeCAD Python runtime for holder.py. The v10 source depends on
the unchanged v8 guide/model source and the existing bench geometry envelope.

  cadpy front.py BUILD_DIR
  freecad-python holder.py BUILD_DIR V9_INSTALLED_STEP
  cadpy review.py BUILD_DIR

The self-contained release bundle includes the exact regenerated v9 baseline
STEP from the v9 development release, the minimal public source/reference tree,
exported CAD/meshes and review
evidence. Supply that baseline STEP to holder.py. To rebuild v9 itself, use the
unchanged bench/source/tweezers_v9 sources on the fit-ladder branch at 9f5c923.
Raw photographs, photogrammetry scans and printer credentials are excluded.

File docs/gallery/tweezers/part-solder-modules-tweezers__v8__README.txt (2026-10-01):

Tweezers v8: tip-down long body cradles
=====================================

Store, insert and remove with the points DOWN. Grasp the broad rear end.
Lift vertically 5 mm, then move left 30 mm. Insert along the reverse path.
The holder supports the lower arm's broad outer face and guides its edges;
the upper arm has no closing jaw. The throat ends before the slender working
end. There is no floor under the points. This is a prototype for the supplied
bent tweezer, not a universal four-tool fit.

The v7 board receiver, two upper hooks and twelve straight locators are
retained by an exact CAD intersection. The shared e586ab4ff6 peg fit is
unchanged. It still uses interference/compliance; the new front body does
not turn that into a rigid collision-free or physically qualified mount.

Design dimensions
-----------------
122.76 mm measured tweezer length; 1.17 mm TOTAL fused rear thickness;
1.31 mm TOTAL aft thickness slightly forward. The 1.47 mm photo is a
separated forward arm. Joined length, exact measuring stations, outline
and natural opening are reconstructed estimates; see parameters.json.

58 mm contoured body support, from 6 to 64 mm forward of the heel.
Closer lateral guides over stations 42..61 mm, 0.08 mm per edge.
Aft lateral clearance 0.35 mm per edge; lower-face allowance 0.35 mm.
2.4 mm walls and 0.6 mm rounded rail corners. The low rails allow a short
lift before the left departure; they do not form an opposed spring clamp.
The tight lateral allowance should be checked on the small test piece.

48.8 mm mounting width, original 42 mm slot spacing and 40 degree tilt.
Full installed bounds: 48.8 x 116.98 x 227.0 mm (X/Y/Z). The long throats
extend farther forward and higher than v7 to reach the upper body. The
points remain within the original receiver's lower height in the nominal
loaded arrangement. All four slots repeat the same measured tweezer.

Printing and fit
----------------
Print the SINGLE-THROAT TEST PIECE first. Hold it at the installed angle;
check that the tool settles on the body, stays open, rocks acceptably and
clears both rails with a short lift. Check that no point touches plastic.
Do not force a tight fit; increase the side_clearance parameter in holder.py
if needed. Only print the full station after this check.

STL units are millimetres. The supplied STL is on its right cheek, Z=0.
The full part fits a 256 mm square plate geometrically (227 x 116.98 mm),
with supports and a brim. The coupon has the same throat, without a mount.
Use the intended printer, plate and filament profile. Remove support from
the guide surfaces and check for burrs before trying the real tool.

OrcaSlicer 2.4.2 geometry review: P1S 0.4, 0.20 mm Standard, three walls,
15% infill, normal supports on the plate, 5 mm outer brim. Generic PLA
system preset used for geometry review only. Full station sliced without
reported warnings; estimated 3 h 31 min, 135 g including support/brim.
No review G-code or machine-ready job is published. The included JSON
records settings and results; no physical fit/load/wear testing is claimed.

Checks and reproduction
-----------------------
Installed, print and coupon CAD are valid single solids. STLs are closed
with consistent outward winding; STEP re-import volume matches. The
unchanged mounting/receiver region has zero symmetric volume difference.
Nominal open-pose tools have 0.078 mm minimum holder/neighbour clearance.
Point-region clearance is at least 3.02 mm at rest. A downward displacement
of 0.75 mm reaches the body support in the rigid nominal model. This is
not an elastic seating or contact-force prediction.

Removal uses actual triangle meshes with neighbours present, a 5 mm lift
and 30 mm left motion. Adaptive endpoint distances bound clearance over
each complete rigid translation, not only sampled poses. The conservative
bound is 0.0405 mm. These results apply to the reconstructed nominal tool,
not printing tolerance, hands, bending or a different tweezer. New host
board-front clearance was separately checked on the existing v7 mounting
pose paths; the original peg compliance assumptions remain in effect.

In the self-contained CAD bundle, run with Python 3.12:
  python -m venv .venv
  .venv/bin/pip install -r requirements.txt
  .venv/bin/python holder.py --output regenerated
  .venv/bin/python review.py regenerated

In the repository, give --baseline the v7 installed STEP from its original
release (holders-2026-09-16). Its required SHA256 is
2abdd83699589dac57290c444aeb298cfc429a8d2d4eb9effbe83d5bf0c20f37.
The bundle includes this exact input, source, fitted tool parameters,
open/closed reference STL models, printable exports, previews and checks.
Raw photos and photogrammetry scans are excluded.

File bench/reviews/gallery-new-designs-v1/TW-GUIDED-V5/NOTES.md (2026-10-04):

# Inward 20 v5 — open curved holder guides

This four-stack uses an open **6 mm radius holder roof**, with a free final settle above the retained taller fin. It retains 20° inward slope, 15° lateral seating, A/4.0 and the 23.05 mm plate-plane tip gap. The roof is a passive lead-in, not a latch or close-fitting tunnel. Natural guidance is a physical-test question, not established by a clear CAD route.

[Loaded](loaded.png), [empty](empty.png), [bare body](empty-body.png), [empty guide close-up](guide-empty-closeup.png), [arm approaching guide](guide-closeup.png), [CAD section](guide-section.png), [four guide sections](four-guide-paths.png), [independent pickup](pickup.png), [print pose](print-pose.png), [actual toolpaths](toolpaths.png). Views use the complete selected triangle meshes and ordinary depth-buffer rendering. Camera crops do not remove triangles. Orange denotes the separate fins; the prepared job is all yellow.

**Geometry and occupied space.** We increased the pitch modestly to make room for the guide and straightforward pickup. Vertical pitch is 28 mm, up from 23 mm: stations 1–4 move by global Z offsets 0/−5/−10/−15 mm from v4. Their angles, floor/pocket/fin shapes and tool seating relative to each floor remain the same. Two mounting columns, row 0 hooks / row 2 locators / row 4 hoops, bearing seams and peg roots remain unmodified. Exact CAD comparisons in [candidate.json](candidate.json) show zero rear-peg symmetric difference, zero floor/pocket inverse-translation difference, zero added guide material in blind pockets or floor contact skins, and zero inverse-translation difference for each fin. Tool export reorders triangle records, so [checks.json](checks.json) compares translated geometry bidirectionally and complete triangle incidence after vertex matching, independent of record order.

The upper rail rises nominally 6 mm and the lower seats extend 15 mm downward. The actual exterior bounds are reported below; these include filleted outlines and differ slightly from nominal rail changes. The rear window frame is 7 mm deep and tapers back before the receiving floors; its reinforcement does not consume the A4 seating gap. The perimeter flange is 20 mm deep across X, with a continuous rounded outline, and the inner bottom-web edge is lowered locally to retain the previously opened tip-clearance space. There is no separate sticking-out latch/tab. Width remains 48.8 mm and maximum front Y remains 135.579 mm. Hands and the pickup sweep require additional free space; the installed body outline is not the hand/removal envelope.

**Guide and motion.** Facing the board, operator-left is +X and right is −X. Global Y points away from the board and Z up. U=(0,cos 20°,sin 20°) follows the holder slope; V=(0,−sin 20°,cos 20°) is its normal. The roof occupies U 104–134.18745 mm at the top station and is translated with each lower station. Its underside radius is 6 mm, roof thickness 2.4 mm, exposed mouth fillet 0.7 mm. The underside ends at 80°, before it becomes a vertical hook. It blends into the right cheek/roof; it does not touch fragile tips or cross a fin during the selected motion.

The complete reference-tool route is reversible, without rotating the tool:

1. From stored, lift 6.75 mm freely along +Z until the arms clear the taller fin.
2. Sweep up-left: for θ decreasing 90°→0°, Xoffset=6(1−sinθ), Zoffset=6.75+6cosθ/cos 20°, Yoffset=0. This finishes 6 mm left and 13.1351 mm above the stored pose.
3. Continue 2 mm left to clear the open mouth, then withdraw 135 mm along (0,cos 20°,sin 20°). The final translation relative to stored is approximately (+8,+126.859,+59.308) mm. The reference tool is fully away from the board/holder at the end; fingertip clearance is additional.

Return reverses that route: approach above-left, sweep right/down beneath the curved roof, align above the fin, then settle the last 6.75 mm downward freely. The guide does **not** force a lateral arm movement through the fin. These waypoints describe the tested envelope; the user should not need a precision sequence or extra grip in ordinary use. If the actual tool requires that, the prototype fails the handling goal even if its nominal CAD route is clear.

[guide-contacts.json](guide-contacts.json) measures all four actual clipped guide meshes, rather than assuming that top and lower roofs are interchangeable. Its mesh-to-mesh minimum gap is separate from the nearest sampled robust-arm vertex and corresponding guide point. At 15°–75° on the curved segment the nominal gaps are approximately 0.195–0.294 mm, the open start about 0.606 mm and the relieved end about 1.152 mm. The selected route intentionally has clearance; an over-high presentation would meet the roof. These values are **nominal CAD diagnostics, not validated printed-fit allowances or a measured capture envelope**. Surface texture, ASA shrink, support removal, actual arm spread and friction may change contact substantially. The diagnostic records the distance of each sampled contact region from the fragile tip; the contact is on the robust upper arm.

**Independent paths and installation.** Each of the four complete reference meshes is checked against the complete body, board, all four fins and three stored neighbors. Free lift/left steps are at most 0.25 mm, arc steps 1° (at most about 0.112 mm), and outward steps 0.5 mm. The same configurations in reverse cover return. Full mesh Boolean intersections are used, not sparse sampled tool vertices. The bottom tray's complete 15 mm tip region is also swept through the extra 19.05 mm clearance volume; no obstructing web is moved into that space. Reported results below are sampled geometric screens, not continuous certificates or dynamic capture rates.

The changed bare front body has a fresh installation screen against the board front plane along the existing reference trajectory; it does not reuse a v4 body certificate. The exact unchanged rear peg/hoop geometry retains intentional fit/interference assumptions. Nominal-anchor evidence is not a physical fit qualification of the fitted pegs or hoops. Install the bare body before loading fins/tools.

**Stiffness.** The selected changed body has a fresh eight-case solve: independent 5 N side/down handling loads at all four seats, targets 1.0/0.5 mm at each load point. Max-anywhere deflection is reported separately. The model is solid isotropic ASA, E 1800 MPa, ν0.35, with fixed peg nodes and a nominal 2 mm second-order tetrahedral mesh. It does not represent the sliced two-wall/20% structure, layer anisotropy, actual board motion, guide contact force, fin glue, strength/fatigue, bumps or capture. No spring simulation or broad capture study was run. Failed preliminary attempts are preserved privately. Their side-deflection results, bottom-tip clash and guide-end ledge are not selected evidence.

**Print and physical acceptance.** The body prints on its right cheek; four exact v4 fins stand on their broad station 51 ends, 20 mm tall. Fin overhang/island checks pass without exceptions. The generic body overhang screen honestly fails at one accessible top-guide patch; organic support is explicitly required there and at the pegs. The final local job permits support to start on the printed cheek beneath the guide; bed-only trials did not generate the required interface. Actual toolpath support locations, bed bounds and five objects are checked separately. Remove the top-guide support cleanly without flattening the curved contact surface. Reachability is visible in the empty close-up; support release and surface finish remain physical tests.

Dry-fit the original fin feet, bond with the established assembly method, keep glue off catching surfaces and allow full cure. Follow [OWNER-TEST.md](OWNER-TEST.md): actual tools in every position, all neighbors loaded, natural return/pickup, false perches, fragile tips, finger clearance and guide surface quality. Retain 20° until those tests: stronger inward gravity at 30°/45° would also reduce normal spacing in the four-stack and does not ensure that an arm lands around the fin. No unbuilt-angle qualification is claimed.

**Selected numerical results.**

Body solid volume: 108.645316 cm³ (v4: 88.044766 cm³). Installed XYZ bounds: (-24.400000, -10.790000, -126.558115) to (24.400000, 135.578669, 30.731490) mm. Actual bottom growth is 14.8944 mm and top growth 5.7883 mm versus the filleted v4 outline. Four fins retain 484.878294 mm³ each. No material/print-weight reduction is claimed.

| Station | Side load-point / max anywhere (mm) | Down load-point / max anywhere (mm) | Tip-region nearest body gap (mm) |
|---|---:|---:|---:|
| 1 | 0.7212 / 0.7774 | 0.2165 / 0.2810 | 11.2707 |
| 2 | 0.8978 / 0.9573 | 0.2076 / 0.2805 | 1.9108 |
| 3 | 0.8641 / 0.9287 | 0.2077 / 0.2998 | 11.2707 |
| 4 | 0.6744 / 0.7242 | 0.2021 / 0.2882 | 1.9108 |

All eight load-point targets pass. Mesh: 162705 nodes, 89225 elements, 5350 fixed peg nodes. See [part-tweezers__inward20-v5-A4p0-guideR6-p28__right-cheek__fit-pf02c9-hoop5__fea.json](part-tweezers__inward20-v5-A4p0-guideR6-p28__right-cheek__fit-pf02c9-hoop5__fea.json) and [fea-provenance.json](fea-provenance.json). The nearest material gap is **not** the 23.05 mm distance to the plate plane: trays 2/4 are closer to the reinforced rear frame. Actual bent-tip variation still needs inspection.

All four tip-extension screens have zero intersection. Tool translation error is at most 3.82e-6 mm, with identical mapped triangle connectivity. All up-left, mouth-clearance and outward samples have zero intersection; the largest rest/lift trace is 8.87e-14 mm³, below the unchanged 1e-8 mm³ numerical criterion. The new front-body installation screen covers 2,973 poses with at most 0.05 mm vertex motion per subdivision and 0.005 mm surface tessellation deflection. Minimum front-plane clearance is approximately zero (5.96e-9 mm); this is nominal contact, not a positive manufacturing reserve.

The guide-end ledge was a real 0.187446 mm termination offset. [guide-junctions.json](guide-junctions.json) now verifies coincident STEP front planes at all four guide ends; the lower guides join the preceding floor on that plane. The selected full-body close-up shows the removed triangular ledge. [guide-contacts.json](guide-contacts.json) locates the sampled robust-arm contact regions about 104.6–106.8 mm in Y from the reference tip, separately for every station.

**Local print preparation.** The selected archive is `print/slice-tweezer-inward20-v5/TW-INWARD20-v5-ASA-yellow-organic.gcode.3mf`.

- SHA256 `aec8afb2e2a4f5f62aa83c73797a3f665b3b4f4e2049d8f2140c95dccc2d0b85`; 2513056 bytes.
- G-code MD5 `517ED99E53A2461F3F17DD90ACAABFE2`; C12/P1S, one ASA filament, five objects.
- 12517 s = 3 h 28 m 37 s; 63.96 g; 244 layers. Actual support/interface extrusion is approximately 1.389 g.
- P1S 0.4 / Textured PEI, calibrated PolyLite ASA yellow #FFF144, 260/100 °C, 0.2 mm layers, Arachne, two walls, 20% infill, by-layer sequence, 5 mm outer brim / 0.8 mm gap.
- This local process explicitly sets **45° support threshold, small-overhang removal off, organic supports allowed on the model (`support_on_build_plate_only=0`)**. The earlier bed-only trials omitted the guide interface. The original machine/process/filament profile files are unchanged.
- XY compensation 100/99.46 is baked exactly once about (128,128), Z unchanged; slicer filament shrink is 100%. Minimum object-box separation is 14.293955 mm, leaving 2.293955 mm beyond two conservative 6 mm brim envelopes.

[toolpaths.json](toolpaths.json) audits the exact archive, support zones, five objects, bed/exclusion bounds and MD5. [Guide support close-up](guide-toolpaths.png) shows actual extrusions at the top roof; support starts on the printed cheek. The reported interface paths are at print Z=3.4–3.6 mm; organic branches continue up to 6.2 mm under the roof. These are actual sliced paths, not a claim of a continuous conformal top-interface sheet. The purple overlay is the flagged nominal CAD overhang transformed into the exact compensated bed pose. The gray model paths and dashed print-Z=3 mm cheek surface show where the short support stack starts. Remove the branch/interface from the cheek and outer roof through the guide's open fore/aft ends; avoid gouging either printed surface. Actual release force and surface finish are unqualified. This support is accessible from the open guide mouth but needs physical release/finish inspection. Other support stays in the peg strips, and no fin support is generated. Actual extrusion-centre bounds, including brims/supports but excluding Custom startup/end, are [[44.435, 41.13049565829557, 0.2], [212.861, 222.634, 48.8]]. Arc plots use 5° subdivisions.

Orca retains `bed_temperature_too_high_than_filament` (level 3 / 1000C001) for the calibrated 100 °C bed. The local log also contains `Not precalculated Placeable areas requested` with exit 0; successful archive generation and actual extrusion checks are separate evidence. Time/mass come from archive metadata, not absent G-code summary comments. No printer command was sent.

**Reproduction and provenance.** Run from `/home/repro/code/peg-bt2` using fresh output directories; the generator refuses to overwrite evidence. Existing FreeCAD/physics/Orca runtimes are used; no package installation is needed.

```bash
V5_REVIEW=/home/repro/.local/state/peg-astra-3d/v5-rebuild
V5_SLICE=/home/repro/.local/state/peg-astra-3d/v5-slice-rebuild
timeout 240s flatpak run --env=PYTHONPATH=/app/freecad/lib --command=python3 org.freecad.FreeCAD -B bench/source/tweezers_v11/inward20_v5.py "$V5_REVIEW" --guide-count 4
timeout 900s /home/repro/venvs/physics/bin/python bench/source/tweezers_v11/inward20_v5_check.py "$V5_REVIEW"
timeout 240s /home/repro/venvs/physics/bin/python bench/source/tweezers_v11/inward20_v5_guide_check.py "$V5_REVIEW"
timeout 60s flatpak run --env=PYTHONPATH=/app/freecad/lib --command=python3 org.freecad.FreeCAD -B bench/source/tweezers_v11/inward20_v5_junction_check.py "$V5_REVIEW"
timeout 1800s flatpak run --env=PYTHONPATH=/app/freecad/lib --command=python3 org.freecad.FreeCAD -B bench/source/tweezers_v11/inward20_v5_fea.py "$V5_REVIEW"
timeout 360s env MPLCONFIGDIR=/tmp/peg-spool-mpl python3 bench/source/tweezers_v11/inward20_v5_render.py "$V5_REVIEW"
timeout 60s /home/repro/venvs/physics/bin/python bench/source/tweezers_v11/inward20_v5_plate.py "$V5_REVIEW" "$V5_SLICE"
timeout 720s python3 bench/source/tweezers_v11/inward20_v5_slice.py "$V5_SLICE"
timeout 120s env MPLCONFIGDIR=/tmp/peg-spool-mpl python3 bench/source/tweezers_v11/inward20_v5_toolpaths.py "$V5_SLICE" "$V5_REVIEW"
timeout 90s env MPLCONFIGDIR=/tmp/peg-spool-mpl python3 bench/source/tweezers_v11/inward20_v5_render.py "$V5_REVIEW" --slice "$V5_SLICE" --plate-only
```

[BUILD.json](BUILD.json) records the selected sources, CAD, exact numerical inputs, views, [OWNER-TEST.md](OWNER-TEST.md), frozen dependencies, existing profiles and local archive. The v3 renderer and its ordinary rasterizer dependency are included. Private failed drafts, unsupported trial slices, transient solver files, logs and slicer caches are not selected additions. All 320 preexisting staged baseline files are preserved; root owns index, README, manifest and integration. This session performed no index, commit, push, publication or printer action.

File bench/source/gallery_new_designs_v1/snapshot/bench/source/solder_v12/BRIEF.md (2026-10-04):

# Solder station v12: design brief

The owner's goal (2026-10-02): perfect the rest of the solder workstation. That covers print
orientation, attaching the refined pegs, checks for flex, tool holding, stiffness and
printability. No cantilevers and no unprintable overhangs. Use cheek printing or
bottom-side printing strategically. Check the massing, think through the prints and imagine
being the user.

The station is seven pegboard modules (B6 is published at
https://thereprocase.github.io/peg/gallery/solder-modules/). The tweezer rack is done
(v11.2, `bench/source/tweezers_v11/holder.py`; read it for style and stiffening). The
other six are rebuilt here as v12:

| id | B6 module | cells | B6 pose | B6 volume | station position (top-row centre, mm) |
|---|---|---|---|---|---|
| barrels | flux syringe, paste syringe, solder sucker, nozzles down | 5 | upright | 257 cm3 | x 38.1, z 0 |
| reel-thick | large solder reel | 3 | right cheek | 99 cm3 | x -114.3, z 0 |
| reel-thin | small solder reel | 3 | right cheek | 99 cm3 | x -114.3, z -101.6 |
| braid | desoldering braid roll | 2 | right cheek | 39 cm3 | x -50.8, z -101.6 |
| drip-tray | removable drip tray + vase-mode liner, below the barrel nozzles | 5 | upright | 89 cm3 | x 38.1, z -127 |
| snips-pliers | micro snips + needle-nose pliers, jaws down | 2 | right cheek | 79 cm3 | x -50.8, z 0 |
| tweezers (done) | v11.2 | 2 | right cheek | 94.5 cm3 | x 127, z 0 |

Positions are on the 1-inch grid. A module may change its cells or height when the reason is
good, but it must not collide with its neighbours' plates or tools. Report any change.

## Inputs

- **Tool stand-ins** in module-local holder coordinates (the B6 placement):
  `bench/reference/solder-tools/<id>__*.stl`. These are open meshes, the same planning
  proxies B6 used, not measured tools. Design for them with forgiving fits. Say which
  dimensions matter so the owner can measure the real tools.
- **The B6 holder** for each module: `docs/gallery/solder-modules/<id>/holder.stl`,
  `print-pose.stl` and `checks.json`, with renders at `docs/gallery/solder-modules/<id>.png`,
  `<id>-print.png` and `<id>-toolpaths.png`. These show what the old design did. B6 was never
  printed and was replaced as a design basis, so keep its intent, not its geometry.

## Coordinates and the shared library

All in `bench/source/solder_v12/`:

- **Coordinates:** X is lateral (+X is to your left when facing the board; the right cheek
  is at -X), Y is out of the
  board (pegs at Y < 0.15), Z is up. The top peg row's hole centre is at Z 0.12; row k is at
  0.12 - 25.4k. The plate's sharp lip is at Z 5.12; the plate wall runs from Y 0.15 to 5.55.
- **`common.py`:**
  - `receiver(cells, hoop_row, pose, ...)` builds the plate and pegs: hooks on row 0,
    bearing locators every other row between, and the PF07 #5 hoop on `hoop_row`. The hoop
    is turned into the cheek plane for `right-cheek` and left as is for `upright`. Pass
    `x0/x1/z0` to trim the plate.
  - Helpers:
    - `pointed_window(..., up='+X' | '+Z')` cuts plate windows with pointed roofs, so no
      bridges.
    - `peg_keepout()` keeps cuts away from the peg roots.
    - `band()`, `poly_prism()` and `box()` for strips and prisms.
    - `export()` writes the installed STEP/STL, the print-pose STEP/STL and the pose matrix.
    - `save_design()`.
- **`template_module.py`:** a runnable pipeline example, not a design. Copy its structure:
  1. receiver,
  2. body,
  3. `export`,
  4. tools placed and written as STLs in installed coordinates,
  5. `NAME__checks-spec.json` and `NAME__fea-spec.json`,
  6. `NAME__design.json`.
- **`checks.py`** (cadpy) checks:
  - one watertight body;
  - the pose matrix;
  - print-pose overhang features (pegs exempt);
  - tool fit (depth inside the holder);
  - seat (contacts, centre of mass over the contacts for gravity seats);
  - the removal path.
- **`fea.py`** (cadpy): a CalculiX linear-static solve under `face` and `pegs` support.
- **`render.py`** (cadpy): the loaded, empty, front, side and print views.
- **`slice_report.py`** (python3): time, grams, and support, bridge and overhang-wall grams.

Do not edit the shared files. If one needs a change, say so in your result.

## Commands

Run all of these from `/mnt/f/code/peg-fit-ladder-20260930`, with a timeout on every one:

```
timeout 900 "/mnt/c/Program Files/FreeCAD 1.1/bin/python.exe" 'F:\code\peg-fit-ladder-20260930\bench\source\solder_v12\<id>.py' 'F:\code\peg-fit-ladder-20260930\bench\reviews\v12-build\<id>'
cd bench && timeout 900 cadpy source/solder_v12/checks.py reviews/v12-build/<id> <NAME>
cd bench && timeout 900 cadpy source/solder_v12/render.py reviews/v12-build/<id> <NAME>
cd bench && timeout 3000 cadpy source/solder_v12/fea.py reviews/v12-build/<id> <NAME>
cd print && timeout 900 "/mnt/c/Program Files/FreeCAD 1.1/bin/python.exe" 'F:\code\peg-fit-ladder-20260930\print\slice_pf.py' 'v12:bench/reviews/v12-build/<id>/<print stl>:V12-<id>-ASA'
python3 bench/source/solder_v12/slice_report.py print/slice-v12/V12-<id>-ASA/V12-<id>-ASA.gcode.3mf bench/reviews/v12-build/<id>/<NAME>__slice.json
```

Naming: `NAME = 'part-solder-<id>__v12__<role>__fit-pf02c9-hoop5'`. Role is the pose, e.g.
`right-cheek` or `upright`. Never use `$(...)` in a shell command. Do not commit, push,
print or touch the printer.

## Owner rules (non-negotiable)

1. **Choose the bed face first.** Use the right cheek (-X) on the bed for narrow, deep
   modules, or the flat bottom for wide, shallow ones. Nothing prints in the air but the
   pegs, and Orca's organic supports go under the pegs only.
2. **Bridges or overhangs, never a cantilever.** In the print pose, every face steeper than
   45 degrees from vertical must be a peg. Openings get pointed roofs (at least 50 degrees),
   undersides get 45-degree chamfers or ramps, and anything horizontal sits on a wall. The
   v11 rack's through-slot ceilings printed as spaghetti. A bridge needs real walls at both
   ends, a span of at most 10 mm, and something behind it. Declare every bridge in
   `overhang_exceptions` with its reason; `checks.py` re-measures it.
3. **Flex in the print layers.** Clips, catches and spring arms must flex in the layer
   plane. `receiver()` already orients the hoop by pose. Any snap feature you add follows the
   same rule.
4. **Glue-in parts seat in blind pockets**, never through-holes: a vertical wall on the bed
   side and a chamfer on the other.
5. **Stiffness.** A thin cheek is flexy: v11 measured 45 mm at 5 N, and the owner rejected
   it. Use flanges (L or C sections), triangulated struts, plate-to-cheek gussets and webs
   (v11.2: 1.4 mm at 5 N, 114 mm out). Target: at most **1.0 mm** of sideways deflection at
   5 N at the farthest tool-bearing point under `pegs` support (5 N/mm or better). Also at
   most 0.5 mm at 5 N down. Report the numbers.
6. **Minimal plastic without sacrificing looks, strength or function.** Report the volume
   against B6. Do not save plastic at the cost of access or stiffness.
7. **BENCH_HOLDERS working rules:**
   - Width = 25.4 x cells - 2.
   - Two mounting columns.
   - Keep bearing, grasp and a one-motion return clear.
   - Prefer forgiving lead-ins.
   - Protect delicate tips and keep exposed points above a floor.
8. **Device data is a hint.** The tool proxies are guesses. Make fits forgiving (lead-ins,
   ramps, generous clearances where retention does not depend on them). List the real
   dimensions the owner should measure.

## Think as the user

The owner solders at this bench and wants:

- **Grab and return one-handed:**
  - one motion out;
  - one motion back;
  - no fiddling;
  - nothing to knock the neighbouring tools.
- **Tools stay put when the board is bumped.** Use gravity seats with a lip or cant, not
  friction alone.
- **Easy refills:**
  - reel and braid changes without tools;
  - liner out to empty it;
  - syringes in and out.
- **No hot iron here:** the iron lives elsewhere. Flux and paste drip, so nozzles point into
  the drip tray below the barrels.
- **Printing it:** one plate per module where it fits, with ASA's warp tendency respected
  (no huge thin flat sheets standing tall without ribs; a big first-layer footprint is good).
- **Shapes that look intentional.** Use consistent fillets and chamfers and the v11 visual
  language: flanges, triangulated windows, a tidy massing.

## Pass criteria for your module

1. `checks.py` passes:
   - one body;
   - non-peg overhang area 0, or declared bridges that pass;
   - every tool fits with no clash deeper than 0.15 mm;
   - every seat passes;
   - every removal path is at least -0.15 mm.
2. `fea.py`: the farthest tool-bearing point moves at most 1.0 mm sideways and at most
   0.5 mm down at 5 N under `pegs` support.
3. Sliced with the owner's ASA preset:
   - `slice_report`'s support grams are pegs only;
   - bridge and overhang-wall grams are near zero outside the pegs;
   - the print fits the 256 mm bed.
4. **Renders viewed and critiqued.** Open each PNG with the Read tool and look at it as the
   owner would.
5. A `NOTES.md` in your build dir with:
   - the design and why;
   - how the user loads and unloads each tool;
   - the print pose and settings;
   - the numbers (volume vs B6, FEA, slice time, grams, support);
   - open risks and the dimensions to measure.

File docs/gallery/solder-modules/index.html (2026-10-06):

October 4 current-mount update: Open the solder modules with PF02 #9 hooks and PF07 #5 hoops, print orientations and new CAD downloads. The earlier exports and test records below remain available as design history.

Solder station WIP: seven separate modules, with the v8 tips-down body cradles and unchanged 14-point tweezer mount. Use the individual v8 downloads; the collection ZIP and assembly views are historical. Physical fit and daily-use feedback remain part of development.

← Bench collection (https://thereprocase.github.io/peg/gallery/)

B6 · seven separate mounts · tighter peg fit throughout

# A solder station built around its print faces.

Tweezers updated to v8: long body support, closer side guides, open arms and tips down. View the new throat and print its test piece first. Loaded assembly views and the collection ZIP below retain earlier tweezers; the other six modules are unchanged.

The same tools and independent access, split into seven pieces on the one-inch grid. Overall mounting span: 302.8 mm. Barrel and tray modules stand on their bases; the narrower tool and reel modules print on their right cheeks.

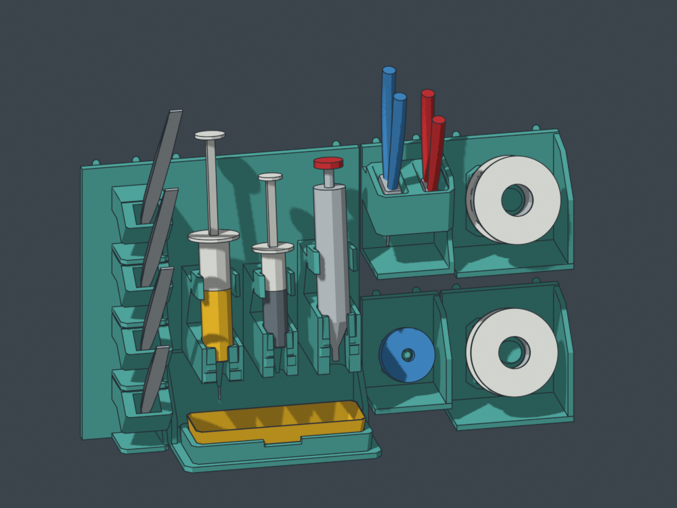
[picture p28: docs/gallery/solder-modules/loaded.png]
The seven solder modules with all twelve tools and removable liner


Download individual STEP/STL models (https://github.com/thereprocase/peg/releases/download/holders-2026-09-16/part-solder-station-collection__v7__7-modules-with-14-point-tweezer-mount.zip)Pick a moduleOpenSCAD generator with tighter pegs (https://github.com/thereprocase/peg/releases/download/holders-2026-09-16/part-collection__v-srcccbb104e00__pegstr-p01-p09-parametric-array-generator.zip)

All seven rear interfaces match rear-tongue-3p80-interference0p05: nominal 0.05 mm interference at 3.80 mm board thickness. This relies on plastic/board compliance. All mounted gallery downloads now use this shared fit.

Print review: all seven slice in Orca on the P1S 0.4 mm profile without mesh repairs. This is the historical v6 review. Current v8 tweezer slicing is reported on its individual page. Supports remain under pegs, short guide lips and some curved features; inspect the amber toolpaths below. The barrel rack has the most support, about 15.6 g. The inherited PETG profile raises a bed-temperature warning, so machine G-code is not included. Use your verified material settings. Physical surface finish and fit remain to be tried.

The barrel grips remain exposed between short bearings. Each tool has a checked lift-and-depart path with its neighbors present. Tweezers lift along their slope and leave through the open left side. The liner lifts 13 mm, then slides forward below the stored nozzles. These historical collection checks use the earlier planning tools. The v8 tweezer page has separate checks using the reconstructed measured tool.

Installed empty parts and print-face overview

Seven individual empty modules Separate chosen print poses, illustrative layout rather than a single build plate

## Individual modules

## Three barrels

5 grid cells · 125.0 mm wide · Upright, flat base

Three barrels

STEP (https://github.com/thereprocase/peg/releases/download/holders-2026-09-16/part-solder-modules-barrels__v6__solder-station-3-barrel-rack__installed__fit-9c7be3c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)Oriented STLFreeCAD (https://github.com/thereprocase/peg/releases/download/holders-2026-09-16/part-solder-modules-barrels__v6__solder-station-3-barrel-rack__installed__fit-9c7be3c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)

Print face and actual Orca supports

Chosen print face Actual Orca extrusion: teal part, amber support

15.6 g estimated support. All supports start on the build plate. No mesh repairs; within P1S build area. This is a review slice, not a physically qualified result.

Slice report

## Four tweezers · v8

2 cells · 48.8 mm mounting width · tips down

Four open bent tweezers with points down in long body cradles

58 mm of body support, low rails and 19 mm of closer side guidance. Lift 5 mm and move left; the points remain free. Original 2 hooks + 12 locators retained.

STEP, STL and editable sourceSingle-throat test STL

Designed around the measured 122.76 mm tweezer. Prototype fit; print the small test throat first. New Orca geometry review passes; earlier v6 slices remain historical.

3D preview, dimensions and checks

## Large solder reel

3 grid cells · 74.2 mm wide · Right cheek on bed

Large solder reel

STEP (https://github.com/thereprocase/peg/releases/download/holders-2026-09-16/part-solder-modules-reel-thick__v6__solder-station-large-solder-spool-seat__installed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)Oriented STLFreeCAD (https://github.com/thereprocase/peg/releases/download/holders-2026-09-16/part-solder-modules-reel-thick__v6__solder-station-large-solder-spool-seat__installed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)

Print face and actual Orca supports

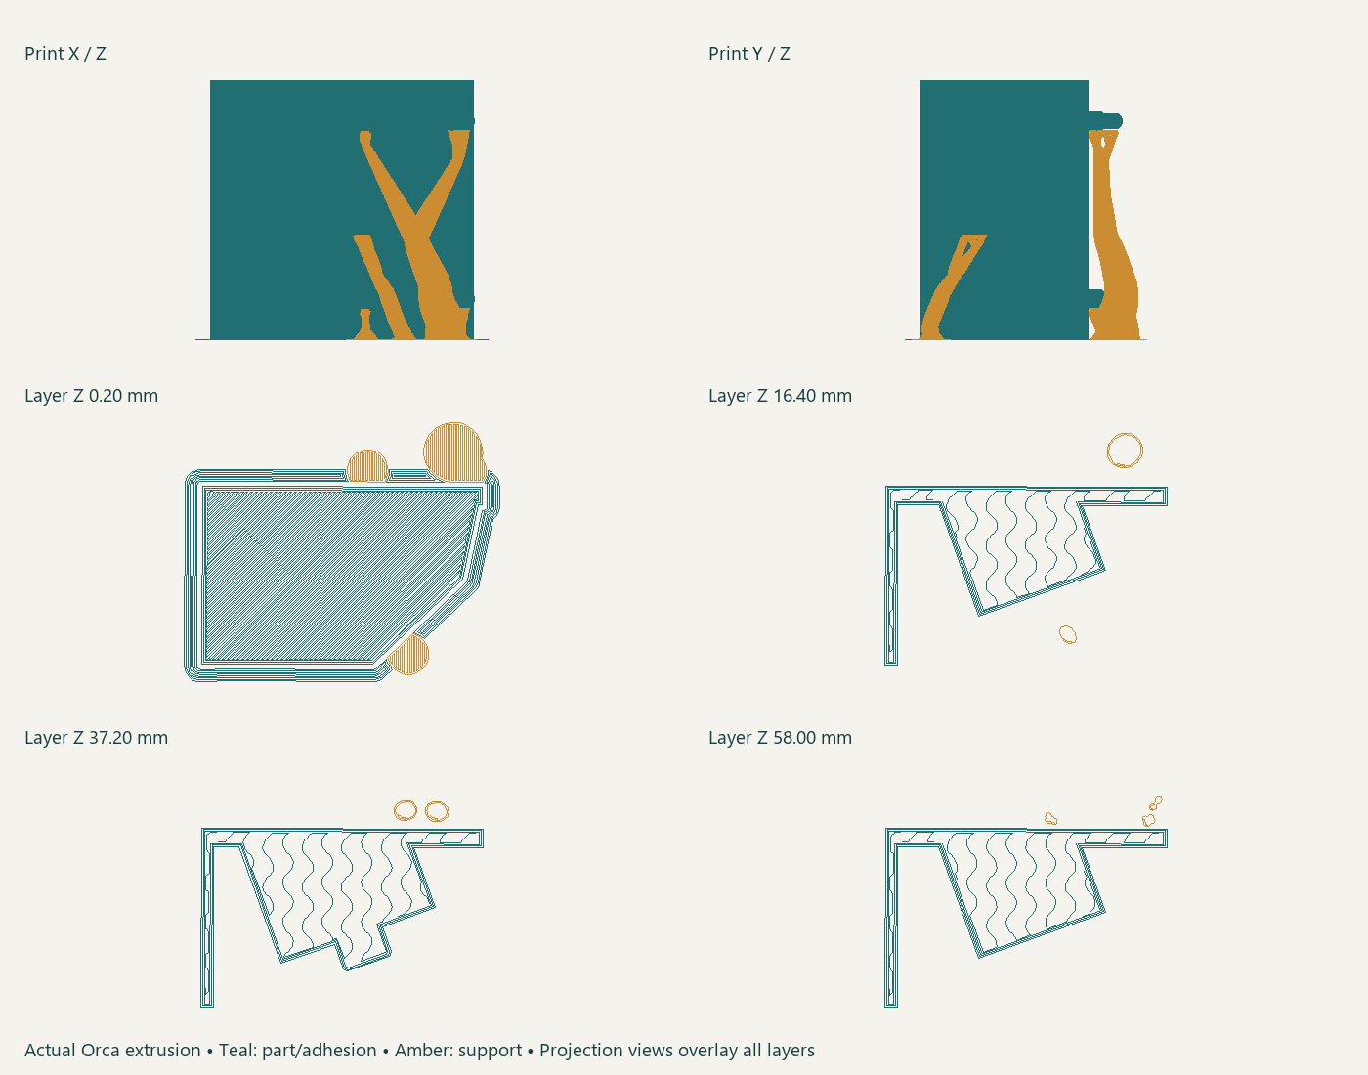
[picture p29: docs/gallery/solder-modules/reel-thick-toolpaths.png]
Chosen print face 

1.9 g estimated support. All supports start on the build plate. No mesh repairs; within P1S build area. This is a review slice, not a physically qualified result.

Slice report

## Small solder reel

3 grid cells · 74.2 mm wide · Right cheek on bed

Small solder reel

STEP (https://github.com/thereprocase/peg/releases/download/holders-2026-09-16/part-solder-modules-reel-thin__v6__solder-station-small-solder-spool-seat__installed_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)Oriented STLFreeCAD (https://github.com/thereprocase/peg/releases/download/holders-2026-09-16/part-solder-modules-reel-thin__v6__solder-station-small-solder-spool-seat__installed_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)

Print face and actual Orca supports

Chosen print face Actual Orca extrusion: teal part, amber support

1.9 g estimated support. All supports start on the build plate. No mesh repairs; within P1S build area. This is a review slice, not a physically qualified result.

Slice report

## Braid roll

2 grid cells · 48.8 mm wide · Right cheek on bed

Braid roll

STEP (https://github.com/thereprocase/peg/releases/download/holders-2026-09-16/part-solder-modules-braid__v6__solder-station-braid-roll-seat__installed__fit-9c7be3c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)Oriented STLFreeCAD (https://github.com/thereprocase/peg/releases/download/holders-2026-09-16/part-solder-modules-braid__v6__solder-station-braid-roll-seat__installed__fit-9c7be3c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)

Print face and actual Orca supports

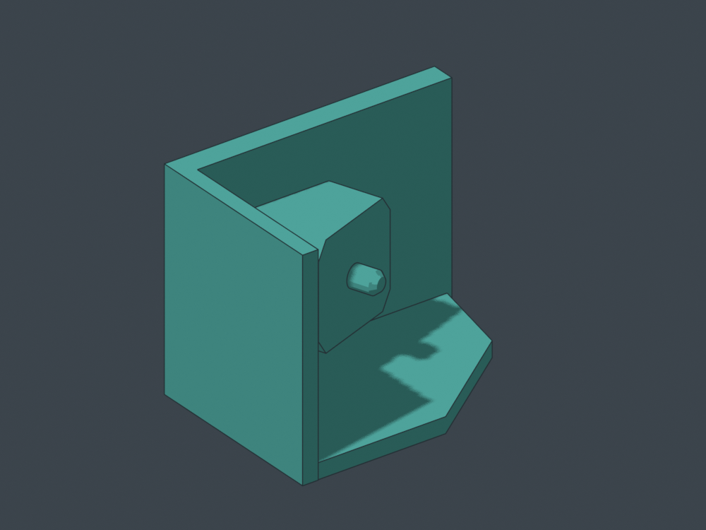
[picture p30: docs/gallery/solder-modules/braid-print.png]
Chosen print face
 Actual Orca extrusion: teal part, amber support

0.9 g estimated support. All supports start on the build plate. No mesh repairs; within P1S build area. This is a review slice, not a physically qualified result.

Slice report

## Removable drip tray

5 grid cells · 125.0 mm wide · Upright, flat base

Removable drip tray

STEP (https://github.com/thereprocase/peg/releases/download/holders-2026-09-16/part-solder-modules-drip-tray__v6__solder-station-drip-tray-with-vase-liner__installe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)Oriented STLFreeCAD (https://github.com/thereprocase/peg/releases/download/holders-2026-09-16/part-solder-modules-drip-tray__v6__solder-station-drip-tray-with-vase-liner__installe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)

Print face and actual Orca supports

Chosen print face Actual Orca extrusion: teal part, amber support

1.3 g estimated support. All supports start on the build plate. No mesh repairs; within P1S build area. This is a review slice, not a physically qualified result.

Slice report

## Snips + small pliers

2 grid cells · 48.8 mm wide · Right cheek on bed

Snips + small pliers

STEP (https://github.com/thereprocase/peg/releases/download/holders-2026-09-16/part-solder-modules-snips-pliers__v6__solder-station-2-tool-snips-and-pliers-seat__in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)Oriented STLFreeCAD (https://github.com/thereprocase/peg/releases/download/holders-2026-09-16/part-solder-modules-snips-pliers__v6__solder-station-2-tool-snips-and-pliers-seat__in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)

Print face and actual Orca supports

Chosen print face Actual Orca extrusion: teal part, amber support

2.6 g estimated support. All supports start on the build plate. No mesh repairs; within P1S build area. This is a review slice, not a physically qualified result.

Slice report

## Drip liner

The insert is the original 108 × 34 × 20 mm tapered vase-mode form, with a 102 × 28 mm base. The shorter receiving rim exposes the liner for grasping and clears the nozzle during removal. The filled vase source is intentionally different from the hollow visualization.

Filled vase-mode source STLVase-source STEP (https://github.com/thereprocase/peg/releases/download/holders-2026-09-16/part-solder-modules-drip-tray__v6__solder-station-drip-tray-with-vase-liner__referenc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)Hollow preview STEP (https://github.com/thereprocase/peg/releases/download/holders-2026-09-16/part-solder-modules-drip-tray__v6__solder-station-drip-tray-with-vase-liner__referenc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)

## Rotate the installed arrangement

Access and peg checks · Dimensions and placement

To browse the extracted files locally, open index.html. For local 3D, run python3 serve-gallery.py. Assembly STEP is a positioning reference: print the individual modules. No current model was selected by reducing material at the expense of access.

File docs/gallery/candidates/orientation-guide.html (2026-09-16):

Retired · September 16, 2026

# This collection is retired.

The speculative catalogs and standalone experiments have been taken out of the active lineup. Their model downloads are no longer offered here.

The collection now consists of Pegstr custom-peg remixes, the Pegstr array expansion pack, and the solder and screwdriver WIP sets.

Retirement does not erase private votes, reference research or design lessons.

Go to the trophy lineup →

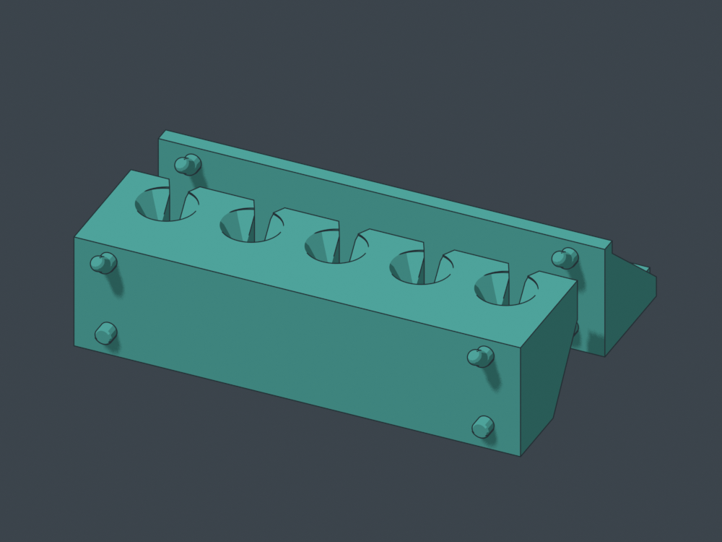
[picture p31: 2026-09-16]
docs/gallery/screwdrivers/SD02/part-sd02__v2__upright-print-faces.png

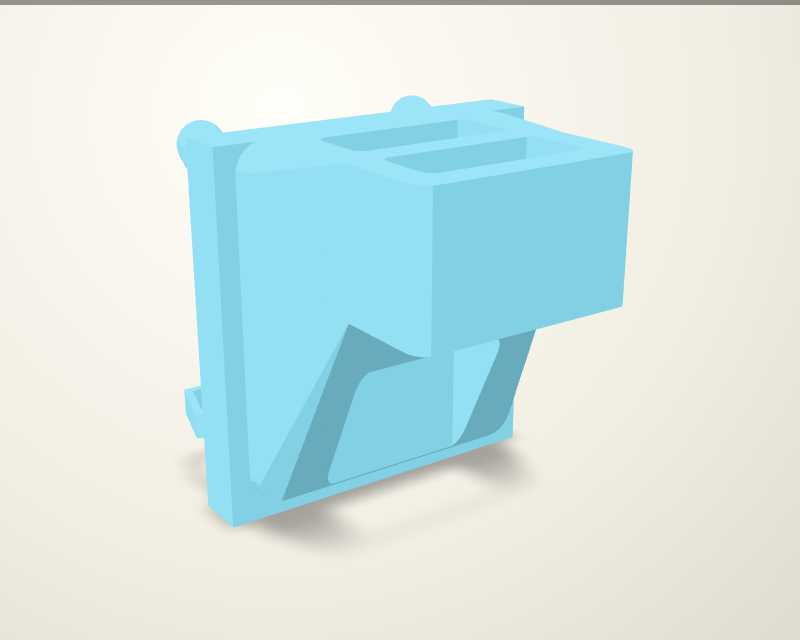
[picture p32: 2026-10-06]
docs/gallery/current-pegs/part-p11__current-mounts-flat-top-v2__fit-pf02c9-hoop5__installed.png

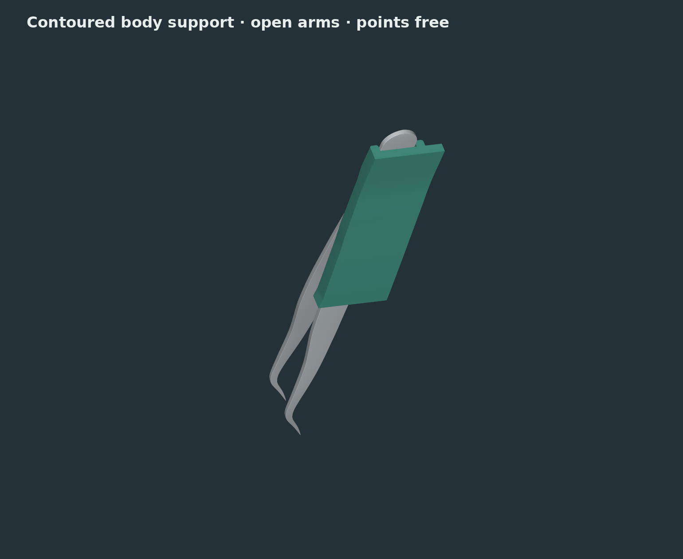
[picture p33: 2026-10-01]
docs/gallery/tweezers/part-solder-modules-tweezers__v10__compact-right-cheek__fit-9328ccc5d4__detail.png

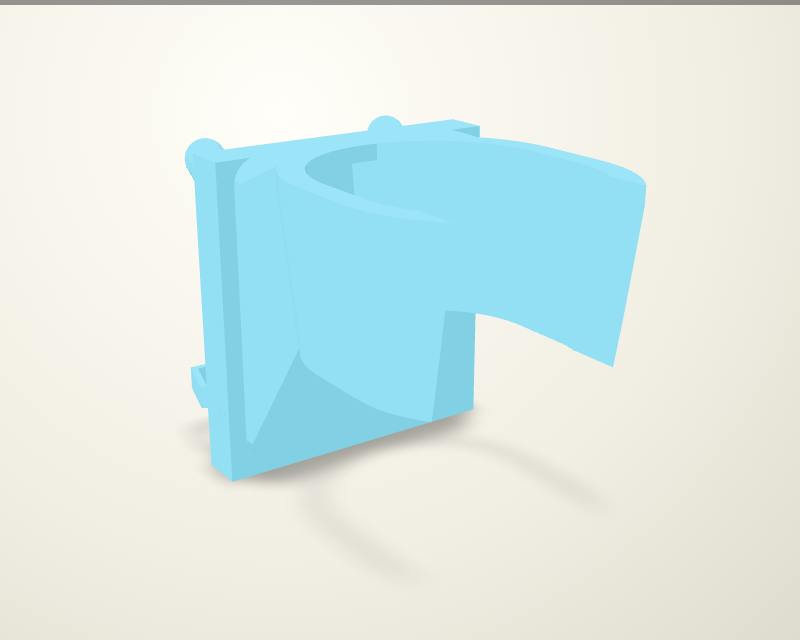
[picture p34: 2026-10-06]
docs/gallery/current-pegs/part-p04__current-mounts-flat-top-v2__fit-pf02c9-hoop5__installed.png

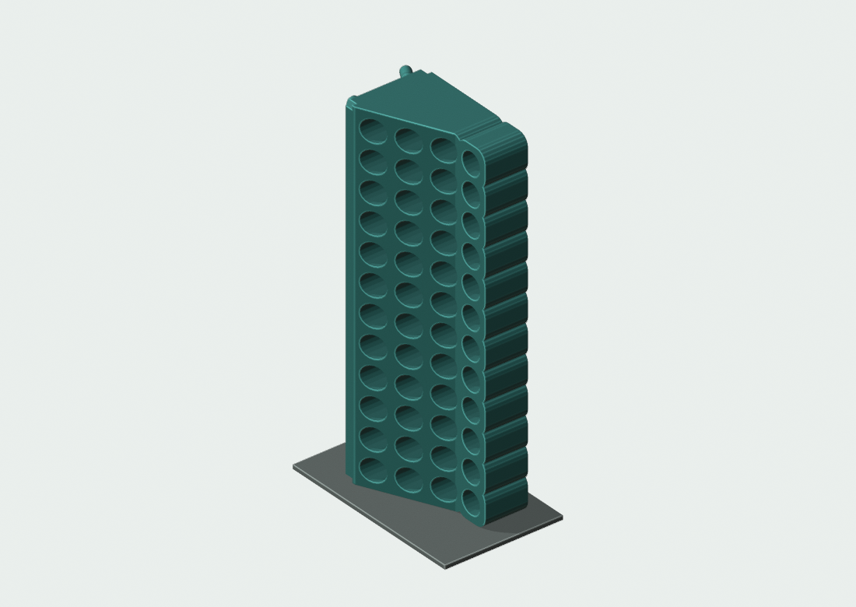
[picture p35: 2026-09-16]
docs/gallery/downloads/named/part-arrays-p09-48__v-src0e00429f35__pegstr-array-p09-48-round-seats__reference-print.png

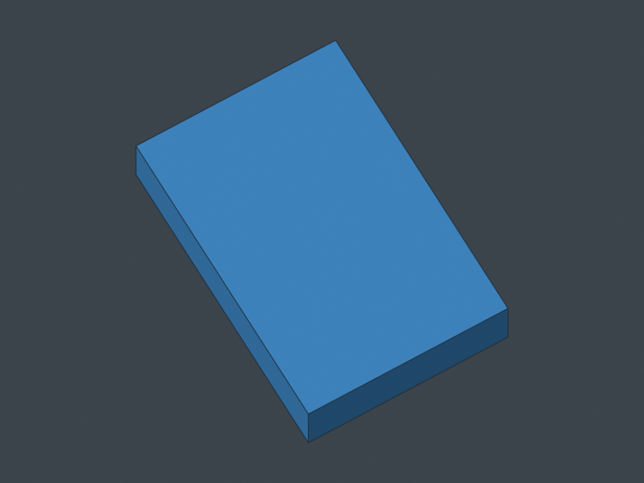
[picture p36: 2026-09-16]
docs/gallery/magnetic-bar/part-mb01-magnetic-shaft-bar-f__v1__plug-print-face.png

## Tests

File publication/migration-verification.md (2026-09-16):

# GitHub Pages cutover — September 16, 2026

- 1,398 previous public allowlist entries migrated; all unchanged CAD/media verified against the source manifest.
- 237 large-download routes consolidated into 171 byte-identical GitHub Release assets; GitHub SHA256 digests and sizes checked for every asset.
- 589 static local HTML links checked, no missing targets. GitHub Pages site is about 440 MB.
- 18 live browser viewport checks: nine pages at 390 and 1440 px; no visible image failures or horizontal overflow. Pegstr interaction and 3D loading checked; sampler 3D loaded after opening its details and scrolling into view.
- Actual public MS01 v2 print-kit ZIP downloaded and SHA256 matched the original 15,851,616-byte file.
- 242 legacy redirect cases checked locally, including every migrated binary route. Query strings preserved. Private reviews/API remain blocked.
- Public Warpbus root, Domhammer page and health remain HTTP 200. Legacy gallery links now return HTTP 308 to Pages or Release assets.
- New Warpbus releases omit the gallery asset tree. Previous immutable snapshots remain available for rollback.

No CAD geometry, slicer settings, qualification claims or print-job bytes changed in this migration. Pegstr credits and licenses remain visible. Public/private boundaries match the previous public allowlist.

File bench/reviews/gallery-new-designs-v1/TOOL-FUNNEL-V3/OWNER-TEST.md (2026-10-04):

# First physical check — not yet performed

Use a reviewed machine/material-specific upright slice. Inspect rear-peg supports and the short 45° internal transition. Remove supports without rounding the peg seams, and make sure the bottom hole stays open.

Check the new rim break and rounded corners by touch; support cleanup must not damage the peg seams.

1. Mount the empty prototype and check engagement/release of the shared upright hoops; this matches v2's upright hoops.
2. Lower each actual tool edge-on, jaws down. It must settle on robust grips, with the latch, spring, rivet and cutting end free of the longer sleeve.
3. Check natural settling angle, rattle and modest bump retention. Do not force the tool or use its latch as a bearing.
4. Lift straight up and return with one hand. Nominal reference lifts are 63 mm Knipex / 107 mm Klein; allow 110 mm plus hand space and verify the real tools.
5. At 50.8 mm holder centres, test independent grasp and the actual normal handle openings. Stop if a jaw, rivet or spring catches or if support residue makes the passage tight.

No physical seating, rattle, support-release or strength result is claimed yet.

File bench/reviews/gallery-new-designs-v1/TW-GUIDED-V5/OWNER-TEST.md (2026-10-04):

# Curved-guide physical check

Test the curved-roof prototype with the taller fins. See [NOTES.md](NOTES.md)
for the complete return and pickup motions. The CAD and stiffness checks describe
the reference geometry; natural handling and printed behavior need observation.

- Fit the printed holder to the actual board and check the hooks, hoops and
  frame for movement before loading it. Record board movement separately from
  frame flex. Dry-fit the four taller fins, keep adhesive off their catching
  faces and let the foot bonds cure before testing.
- Try each actual tweezer in every station, then load all four. Confirm the
  retained seated angles and tip clearance, including the longest pair.
  Check the lower stations at their new 28 mm spacing.
- From the normal bench position, present a tool above and to your left, then
  sweep it right. Observe where the curved roof first meets the stronger arm
  section and whether it guides the tool down around the fin. Align above
  the taller fin, then allow the final free downward settle as described in
  NOTES. The fragile tips should stay clear.
- Repeat ordinary returns by feel, including slightly high and lateral starts.
  Record misses, a tool perched on a fin or guide, and returns that need an
  extra grip or a precision correction. Compare against the frozen taller-fin
  holder without the guide when practical.
- Pick up each tool independently with the three neighbors stored. Lift
  initially, then sweep continuously up-left and outward along the selected
  complete escape route, then try the usual natural pickup. Check for
  roof hooking, contact with a neighboring tool, and adequate finger access.
- Check that every guide has a smooth reachable surface after support removal.
  Record any rough contact, thin join damage, tool scratching or glue movement.
  Apply the same ordinary bench bump used for the earlier holder and note
  whether a fully seated tool lifts or perches on the taller fin.

Keep observations attached to the tested body, fin and tool versions. A clear
sampled path is not a measured capture rate, and the solid fixed-peg calculation
does not measure a printed guide, adhesive bond or pegboard retention.

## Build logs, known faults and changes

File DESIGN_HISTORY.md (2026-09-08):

# Design history

This record preserves the requirements, engineering decisions, alternatives, and remaining work from the September 2026 design session. It describes the visible project work and evidence; it is not a transcript of hidden reasoning. The current geometry and verification results take precedence over early candidate dimensions.

## Current checkpoint: conformal bearings and attached-part envelope

The current release is the conformal design described in [README.md](README.md), [CONFORMAL_STUDY.md](CONFORMAL_STUDY.md) and [HOST_INTERFACE.md](HOST_INTERFACE.md). The user asked whether the bottom of each peg could match the bore for at least 120 degrees, why the lower peg did not span the entire board, and how much of a real attached part could remain flush above the peg.

The resulting geometry uses true **3.175 mm-radius, 120-degree lower cylindrical arcs**. The upper arc has **3.158095 mm bearing length**; an attempted full-thickness upper land obstructed the tested insertion. The lower arc bears through the entire **3.94 mm board**, followed by an ordinary **0.50 mm nose chamfer**. It therefore projects **4.44 mm from the installed board front** without sacrificing the requested lower bearing length.

The agreed interface has a **sharp 5 mm nominal lip above the upper hole center**. This is not a limit on a holder's total height. An exported allowed host volume captures the clearance boundary through the complete motion, so downstream CAD can use any contained shape. The sharp board-facing seam has no modeled radius or recess.

A tiny gravity-seating heel was explored, targeting 0.10 mm inward draw over 0.15 mm settlement. The user rejected it as too small to be meaningful in the real part. It was removed from the current geometry, motion and visuals before the publication update.

The current shape has its own continuous motion and host-envelope certificates, independent actual-STEP intersections, bearing-face measurements and valid solid/mesh exports. Physical fit, current-shape printing supports, slicing and loads still need qualification. The previous round release retains its own supported 3MF, scaffolds and evidence in [ROUND_README.md](ROUND_README.md); those print aids are not for the conformal shape.

## Earlier design chronology

The sections below preserve earlier decisions. Dimensions described as "final" or "current" within those historical sections belong to the corresponding rectangular or round checkpoint, not the current conformal release.

## What the user wanted

The opening request was:

> Create the perfect modular parametric standard 1/4" pegboard hook model I can drop onto all sorts of pegboard mounts.

The task developed into a reusable rear attachment interface: an upper retaining tongue, a lower locator one hole row below, and a front spine that can merge into an arbitrary holder. The user emphasized FDM strength, easy insertion and removal, firm seated holding, and a full motion study. They then directed the default toward common Home Depot/Lowe's hardboard rather than assuming every board is 1/4 inch thick.

Two later questions sharpened the evaluation:

> this is strong and smart and nice?

> what would make this the most FDM friendly possible?

The later work added a second print orientation with sacrificial supports for integration into upright holders. The final request directed publication of all project knowledge, sources, CAD, animations, motion study, and detailed documentation to [thereprocase/peg](https://github.com/thereprocase/peg), with immediate preservation of the design history and a next-agent handoff.

Only the three quoted prompts above were available verbatim to the original author of this historical section. The intervening requirements and final publication request are summarized from the project coordination record; they are not reconstructed quotations.

## Requirements that should persist

- Provide a reusable parametric interface, not just one finished tool hook.
- Target the common US 1/4-inch hook/hole family on a 1-inch grid.
- Treat board thickness and actual hole diameter as separate dimensions.
- Prioritize a strong printable load path, smooth installation, and limited seated movement.
- Check the complete anchor through the whole insertion and removal motion, including its lower locator and front spine.
- Supply editable procedural sources and solid/mesh exports that ordinary CAD and slicers can use.
- Make the most immediately usable print and CAD choices obvious.
- Preserve the engineering evidence and design evolution in the repository.
- Describe what tests establish precisely; do not turn a geometric check into a load rating or a claim of universal fit.

## Board research changed the default

The first conceptual discussion used 6.35 mm board thickness because the request named 1/4-inch pegboard. Product research showed why that was too coarse. Multiple current Home Depot and Lowe's sheet-stock listings describe nominal 3/16-inch hardboard with **0.155-inch actual thickness, or 3.937 mm**. A smaller Home Depot panel lists 0.165 inch, or 4.191 mm. Lowe's also lists true 0.25-inch hardboard products.

The default therefore became **3.94 mm thickness, 6.35 mm minimum hole diameter, and 25.4 mm pitch**. Lowe's common DPI products can have **9/32-inch holes, or 7.14375 mm**; that became a separate hole-specific variant. The source assortment supports the practical default, but it does not establish a national sales majority or a universal board size. A Canada-only 5.5 mm/0.22-inch example was not used to establish a US default. A Lowe's listing with transposed panel/thickness fields was treated cautiously.

See [research.md](research.md) for the product evidence and direct links.

## The attachment concept

The anchor uses an upper neck that passes through the board and a shallow rising tongue that captures the board's rear face. The lower locator enters the hole one row below and limits rotation. A long front spine bears on the board face and provides a convenient fusion surface for the user's holder.

The core profile has constant 4 mm width across the board. Printing it on its broad side puts the complete bent hook and root inside each layer. The profile needs no automatic support in that orientation. A short chamfered locator helps it enter during the final rotation.

A tight, short 90-degree elbow was an unattractive starting point because its intermediate insertion orientations can need substantially more aperture than its final seated pose. The adopted shallow tongue trades a little rear projection for a feasible gentle threading motion and a thicker neck.

The anchor is removable by a combined rotation and translation. It has no spring preload or positive snap lock. The words “retaining” and “holding” describe the geometry and bearing arrangement, not a certified working load.

## Geometry development and the snug-fit revision

The early motion work found a path for a steeper, shorter tongue with a 3.1 mm neck. Increasing that neck to 3.6 mm invalidated the original path. Increasing the tongue's rearward run to **5 mm** with **3 mm rise** allowed the thicker neck across the tested thickness presets.

The first broadly compatible profile still allowed approximately **2.12 mm straight outward movement and 3.02 degrees of outward rocking**. That did not meet the user's request for firm seated holding. Moving the elbow forward and searching a combined lift, tip, and translation reduced those quantities to approximately **0.47 mm and 0.69 degrees**.

The final design calculates the elbow position from a target pull clearance rather than treating a fixed elbow coordinate as an unexplained fit setting. `elbow_offset=None` requests the derived value. `pull_clearance=0.47` sets the target straight outward movement before the retaining shoulder contacts the rear board surface.

The final design distinguishes the geometry's convenient coordinate origin from its physical seated pose. It seats at **Y=-0.15 mm, Z=-0.12 mm, rotation=0 degrees**, closing the front bearing and upper bore contacts. A centered part in a clearance hole would otherwise appear supported without establishing gravity bearing.

## Final functional dimensions

| Parameter | Value |
|---|---:|
| Default board thickness | 3.94 mm |
| Default hole diameter | 6.35 mm |
| Hole pitch | 25.4 mm |
| Constant profile width | 4.0 mm |
| Neck height | 3.6 mm |
| Spine depth | 4.5 mm |
| Spine height | 34.6 mm |
| Tongue run / rise | 5.0 / 3.0 mm |
| Lower locator projection / height | 2.3 / 3.0 mm |
| Target straight pull movement | 0.47 mm |
| Reserved free-threading bore half-height allowance | 0.10 mm |

The neck area is **14.4 mm²**, and its elastic section modulus for bending in the side-profile plane is **8.64 mm³**. These are geometric properties, not material allowables.

## What the full motion study establishes

For a constant-width part centered in a circular bore, the restrictive vertical opening is `sqrt(hole_diameter² - width²)`. For the default anchor, this is **4.932 mm**, rather than the full 6.35 mm hole diameter. The solver therefore accounts for the entire 4 mm width instead of checking an infinitesimally thin center section.

An A* search finds coupled translations and rotations. The retained path receives a continuous separation check that bounds every intermediate rigid-body position, recursively subdividing intervals where needed. The final translation into intended bearing contact uses an exact polygonal sweep. Reversing the verified path gives the same swept volume for removal. Dense samples provide additional evidence and the animation; they are not the sole basis of the continuous claim.

| Board / hole | Maximum tilt | Maximum lift | Result |
|---|---:|---:|---|
| 3.94 / 6.35 mm | 19.25 degrees | 0.82 mm | Pass |
| 4.19 / 6.35 mm | 19.25 degrees | 0.92 mm | Pass |
| 4.7625 / 6.35 mm | 19.75 degrees | 1.17 mm | Pass |
| 6.35 / 6.35 mm | 20.00 degrees | 1.77 mm | Pass |
| 3.94 / 7.14375 mm | 9.75 degrees | 0.22 mm | Pass |

The default needs approximately **5.55 mm clear projection behind the board** along its modeled path. An independent sampled OpenCascade check examines the default and two-column geometry in true 3D circular bores. The study proves a feasible path under its stated assumptions, not the minimum possible tilt or one exact human hand trajectory.

See [MOTION_STUDY.md](MOTION_STUDY.md), `motion_results.json`, and `occ_motion_check.json` for the complete methodology and results.

## The “strong, smart, nice” assessment

The design is coherent: it uses a shallow rounded tongue, short lead-in locator, measurable fit settings, real seated contacts, and a favorable flat print orientation. Its shape is compact and functional. Those are supportable design judgments.

The strength assessment remains conditional. The 4 × 3.6 mm neck is small, and a long host lever arm can amplify its load. The rectangular section initially contacts the round bore near its two outer lower edges, which can concentrate pressure in hardboard. The profile union leaves abrupt neck-to-spine shoulders; the widthwise edges remain sharp. The controlled pull movement and rocking are not equivalent to zero rattle or preload.

The accurate characterization at this stage is **a thoughtful, strength-oriented prototype with verified geometric motion**. No physical fit, pull, fatigue, creep, or comparative-orientation strength test has occurred. FEA has not occurred either.

## FDM improvements considered

The highest-value improvement identified was preserving the side-print orientation after integration into a real holder. A separate mechanically captured cartridge would achieve that when the holder needs another build orientation. Broad keyed shoulders should transfer load; a keeper should retain the cartridge. That cartridge interface remains a future concept, not a delivered feature.

Other proposed improvements remain unimplemented unless a later source revision explicitly adds them:

1. Add calibrated relief around the bed-facing perimeter to keep elephant foot outside the insertion envelope. A preliminary discussion suggested roughly 0.15–0.25 mm relief over 0.2–0.3 mm height; these are tuning ranges, not established production tolerances.
2. Improve abrupt root transitions using available front-side space. The lower neck already reaches its bore-bearing limit, so simply adding a large fillet there can collide with the board and requires renewed motion checks.
3. Provide physically calibrated easy-fit and snug-fit presets. The 0.10 mm free-threading allowance is demanding enough that actual printer and board variation matters.
4. Consider curved bore-bearing surfaces if tests show local wear or crushing. That would complicate the geometry and require replacing or extending the constant-width verification method.
5. Inspect actual continuous perimeter paths and seam placement. Convenient multiples of a nominal line width do not guarantee good toolpaths.

## Upright printing: supports solve a different problem

The second delivered print option keeps the installed Z direction upright for holders that must stand on the bed. It adds **four sacrificial membranes**, two below each projection. Each membrane is **0.50 mm thick**, sits **0.15 mm inside** an outer width face, and grows rearward on a **45-degree ramp**. The paired membranes leave a **2.70 mm bridge span** across X. They add approximately **22.6 mm³** of plastic to the default anchor.

These webs are cutting targets, not permanent reinforcing gussets. Cut every root and roof attachment, remove all four webs, and trim the original interface flush before installation. The inset protects the outer bearing corners during trimming. Do not twist the tongue to fracture supports away.

The supported CAD is a valid single solid with a watertight STL. Geometric web-growth checks cover all five presets at four layer phases. After complete flush removal, the functional interface returns to the existing motion-checked geometry. Residual support material can defeat that assumption.

## Actual slicing changed the recommendation

A generic **CuraEngine 5.0.0** toolpath review sliced both orientations with automatic supports off. The side orientation used **five walls**. Initially applying five walls to the upright version filled its narrow roofs with nested perimeter loops, leaving no clean transverse roof skin across the supporting webs.

The successful upright review used **two walls and 100% line infill**, with bridge controls described in [SLICER_CHECK.md](SLICER_CHECK.md). Cura retained all four 0.50 mm webs and produced X-directed roof skin. The inspected lower roof had approximately 2.241 mm centerline spans; the upper roof had approximately 2.650 mm spans. Those path lengths differ from the 2.70 mm geometric gap because the slicer also places perimeters and overlap.

The review found one connected first-layer model footprint and no wholly detached deposition components under its defined component check. The isolated upright coupon used a 6 mm brim. A larger holder may provide sufficient footprint without that brim.

This is actual generic toolpath evidence, not a physical print or a Bambu P1S/OrcaSlicer certification. The upright layers still carry the hook differently from the flat layers. The supports make deposition feasible; they do not recreate the flat orientation's continuous in-layer load path.

`Pegboard_Print_Options.3mf` contains both geometries as a standard geometry-only 3MF. It has no machine-specific profile or G-code. The generic review G-code is deliberately outside the deliverable package.

## Current boundary and next decisions

The sources, exports, figures, motion evidence, and generic slicing evidence are ready for a physical prototype. The next useful decision should follow a real board-and-printer trial: install/remove feel, snugness, support trimming quality, and a representative loaded holder. Increase engineering complexity only where those tests identify a concrete problem.

Preserve the functional interface and verification contract when changing support geometry. Preserve the provenance of tested versus proposed improvements. Keep the current usable exports prominent, with older alternatives retained in version history rather than mixed into the primary print choices.

## Round-bearing revision after the publication checkpoint

The user identified the rectangular lower corners as poor bearing in round holes and explicitly requested round pegs. The replacement uses actual circular capsules and a circular locator, with independent bearing and tongue diameters. A cosmetic corner fillet was rejected as insufficient.

Uniform 5.0, 5.2, and 5.4 mm round hooks found threading paths. Larger uniform hooks became difficult to install with the compact 5 mm run / 3 mm rise tongue and the 0.47 mm pull target. A 5.8 mm bearing neck with a 4.0 mm tongue found a path but reduced the tongue's geometric section modulus below the original rectangular neck. The selected 5.6 mm neck / 4.8 mm tongue improves both circular section properties while preserving a continuously certified path. Some bounded searches failed; those failures are not proofs of global geometric impossibility.

The round default reaches 20.875 degrees, lifts 1.07 mm, and sweeps 6.62 mm behind the board. All five round thickness/hole presets pass continuous checks, with smaller 5.4 and 5.2 mm bearing pegs for the two thicker board cases. The exact round proof uses center-plane capsule distance, conservative lower-locator X slabs, and a separate exact seating certificate. It caught a sampled-clear shortcut that needed refinement. Actual STEP single and paired examples each pass 80 independent poses, and the modeled rocking stop was checked on either side of contact.

Round surfaces changed printing. A cradle with only the original 0.20 mm neck-to-bed clearance could not fit a 0.20 mm removable interface at the reviewed layer height. The final side model therefore adds a 0.40 mm lift and a thin sacrificial spine pad. Upright needs conformal saddles beneath the earliest central underside, carried on removable ramp webs. The final supported side paths have no flagged functional perimeter portions; upright has only a 0.051 mm early spine-edge fringe. Neither path screening nor the larger section properties constitutes a physical print or load test.

Details of the round checkpoint, rejected alternatives, exact settings and reproduction are preserved in ROUND_README.md, ROUND_MOTION_STUDY.md, ROUND_SLICER_CHECK.md and tools/ROUND_REVIEW.md. The original rectangular files remain available as a labeled baseline. Current conformal downloads and visuals lead the root README; HANDOFF.md follows that current design.

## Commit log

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2026-09-08 Preserve complete source, motion analysis, animation, and design handoff
    [pegboard_anchor.scad]
2026-09-08 Publish all STEP and print files, slicing replay tools, and engineering documentation
    [Pegboard_Print_Options.3mf, anchor_3p94mm_9over32_holes.step, anchor_3p94mm_9over32_holes.stl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]
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2026-09-08 Complete six-image gallery and preserve the round-bearing revision requirement
2026-09-08 Checkpoint true round-bearing CAD and three-dimensional motion analysis sources
2026-09-08 Promote round bearing pegs with certified motion, printable cradles, and illustrated documentation
    [Round_Print_Options.3mf, round.step, round_9_32_holes.step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]
2026-09-08 Complete all round preset exports and verify the 142-file release manifest
    [round_9_32_holes_design_reference.stl, round_9_32_holes_side_unsupported.stl, round_9_32_holes_upright_unsupported.stl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]
2026-09-08 Publish conformal bearings and custom-part integration envelope
    [allowed_host_volume.step, conformal_120.step, conformal_120_design_unsupported.stl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]
2026-09-16 Publish curated holder gallery and current bench fit documentation
    [PegBoard-library.scad, conformal_120.step, functional-peg.stl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]
2026-09-16 Add recoverable-magnet MS01 v3 test sampler and checked print kit
    [part-ms01-shaft-fit-sampler-20x10x3-recoverable__v3__A-H__installed__fit-e586ab4ff6.stl, part-ms01-shaft-fit-sampler-20x10x3-recoverable__v3__A-H__print-flat-t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]
2026-09-16 Verify recoverable sampler asset hashes and live browser views
2026-09-16 Add matching flat-print magnet retaining combs for MS01 v3
    [part-ms01-retaining-comb__v1__A-H__installed.stl, part-ms01-retaining-comb__v1__A-H__print-flat.stl, part-ms01-retaining-comb__v1__I-P__installed.stl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]
2026-09-17 Publish Pegstr workshop and SWD01 screw-dish review candidate
2026-09-17 Publish MH01-MH04 magnetic shaft holders from the MS01 letters for form review
    Letters E, I, M and O from the physical sampler trial become four sealed-magnet bars with grid-continuous seat pitch and the canonical tight pegs. CAD checks pass; not sliced or printed.
    Claude-Session: https://claude.ai/code/session_01SNioBzPSjz1qcuaJbtCjs4
    [part-mh01-magnetic-shaft-holder-jeweler-4mm-round__v1__6-seats-4-cells__installed__fit-e586ab4ff6.stl, part-mh01-magnetic-shaft-holder-jeweler-4mm-round__v1__6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]
2026-09-17 Add the checked MH01-MH04 print kit with native pause-and-cap job
    Five-plate P1S PLA job: plugs first, one verified pause per holder before layer 38.2, no extrusion in any magnet chimney below 38.0. Not yet printed.
    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
2026-10-01 Add v8 tips-down tweezer body cradles and fit coupon
    [part-solder-modules-tweezers__v8__long-body-cradle__fit-e586ab4ff6__print-right-cheek.stl, part-solder-modules-tweezers__v8__long-body-cradle__fit-e586ab4ff6__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]
2026-10-01 Publish tweezers v9 as a development build
    v8's tool cradles, unchanged where the tweezers reach (zero volume difference
    left of X = 0.5 mm; tools stay >= 3.02 mm from added material), carried to a
    solid right cheek so the station prints on its side. Mount follows the fit
    study: PF02 coupon 9 hooks on top, loose bearing pegs on rows 2 and 4, one
    cheek-rotated spring latch per column on row 6. Not yet physically tested.
    New page gallery/tweezers/v9.html (linked from the v8 page as "v9 in
    development"); STEP files in the tweezers-v9-dev-2026-10-01 pre-release and
    mapped in release-downloads; additions recorded and checked by
    tools/check_gallery.py; manifest regenerated. Source stays on branch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
    [part-solder-modules-tweezers__v9__cheek-cradle__fit-pf02c9-latch__print-right-cheek.stl]
2026-10-01 Build compact tips-down tweezers v10 on the actual right cheek
    [fit-pf02-clamp-0.49.scad, part-solder-modules-tweezers__v10__compact-right-cheek__fit-9328ccc5d4__print-right-cheek.stl, part-solder-modules-tweezers__v10__sin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]
2026-10-04 Remount 38 gallery holders with current pegs and flatten Pegstr print tops
    [conformal_120.step, part-barrels__current-mounts-v1__fit-pf02c9-hoop5__installed.stl, part-barrels__current-mounts-v1__fit-pf02c9-hoop5__print-upright.stl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]
2026-10-04 Publish six new solder-station designs with CAD and print notes
    [part-rectangular-tool-funnel__v3__upright__fit-pf02c9-hoop5__installed.stl, part-rectangular-tool-funnel__v3__upright__fit-pf02c9-hoop5__print-upright.stl, par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]
2026-10-04 Feature native peg connectors with joining nubs and simplify project navigation
2026-10-06 Clarify product routes and add three FDM-oriented bespoke holders
    [part-cl01__v1__right-cheek__fit-pf02c9-hoop5__installed.stl, part-cl01__v1__right-cheek__fit-pf02c9-hoop5__print.stl, part-hx01__v1__upright__fit-pf02c9-hoop5_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]
2026-10-06 Add touching tool funnels cascading from right high to left low
    [part-cf01__v1__upright__fit-pf02c9-hoop5__print.stl]
2026-10-06 Replace CF01 front rim bands with plain funnel mouths
    [part-cf01__v2__upright__fit-pf02c9-hoop5__print.stl]
2026-10-06 Place CF01 v2 in the Repro bespoke holder collection
    [part-cf01__v2__upright__fit-pf02c9-hoop5__installed.stl, part-cf01__v2__upright__fit-pf02c9-hoop5__print.stl]
2026-10-06 Remove CF01 projecting side fins and publish reviewed v3 model
    [part-cf01__v3__upright__fit-pf02c9-hoop5__installed.stl, part-cf01__v3__upright__fit-pf02c9-hoop5__print.stl]
2026-10-06 Add full-depth 30-degree metric hex-key rack to Repro bespoke
    [part-hx02__v1__right-cheek__fit-pf02c9-hoop5__installed.stl, part-hx02__v1__right-cheek__fit-pf02c9-hoop5__print.stl]
2026-10-07 Publish HX02 v2: graduated organ-pipe hex-key rack with print-shaped finish
    Same contract as v1 (nine full-depth 30-degree sockets, owner lengths, right-cheek print).
    v2 finish: graduated fluted pipes (3 mm walls, crisp 100-degree valleys), smooth monotone
    underside, droplet countersinks, oblique-cut size numerals on the top and pipe faces, V-reveals,
    fillets where the print allows, 50-degree bed chamfers, inset V borders and a flush +X plug.
    Native volume 577 cm3 (v1 813); local P1S/PolyLite ASA ReproCal slice 14h44m, 333 g (v1 345 g).
    CAD, withdrawal, floors, print geometry, installation, stiffness and slice checks pass;
    physical tests pending. v1 stays linked as history.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
    [part-hx02__v2__right-cheek__fit-pf02c9-hoop5__installed.stl, part-hx02__v2__right-cheek__fit-pf02c9-hoop5__print.stl]
2026-10-08 Publish HX04 v1: three-tier key fan for hex, Torx and T-handle keys
    Hex L-keys 1.5-10 at the back (seated deeper toward the long keys), Torx
    T10-T50 in the middle, Bondhus T-handles 2-10 fanned in front with evenly
    spaced grips. Seats are at least 4x the key; each bore is a short neck,
    a slight flare and a floor sloped 30 degrees toward the side the tool's
    weight tips it, so jiggled tools walk in. T3 and up sit in hex-keyed
    bores. Prints on its left end with a mirrored PF02 #9 / PF07 #5 receiver.
    Exact storage and straighten-then-lift withdrawal checks, floors, print
    geometry, solid-ASA stiffness and local slices pass; physical tests are
    pending. The page ships the print STL and a fit coupo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
    [part-hx04__v1__left-cheek__fit-pf02c9-hoop5__coupon_print.stl, part-hx04__v1__left-cheek__fit-pf02c9-hoop5__installed.stl, part-hx04__v1__left-cheek__fit-pf02c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]
2026-10-08 Publish HX04 v2: full peg grid and brace-type solid zones
    Owner review of v1: the mount needs hook pegs every inch, locking pegs on
    the very bottom row and gravity-load pegs in every other hole. v2 places
    the reviewed, unchanged peg profiles on every hole the plate covers: 9
    PF02 #9 hooks across the top row, 9 PF07 #5 locking hoops across the
    bottom row and 72 lower bearing pegs between, rooted in the reviewed
    5.4 mm wall. A sampled install swing over all 90 pegs shows them seated
    clear with the hoops snapping; bearing pegs graze hole edges by at most
    0.21 mm3 each in the last degrees. Stiffness on the pegs alone rises
    from 307 to 3740 N/mm at the weakest load case.
    The solid-infill helpers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
    [part-hx04__v1__left-cheek__fit-pf02c9-hoop5__coupon_print.stl, part-hx04__v2__left-cheek__fit-pf02c9-hoop5__coupon_print.stl, part-hx04__v2__left-cheek__fit-pf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]
2026-10-09 WIP HX05: T-only single-set T-handle rack mode + pipeline speedups
    Based on HX04 v2 (origin/main 2d509de). Adds a single-set "T-only" fan mode
    to study/short.py and build_short.py for the three Bondhus T-handle sets
    (33034 Torx, 13189 metric, 13190 inch), per-set tee data JSONs, the
    tools/hx05_rack.sh driver, and Legolas's pipeline speedups (coarser FEA mesh,
    coupon built inside the main build, wider check step, parallel swing/coupon
    slicing).
    Known-incomplete: fan layouts come out too deep off the board
    (HX05A 246mm / HX05B 285mm / HX05C 507mm vs HX04's 178mm) -- layout approach
    unresolved. NOTE: cachy main (7d7b2fc "native peg connectors") has diverged and
    reworked the same pipeline files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
2026-10-09 Resolve HX05 rack depth with validated staggered rows and isolate HX04 sources
    Use catalogue lengths and equal 48 mm grip spacing to reduce sampled loaded depths to 142.7, 151.8 and 152.0 mm. Verify fixed forward routes at five clock-play poses with dense samples. Restore published HX04 source hashes and move HX05 into tee_racks_v1. Prepare bounded one-command Windows FreeCAD review; native builds and physical qualification remain pending.
2026-10-09 Halve hex clearance and clock T-bars flat-to-flat with a native fit coupon
    Apply owner corrections: 0.10 mm clearance per flat and flat-to-flat handle axis. Recheck all three fixed layout routes. Set up checksum-pinned local FreeCAD 1.1.3 and export a separate straight-guide coupon for L2, T2.5 and T5 with shallow lead-ins and square floors. Native solids, rotational stops, STEP, FCStd and closed mesh checks pass; actual slicing and physical fit remain pending. Preserve published HX04 sources and record owner feedback plus the native old-seat audit.
    [HX05-fit-v2.FCStd, HX05-fit-v2__left-end__print.step, HX05-fit-v2__left-end__print.stl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]
2026-10-09 Publish 40 mm shaft-guide fit trial and archive the earlier key-fan seats
    Apply the owner rule of at least 40 mm straight shaft hug, increasing to 8x shaft size, with an additional 0.8 mm entrance. Preserve half-clearance and flat-to-flat handles. Build and verify the four-block coupon locally in FreeCAD, verify all three native rack bodies, and recheck dense layouts at 168/178/178 mm depth. Put the new trial and native/source downloads first on the key-fan page, record failed original socket fit and keep the HX04 v2 rack clearly archived. Full-rack exact movement, FEA, actual slicing and physical qualification remain pending.
    [HX05-fit-v3.FCStd, HX05-fit-v3__left-end__print.step, HX05-fit-v3__left-end__print.stl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]
2026-10-09 Publish vented fit coupon v4 with 0.18 mm additional total clearance
    [HX05-fit-v4.FCStd, HX05-fit-v4__left-end__print.step, HX05-fit-v4__left-end__print.stl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]
2026-10-10 Publish three angle-matched five-slot hex fit spectra
    [HX05-fit-v5-3mm__rack-angle__print.step, HX05-fit-v5-3mm__rack-angle__print.stl, HX05-fit-v5-5mm__rack-angle__print.step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]
2026-10-10 Correct fit spectra to actual HX04 fan print frames
    [HX05-fit-v6-3mm__fan-angle__print.step, HX05-fit-v6-3mm__fan-angle__print.stl, HX05-fit-v6-5mm__fan-angle__print.step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]
2026-10-10 Checkpoint HX04 extended FEA and full-host motion audit
    [HX04-v2__uncompensated-brace-project__reslice.3mf]
2026-10-10 Add HX04 engineering lab with 60 computed motion and FEA films
    [HX04-fit-v6__3mm-5mm__fan-angle__print.step, HX04-fit-v6__3mm-5mm__fan-angle__print.stl]
2026-10-10 Publish final straight-socket fan and Bondhus racks with selected C fits
2026-10-10 Tuck small Bondhus keys into clearance-limited fan gaps
2026-10-10 Review longer green fan sleeves and flatter pinch-access handles
2026-10-11 Fill green fan bending planes and add rounded tip-face print base
2026-10-11 Keep fan keys above ten degrees and broaden fin gussets
2026-10-11 Add editable parametric FreeCAD handoff for green fan
2026-10-11 Publish front shaft X-ray and validated print STEP downloads
2026-10-12 Publish finished Bondhus fans with fixed print pose and solid-infill modifiers
2026-10-12 Halve Bondhus rack print mass with thin solid reinforcement zones
